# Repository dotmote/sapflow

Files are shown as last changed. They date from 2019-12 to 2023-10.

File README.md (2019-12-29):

# Sapflow Using the External Heat Ratio Method

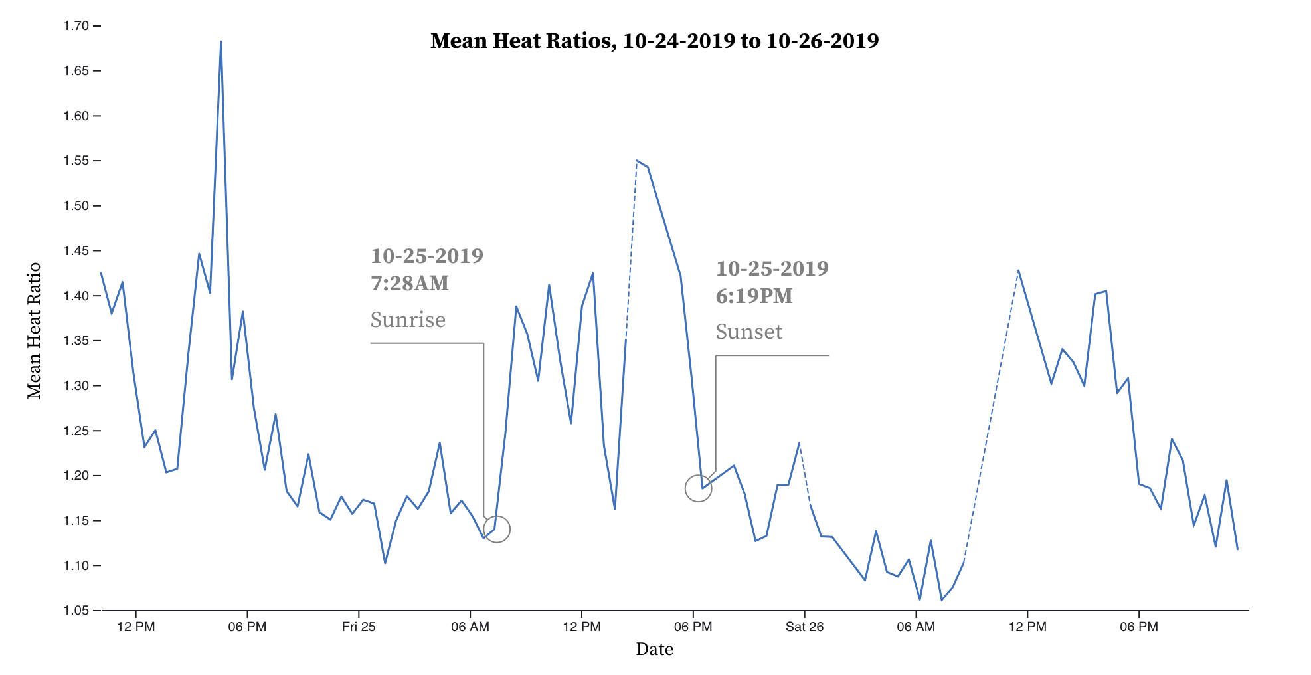
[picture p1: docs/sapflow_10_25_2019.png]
sapflow chart


So you want to measure sapflow in plants? You and me both, buddy. The goal of this project is to create an open-source, accurate, robust, low-cost, and low-power system to help answer the age-old question: "How is my plant doing?"

## Getting Started
Take a look at the hardware and software sections below for instructions on what you'll need to set up your own system and join in on improving the project.

## Hardware

### Sapflow Gauge
First, you'll need a way to measure and record the temperature at two specific points (equidistant from a central heating element) along the stem of your plant:

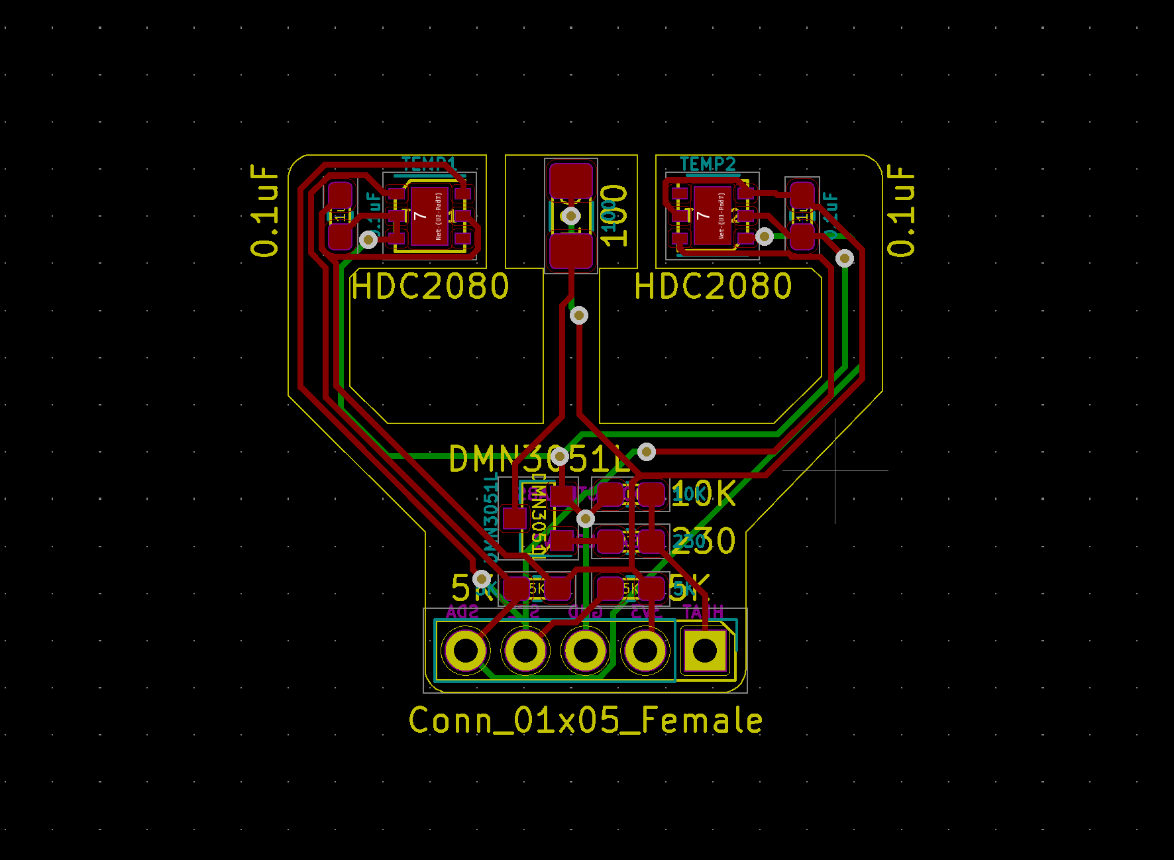
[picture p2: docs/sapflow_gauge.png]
sapflow gauge board


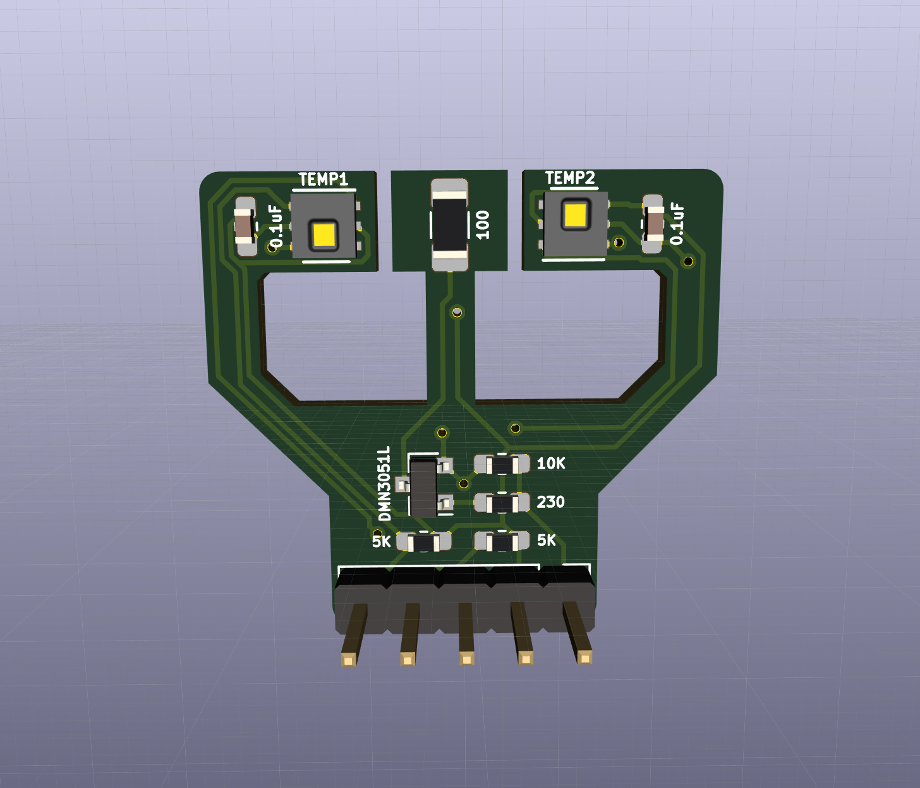
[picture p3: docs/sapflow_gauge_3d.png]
sapflow gauge 3d


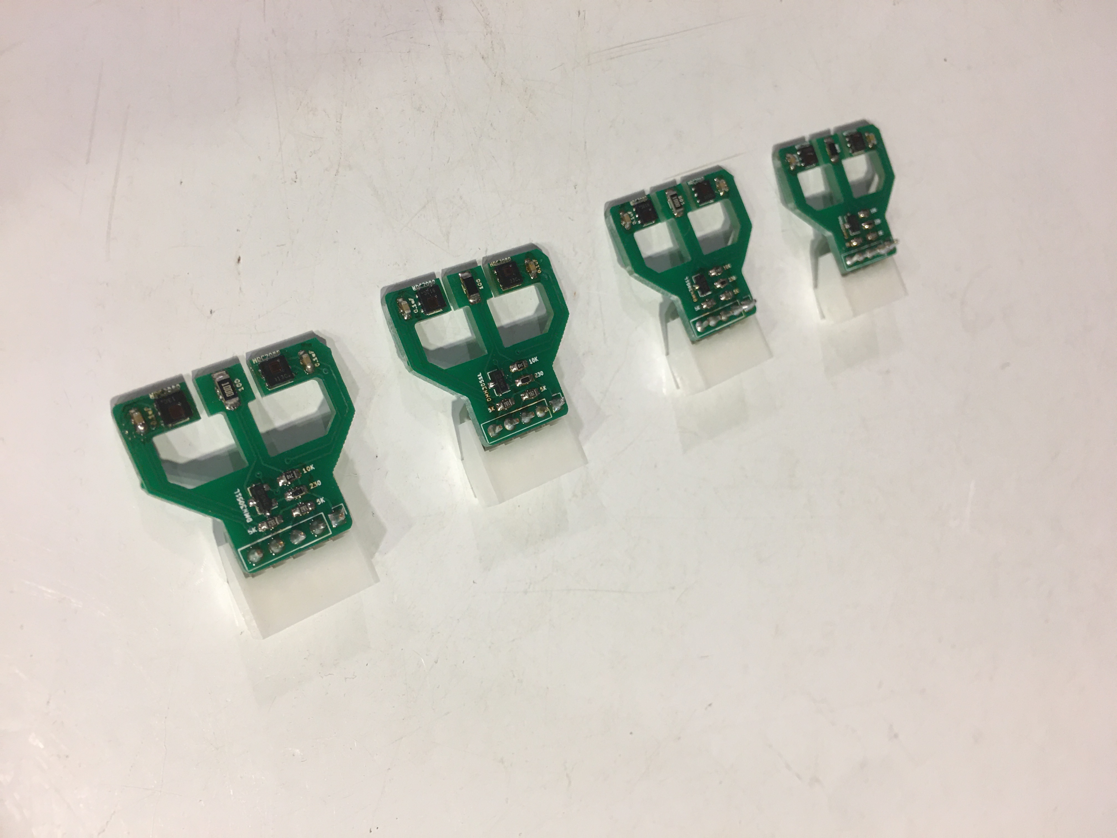
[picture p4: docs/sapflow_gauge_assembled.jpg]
assembled sapflow gauge


To build the gauge, you'll need: (1) the PCB; and (2) the components.

#### Fabricate the PCB
See here for the [KiCad PCB files](/hardware/sapflow_gauge/kicad/sapflow_gauge). Follow the directions from your favorite PCB fabrication service (e.g., OSHPark, JLCPCB, Seeed Studio, etc.), and order your desired quantity of PCBs.

#### Gather the Parts
See here for the [parts list](/hardware/sapflow_gauge/sapflow_gauge_parts.md). Go to your favorite electronic components distributor (e.g., Digikey, Arrow, Mouser, etc.) and order your desired quantity of components.

### Microcontroller
Second, you'll need a microcontroller that has an available GPIO pin (3.3V to 5V) and can communicate via I2C. We've found the ESP32 (specifically, the [LOLIN D32 Pro](https://www.aliexpress.com/item/32883116057.html) dev board) to be great for rapid prototyping with its relatively large onboard RAM, built-in WiFi, and low cost. For field experiments, it might make more sense to use a board with more low-power optimizations.

#### Microcontroller Shield
To reduce wiring, you might want to use a shield to interface your microcontroller with the sapflow gauge connector. See [here](/hardware/microcontroller_shield/d32_pro/d32_shield.md) for our shield design for the D32 Pro.

## Software

### Microcontroller Firmware
You'll need software running on your microcontroller to read data from the connected sapflow gauge. See [here](/software/microcontroller/d32_pro) for the Arduino code we used for the D32 Pro.

### Edge Compute Node
If you're using microcontrollers with WiFi connectivity, it's very convenient to have all of the data streaming into a single place. We like using a Raspberry Pi as an [MQTT](https://mosquitto.org/) broker, collecting data points from all of the networked sensor devices. See [here](/software/edge_compute_node/raspberry_pi) for more info.

## Data Visualization

Visualize your hard-earned data with this [Observable notebook](https://observablehq.com/d/a2d68ed97662840b).

Raw data:
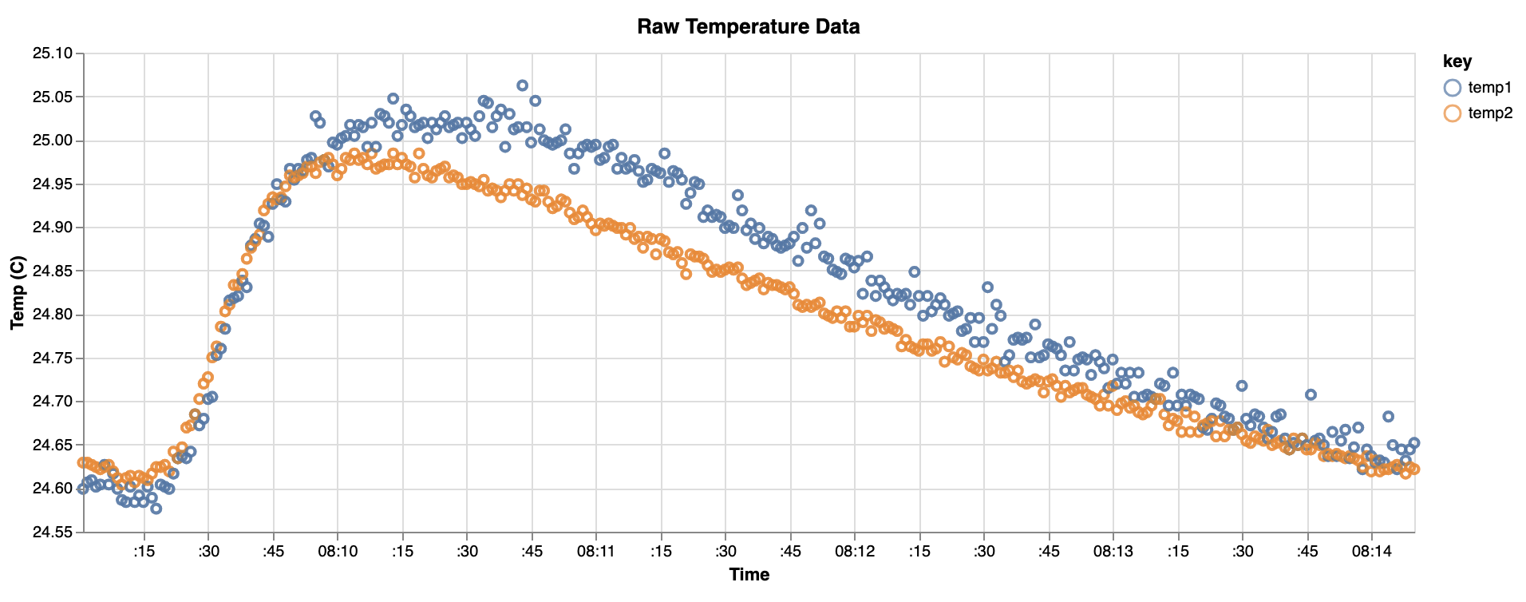
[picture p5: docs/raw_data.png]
sapflow raw data


After processing:
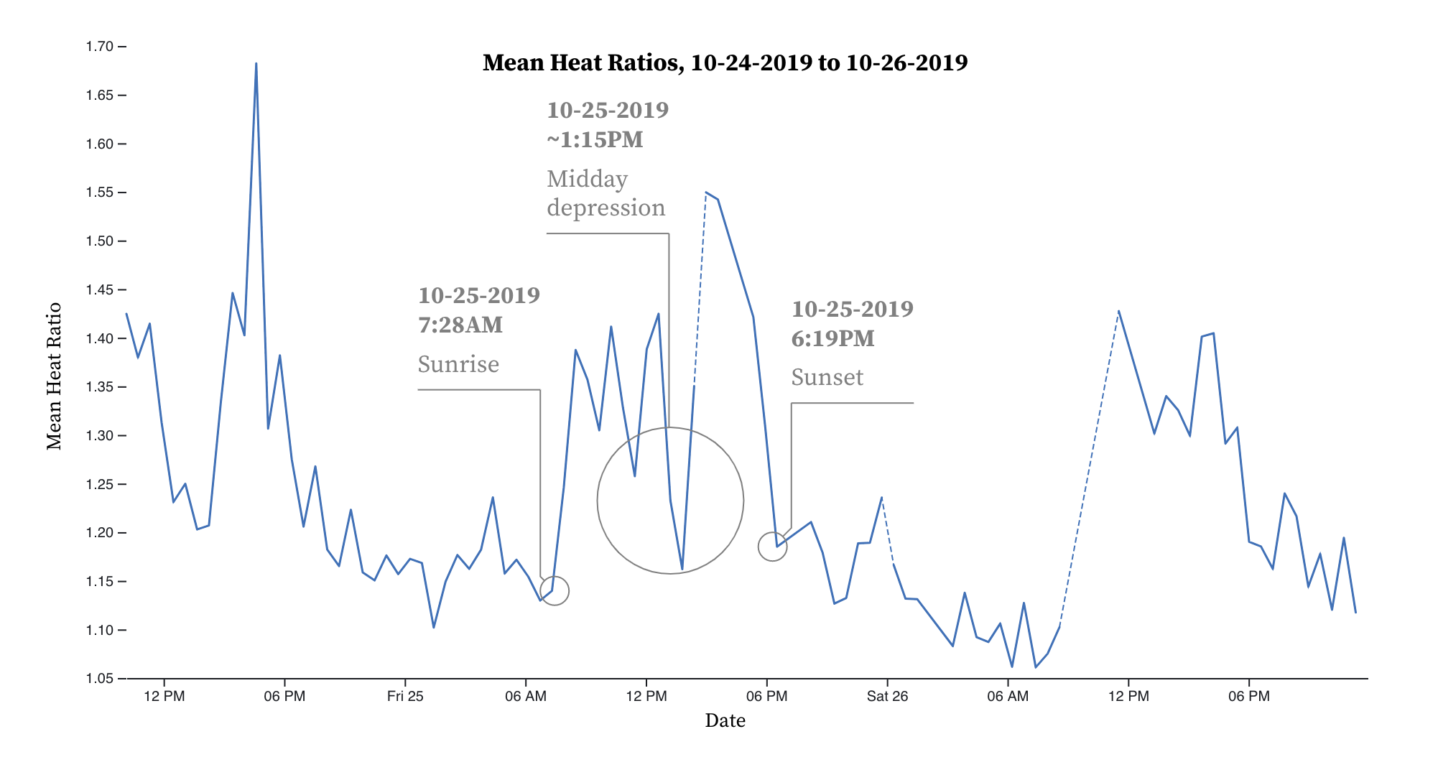
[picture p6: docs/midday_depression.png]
sapflow diurnal showing midday depression


## References
We've stood on the shoulders of countless giants in working on this project. Below is a non-exhaustive list of the many previous efforts that we drew heavily from (let us know who we've missed and we'll make sure to add them):

### Sapflow
- Burgess, S.S.O., Adams, M.A., Turner, N.C., Beverly, C.R., Ong, C.K., Khan, A.A.H., and Bleby, T.M. (2001). An improved heat pulse method to measure low and reverse rates of sap flow in woody plants. Tree Physiology 21, 589–598. 
- Clearwater, M.J., Luo, Z., Mazzeo, M., and Dichio, B. (2009). An external heat pulse method for measurement of sap flow through fruit pedicels, leaf petioles and other small-diameter stems. Plant, Cell & Environment 32, 1652–1663.
- Marshall, D.C. (1958). Measurement of Sap Flow in Conifers by Heat Transport. Plant Physiol. 33, 385–396.
- Skelton, R. (2017). Miniature External Sapflow Gauges and the Heat Ratio Method for Quantifying Plant Water Loss. BIO-PROTOCOL 7.

### Open-Source Research Tools
- Chris Lucani & Team @ Brodribb Lab, University of Tasmania: [Open Source OV](http://www.opensourceov.org/).
- OPEnS Lab, Oregon State University: [Sap Flow Meter](https://github.com/OPEnSLab-OSU/OPEnS-Lab-Home/wiki/Sap-Flow-Meter).

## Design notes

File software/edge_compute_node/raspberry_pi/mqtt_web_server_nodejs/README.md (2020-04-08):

# MQTT  + Web Server

## Overview
This script subscribes to the MQTT broker running on the Raspberry Pi and writes the incoming messages to CSV files in a `/data` directory, creating a new CSV file each hour. This script serves a web app at port 4000 of the Raspberry Pi's IP address (e.g., 192.168.1.2:4000). The web app can also be accessed at http://sapflow.local:4000 for devices that support mDNS.

## Setup and running the script
1. `cd` into the directory.
2. Run `$ npm install` to install the dependencies for this MQTT broker + web server.
3. Edit `.env.sample` and add your Dotmote API key.
4. Rename `.env.sample` to `.env`.
5. `$ cd frontend`.
6. Run `$ npm install` to install the dependencies for the web app.
7. Run `$ npm run build` to build the web app.
8. `cd ..` to return to the server directory.
9. Run `$ node index.js`.

## Running the script
1. Ensure that you are in the same directory as the script `index.js` to run the script

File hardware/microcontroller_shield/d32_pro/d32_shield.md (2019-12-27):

# D32 Pro Sapflow Shield
This shield's header pins are laid out to interface with:
- [Adafruit DS3231 RTC breakout](https://www.digikey.com/product-detail/en/adafruit-industries-llc/3013/1528-1598-ND/5875808)
- Sapflow gauge connector
- Soil moisture sensor

## GPIO
- IO26 = heating element on/off
- IO34 = soil moisture sensor analog read
- IO25 = soil moisture sensor digital alarm

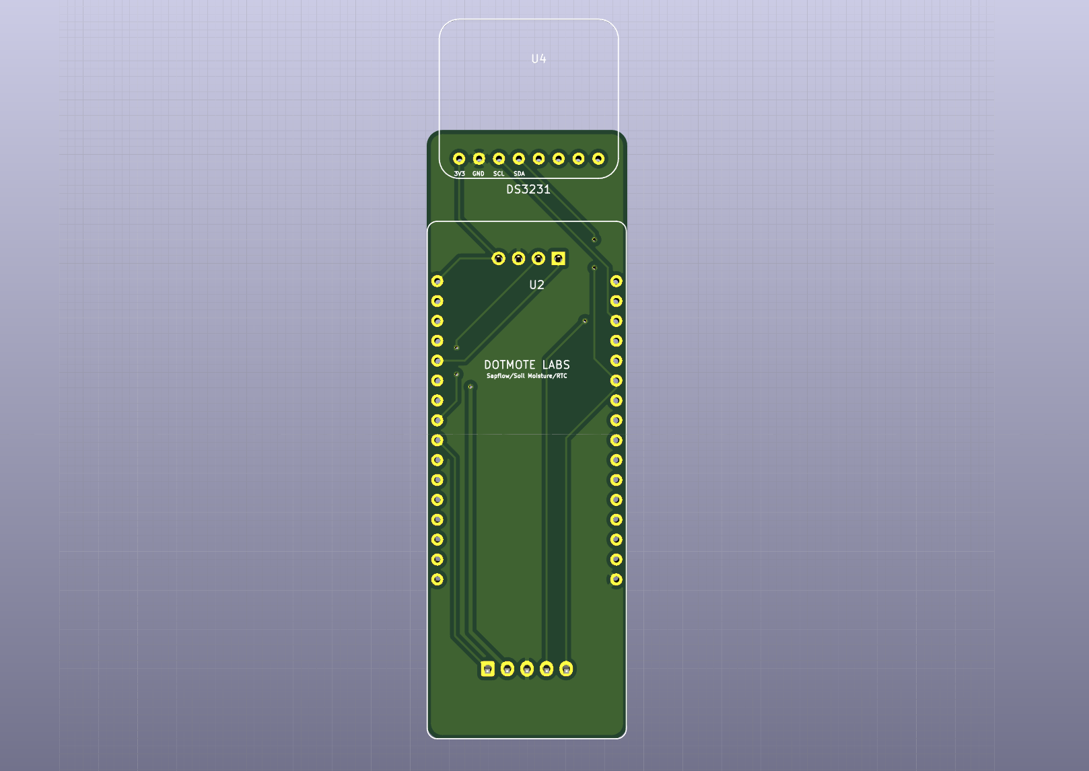
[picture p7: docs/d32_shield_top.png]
d32 pro sapflow shield top

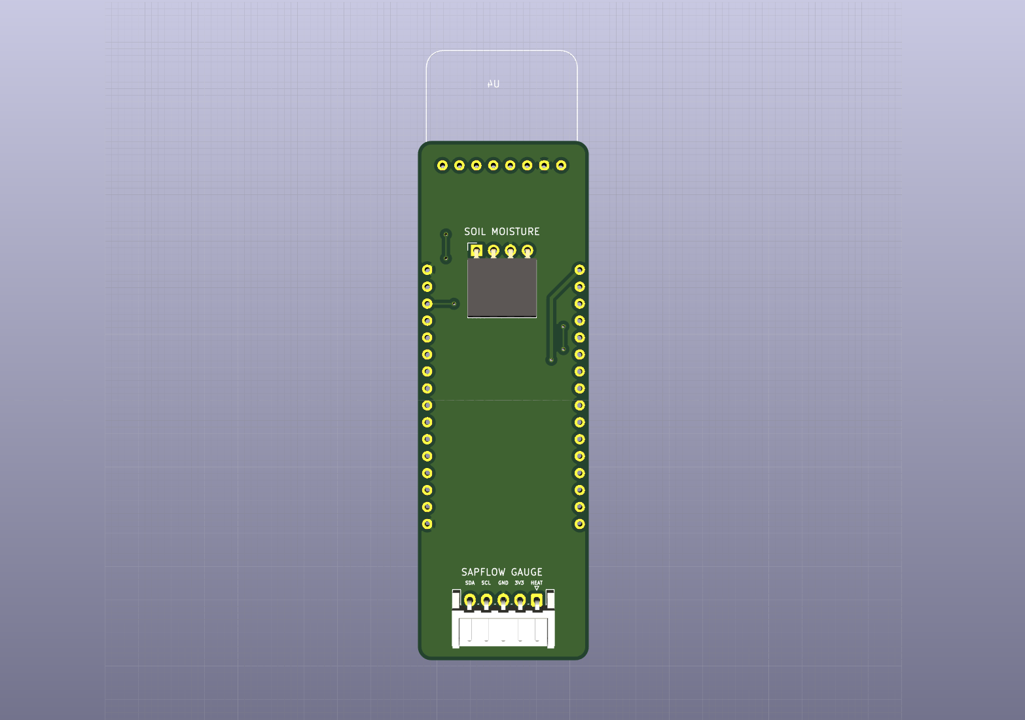
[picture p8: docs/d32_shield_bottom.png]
d32 pro sapflow shield bottom


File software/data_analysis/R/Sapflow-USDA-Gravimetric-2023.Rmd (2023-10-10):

---
title: "Sapflow - USDA Fieldtrial - August 2023"
author: "Aji John@DotMote Labs"
date: "08/20/2023"
output:
  pdf_document: default
  html_document: default
---

# Running notebook for the Sapflow data captured by Sapflow nodes (DotmoteLabs)

## 50 - Bowen F2 - Full irrigated
## 51 - Bowen F2 - Full irrigated
## 52 - Bowen F2 - Full irrigated

## 57 - Bowen L1 - Limited irrigation (70%)
## 58 - Bowen L1 - Limited irrigation (70%)
## 59 - Bowen L1 - Limited irrigation (70%)

```{r , include=FALSE}
knitr::opts_chunk$set(echo = TRUE)
```

## Introduction 

Sapflow measurements help with tree water use that can be extended to canopy level transpiration assessments.

```{r }
library(knitr)
library(tidyverse)
library(lubridate)
```

## Load helper functions

```{r, include=FALSE}
## Summarizes data.
## Gives count, mean, standard deviation, standard error of the mean, and confidence interval (default 95%).
##   data: a data frame.
##   measurevar: the name of a column that contains the variable to be summariezed
##   groupvars: a vector containing names of columns that contain grouping variables
##   na.rm: a boolean that indicates whether to ignore NA's
##   conf.interval: the percent range of the confidence interval (default is 95%)
summarySE <- function(data=NULL, measurevar, groupvars=NULL, na.rm=FALSE,
                      conf.interval=.95, .drop=TRUE) {
    library(plyr)

    # New version of length which can handle NA's: if na.rm==T, don't count them
    length2 <- function (x, na.rm=FALSE) {
        if (na.rm) sum(!is.na(x))
        else       length(x)
    }

    # This does the summary. For each group's data frame, return a vector with
    # N, mean, and sd
    datac <- ddply(data, groupvars, .drop=.drop,
      .fun = function(xx, col) {
        c(N    = length2(xx[[col]], na.rm=na.rm),
          mean = mean   (xx[[col]], na.rm=na.rm),
          sd   = sd     (xx[[col]], na.rm=na.rm)
        )
      },
      measurevar
    )

    # Rename the "mean" column    
    datac <- rename(datac, c("mean" = measurevar))

    datac$se <- datac$sd / sqrt(datac$N)  # Calculate standard error of the mean

    # Confidence interval multiplier for standard error
    # Calculate t-statistic for confidence interval: 
    # e.g., if conf.interval is .95, use .975 (above/below), and use df=N-1
    ciMult <- qt(conf.interval/2 + .5, datac$N-1)
    datac$ci <- datac$se * ciMult

    return(datac)
}

```

## Datalog

```{r pressure, echo=FALSE}
sapflow_usda_2023_datalog_51<-  read_csv('./data/usda/20230823/datalog.csv')
# Tell R studio that timestamp is already in MDT
sapflow_usda_2023_datalog_51$dateP <- as_datetime(sapflow_usda_2023_datalog_51$rtcUnixTimestamp, tz="America/Denver")

```

One day
```{r pressure, echo=FALSE}
 sapflow_usda_2023_datalog_51%>%
  mutate(mr = temp2/temp1) %>%
  mutate(node = as.factor(nodeId),Vh = log(mr),hr = hour(dateP),dy = day(dateP)) %>%
      filter(dy %in% c(14)) %>%
  #filter(nodeId %in% c("sapflow-dotmote-labs-2" ,"sapflow-dotmote-labs-3", "sapflow-dotmote-labs-4","sapflow-dotmote-labs-5")) %>%
  ggplot() + 
  geom_smooth(aes(hr,temp2) ,color="blue")  +
    geom_smooth(aes(hr,temp1) ,color="red")  +
  #facet_grid(~node) +
  theme_classic() + labs(x="Time (Hour)",y="Temperature (deg C)", title = "Node 51 USDA - Gravimetric Maize(2023)", caption="Source : dotmotelabs.com") +
    theme(axis.text.x = element_text(angle = 90, hjust = 1))
```

## Verify the input files of heat ratio

```{r pressure, echo=FALSE}
sapflow_usda_2023_hr_51<-  read_csv('./data/usda/20230823/heatlog.csv')
# Tell R studio that timestamp is already in MDT
sapflow_usda_2023_hr_51$dateP <- as_datetime(sapflow_usda_2023_hr_51$rtcUnixTimestamp, tz="America/Denver")
sapflow_usda_2023_hr_51$datePMinus90 <- as_datetime(sapflow_usda_2023_hr_51$rtcUnixTimestampMinus90, tz="America/Denver")

```

## Verify the input files

```{r pressure, echo=FALSE}

```

## Run summary analysis

```{r }
sapflow_usda_hr_2023 <-  rbind(sapflow_usda_2023_hr_51)

```

## Plot the raw heat ratio data 

```{r }
sapflow_usda_hr_2023 %>% mutate(meanhr = meanHeatRatio) %>%
  filter(!meanhr =='NaN') %>% mutate(mr=as.numeric(meanhr)) %>%
     mutate(node = as.factor(nodeId),Vh = log(mr),hr = hour(dateP),yr = year(dateP),dy = day(dateP)) %>%
   #  filter(date(dateP) > "2023-08-19" & date(dateP) < "2023-08-21" ) %>%
  #filter(nodeId %in% c("sapflow-dotmote-labs-2" ,"sapflow-dotmote-labs-3", "sapflow-dotmote-labs-4","sapflow-dotmote-labs-5")) %>%
  ggplot() + geom_point(aes(hr,1/mr,color=node) )  +
  facet_grid(~dy) +
  theme_classic() + labs(x="Date",y="Mean HR", title = "Node 51 USDA - Gravimetric Maize (2023)", caption="Source : dotmotelabs.com") +
    theme(axis.text.x = element_text(angle = 90, hjust = 1))
  
```
Lot oisier on 19,20 and 21

```{r }
sapflow_usda_hr_2023 %>% mutate(meanhr = meanHeatRatio) %>% filter(meanhr <5) %>%
  filter(!meanhr =='NaN') %>% mutate(mr=as.numeric(meanhr)) %>%
     mutate(node = as.factor(nodeId),Vh = log(mr),hr = hour(dateP),dy = day(dateP)) %>%
      filter(dy %in% c(14,15,16,17)) %>%
  #filter(nodeId %in% c("sapflow-dotmote-labs-2" ,"sapflow-dotmote-labs-3", "sapflow-dotmote-labs-4","sapflow-dotmote-labs-5")) %>%
  ggplot() + geom_point(aes(hr,1/mr,color=as.factor(dy)) )  +
  #facet_grid(~node) +
  theme_classic() + labs(x="Date",y="Mean HR", title = "Node 516 USDA - Gravimetric Maize(2023)", caption="Source : dotmotelabs.com") +
    theme(axis.text.x = element_text(angle = 90, hjust = 1))
  
```

## change the column names

```{r , echo=TRUE}
colnames(sapflow_usda_hr_2023) <- c("meanHeatRatio" ,"rtcUnixTimestamp", "rtcUnixTimestampMinus90", "nodeId" ,         "dateP" , "datePMinus90" )

```

## Verify diurnal 

## Do zero offsetting 

Plot alternatively, but do offsetting by zeroing out the heatratio by using the values from hrs 0,1 and 2. Assumption being around hours (0-2), ideally no sapflow in plants.

```{r , echo=TRUE}

usda_51_offset <- sapflow_usda_hr_2023 %>%  mutate(meanhr = meanHeatRatio,hr = hour(dateP) ,dy = day(dateP)) %>%
  filter(!meanhr =='NaN') %>% 
  filter(nodeId %in% c("sapflow-usda-51"))  %>% 
  filter( hr %in% c(0,1,2)) %>% 
  filter(dy %in% c(14,15,16,17)) %>%
  summarise(mhr = mean(meanhr))

sapflow_usda_2023_adjusted <- sapflow_usda_hr_2023
sapflow_usda_2023_adjusted$hr = hour(sapflow_usda_hr_2023$dateP)
sapflow_usda_2023_adjusted$mr <- 0

sapflow_usda_2023_adjusted[sapflow_usda_2023_adjusted$nodeId == "sapflow-usda-51",]$mr =  sapflow_usda_2023_adjusted[sapflow_usda_hr_2023$nodeId == "sapflow-usda-51",]$meanHeatRatio + (1-as.numeric(usda_51_offset))

#SE 
sapflow_usda_2023_adjusted_se <- summarySE(sapflow_usda_2023_adjusted, measurevar="mr", groupvars=c("nodeId","hr"))

# TODO VPD SE

```

## Plot the adjusted with original 

```{r , echo=TRUE}

sapflow_usda_hr_2023 %>% 
  mutate(node = as.factor(nodeId),hr = hour(dateP),dy = day(dateP)) %>%
  mutate(mr = meanHeatRatio) %>%
    filter(dy %in% c(14,15,16,17)) %>%
  ggplot() + geom_point(aes(hr,1/mr,color=node) )  +
  facet_grid(~nodeId) +
  theme_classic() + labs(x="Date",y="Mean HR", title = "Node 7-10 USDA - Gravimetric Maize", caption="Source : dotmotelabs.com") +
    theme(axis.text.x = element_text(angle = 90, hjust = 1))

```

```{r , echo=TRUE}

sapflow_usda_2023_adjusted %>% filter(1/mr >0) %>%
  mutate(node = as.factor(nodeId),hr = hour(dateP),dy = day(dateP)) %>%
     filter(dy %in% c(14,15,16,17)) %>%
  ggplot() + geom_point(aes(hr,1/mr,color=node) )  +
  facet_grid(~nodeId) +
  theme_classic() + labs(x="Date",y="Mean HR", title = "Node 7-10 USDA - Gravimetric Maize", caption="Source : dotmotelabs.com") +
    theme(axis.text.x = element_text(angle = 90, hjust = 1))

```

## Compare Original and Adjusted HR

```{r , echo=TRUE}

summary(lm(sapflow_usda_2023_adjusted$meanHeatRatio~sapflow_usda_2023_adjusted$mr))

sapflow_usda_2023_adjusted %>% 
  ggplot() +
  geom_point(aes(meanHeatRatio,mr,color=nodeId)) +
  theme_minimal(base_size = 14)
```

## Heat pulse velocity

```{r , echo=TRUE}

sapflow_usda_2023_adjusted %>% mutate(yr = year(dateP),mth = month(dateP),dy  = day(dateP),hr = hour(dateP)) %>%
  filter(yr %in% c(2023) & mth %in% c(08) & dy %in% c(14:17)) %>%
  mutate (sv = log(1/mr) *3600 * (0.0025/0.6) ,daten = date(dateP))%>% 
#        filter(date(dateP) == "2020-12-01" ) %>%
 # filter(nodeId=="sapflow-dotmote-labs-2" )  %>% 
  ggplot() +
   geom_point(aes(x = dateP, y=sv,color=nodeId)) +
   geom_line(aes(x = dateP, y=sv,color=nodeId)) +
    theme_minimal() + scale_x_datetime(date_minor_breaks = "1 day") + 

  scale_y_continuous(
    # Features of the first axis
    name = expression(~V[h] (cm~h^{"-1"}))

  ) +
  facet_wrap(.~dy) +
  theme(legend.position = c(.17, .6))+
guides(fill = guide_legend(keywidth = 1, keyheight = 1),
    linetype=guide_legend(keywidth = 3, keyheight = 1))

```
## Smooth

```{r , echo=TRUE}

sapflow_usda_2023_adjusted %>% mutate(yr = year(dateP),mth = month(dateP),dy  = day(dateP)) %>%
  filter(yr %in% c(2023) & mth %in% c(08) & dy %in% c(14:17)) %>%
  mutate (sv = log(1/mr) *3600 * (0.0025/0.6) ,daten = date(dateP))%>%
  #filter(date(dateP) == "2021-03-20" ) %>%
 # filter(nodeId=="sapflow-dotmote-labs-2" )  %>% 
  ggplot() +
   geom_point(aes(x = hr, y=sv,color=nodeId)) +
  geom_smooth(aes(x = hr, y=sv,color=nodeId)) +
    theme_minimal() + 
  #scale_x_datetime(date_minor_breaks = "1 day") + 

  scale_y_continuous(
    # Features of the first axis
    name = expression(~V[h] (cm~h^{"-1"}))

  ) +
  facet_wrap(~date(dateP) ) +

  theme(legend.position = "bottom")+
guides(fill = guide_legend(keywidth = 1, keyheight = 1),
    linetype=guide_legend(keywidth = 3, keyheight = 1))
ggsave("figs/usda-graivimetric-Maize-vh-smoothed-2023.png", width = 20, height = 20, units = "cm")

```

## Heat pulse velocity 1 to 15

```{r , echo=TRUE}

sapflow_usda_2023_adjusted %>% mutate(yr = year(dateP),mth = month(dateP),dy  = day(dateP)) %>%
  filter(yr %in% c(2023) & mth %in% c(08) & dy %in% c(14:17)) %>%
  mutate (sv = log(1/mr) *3600 * (0.0025/0.6) ,daten = date(dateP))%>%
#        filter(date(dateP) == "2020-12-01" ) %>%
  #        filter(date(dateP) >= "2021-12-15" ) %>%
  # filter(date(dateP) <= "2021-12-24" ) %>%
 # filter(nodeId=="sapflow-dotmote-labs-2" )  %>% 
  ggplot() +
   geom_point(aes(x = dateP, y=sv,color=nodeId)) +
   geom_line(aes(x = dateP, y=sv,color=nodeId)) +
    theme_minimal() + scale_x_datetime(date_minor_breaks = "1 day") + 

  scale_y_continuous(
    # Features of the first axis
    name = expression(~V[h] (cm~h^{"-1"}))

  ) +
  theme(legend.position = c(.17, .6))+
    labs(color='Node ID',x="Time (Date)") +
guides(fill = guide_legend(keywidth = 1, keyheight = 1),
    linetype=guide_legend(keywidth = 3, keyheight = 1))
ggsave("figs/usda-graivimetric-Maize-stress-event-2023.png", width = 20, height = 20, units = "cm")

```

## Mass flow

```{r , echo=TRUE}

sapflow_usda_2023_adjusted %>% mutate(yr = year(dateP),mth = month(dateP),dy  = day(dateP)) %>%
  filter(yr %in% c(2023) & mth %in% c(08) & dy %in% c(14:17)) %>%
  mutate (sv = log(1/mr) *3600 * (0.0025/0.6) ,daten = date(dateP))%>%
            filter(date(dateP) >= "2021-12-15" ) %>%
 #  filter(date(dateP) <= "2021-12-24" ) %>%
   mutate (vs =1.7 * sv )%>% 
   mutate (flow = 3.14 * (1.5)^2 *vs )%>% 
   #     filter(date(dateP) == "2021-03-18" ) %>%
 # filter(nodeId=="sapflow-dotmote-labs-2" )  %>% 
  ggplot() +
   geom_point(aes(x = dateP, y=flow,color=nodeId)) +
   geom_line(aes(x = dateP, y=flow,color=nodeId)) +
    theme_minimal() + scale_x_datetime(date_minor_breaks = "1 day") + 

  scale_y_continuous(
    # Features of the first axis
    #name = expression(~V[h] (cm~h^{"-1"}))
       # Features of the first axis
    name = expression("Sapflow rate"~J~(g~h^{"-1"})),
  ) +
  theme(legend.position = c(.17, .8))+
  labs(color='Node ID',x="Time (Date)") +
guides(fill = guide_legend(keywidth = 1, keyheight = 1),
    linetype=guide_legend(keywidth = 3, keyheight = 1))

```

## Look at one day

## Mass flow

```{r , echo=TRUE}

sapflow_usda_2023_adjusted %>% mutate(yr = year(dateP),mth = month(dateP),dy  = day(dateP)) %>%
  filter(yr %in% c(2023) & mth %in% c(08) & dy %in% c(15:15)) %>%
  mutate (sv = log(1/mr) *3600 * (0.0025/0.6) ,daten = date(dateP))%>%
   #         filter(date(dateP) >= "2021-12-18" ) %>%
   #filter(date(dateP) <= "2021-12-18" ) %>%
   mutate (vs =1.7 * sv )%>% 
   mutate (flow = 3.14 * (1.5)^2 *vs )%>% mutate(ihr = 1/mr) %>% filter( ihr >= 1) %>%
   #     filter(date(dateP) == "2021-03-18" ) %>%
 # filter(nodeId=="sapflow-dotmote-labs-2" )  %>% 
  ggplot() +
   geom_point(aes(x = dateP, y=flow,color=nodeId)) +
   geom_line(aes(x = dateP, y=flow,color=nodeId)) +
    theme_minimal() + scale_x_datetime(date_minor_breaks = "1 day") + 

  scale_y_continuous(
    # Features of the first axis
    #name = expression(~V[h] (cm~h^{"-1"}))
       # Features of the first axis
    name = expression("Sapflow rate"~J~(g~h^{"-1"})),
  ) +
  theme(legend.position = c(.17, .8))+
  labs(color='Node ID',x="Time (Date)") +
guides(fill = guide_legend(keywidth = 1, keyheight = 1),
    linetype=guide_legend(keywidth = 3, keyheight = 1))

```

## Smooth

## Mass flow

```{r , echo=TRUE}

sapflow_usda_2023_adjusted %>% mutate(yr = year(dateP),mth = month(dateP),dy  = day(dateP)) %>%
  filter(yr %in% c(2023) & mth %in% c(08) & dy %in% c(15:15)) %>%
  mutate (sv = log(1/mr) *3600 * (0.0025/0.6) ,daten = date(dateP))%>%
  #          filter(date(dateP) >= "2021-12-18" ) %>%
 #  filter(date(dateP) <= "2021-12-18" ) %>%
   mutate (vs =1.7 * sv )%>% 
   mutate (flow = 3.14 * (1.5)^2 *vs )%>% mutate(ihr = 1/mr) %>% filter( ihr >= 1) %>%
   #     filter(date(dateP) == "2021-03-18" ) %>%
 # filter(nodeId=="sapflow-dotmote-labs-2" )  %>% 
  ggplot() +
   geom_point(aes(x = dateP, y=flow,color=nodeId)) +
   geom_smooth(aes(x = dateP, y=flow,color=nodeId)) +
    theme_minimal() + scale_x_datetime(date_minor_breaks = "1 day") + 

  scale_y_continuous(
    # Features of the first axis
    #name = expression(~V[h] (cm~h^{"-1"}))
       # Features of the first axis
    name = expression("Sapflow rate"~J~(g~h^{"-1"})),
  ) +
  theme(legend.position = c(.17, .8))+
  labs(color='Node ID',x="Time (Date)") +
guides(fill = guide_legend(keywidth = 1, keyheight = 1),
    linetype=guide_legend(keywidth = 3, keyheight = 1))

```
# Multiple dates

```{r , echo=TRUE}

sapflow_usda_2023_adjusted %>% mutate(yr = year(dateP),mth = month(dateP),dy  = day(dateP)) %>%
  filter(yr %in% c(2023) & mth %in% c(08) & dy %in% c(14:18)) %>%
  mutate (sv = log(1/mr) *3600 * (0.0025/0.6) ,daten = date(dateP))%>%
    #        filter(date(dateP) >= "2021-12-15" ) %>%
   #filter(date(dateP) <= "2021-12-28" ) %>%
   mutate (vs =1.7 * sv )%>% 
   mutate (flow = 3.14 * (1.5)^2 *vs )%>% mutate(ihr = 1/mr) %>% filter( ihr >= 1) %>%
   #     filter(date(dateP) == "2021-03-18" ) %>%
 # filter(nodeId=="sapflow-dotmote-labs-2" )  %>% 
  ggplot() +
   geom_point(aes(x = dateP, y=flow,color=nodeId)) +
   geom_line(aes(x = dateP, y=flow,color=nodeId)) +
    theme_minimal(base_size = 18) +
  scale_x_datetime(date_breaks = "1 day",date_labels = "%b %d") + 
  scale_y_continuous(
    # Features of the first axis
    #name = expression(~V[h] (cm~h^{"-1"}))
       # Features of the first axis
    name = expression("Sapflow rate"~J~(g~h^{"-1"})),
  ) +
  #  facet_wrap(~date(dateP) ) +
  theme_minimal(base_size = 18) +
  theme(legend.position = c(.17, .8))+
  labs(color='Node ID',x="Time (Date)" , caption="Source : dotmotelabs.com") +
guides(fill = guide_legend(keywidth = 1, keyheight = 1),
    linetype=guide_legend(keywidth = 3, keyheight = 1))

ggsave("figs/usda-graivimetric-Maize-flow-long-duration-2023.jpg", width = 35, height = 20, units = "cm")

```

```{r , echo=TRUE}

sapflow_usda_2023_adjusted %>% mutate(yr = year(dateP),mth = month(dateP),dy  = day(dateP)) %>%
  filter(yr %in% c(2023) & mth %in% c(08) & dy %in% c(14:18)) %>%
  mutate (sv = log(1/mr) *3600 * (0.0025/0.6) ,daten = date(dateP))%>%
  #          filter(date(dateP) >= "2021-12-15" ) %>%
  # filter(date(dateP) <= "2021-12-24" ) %>%
   mutate (vs =1.7 * sv )%>% 
   mutate (flow = 3.14 * (1.5)^2 *vs )%>%  mutate(ihr = 1/mr) %>% filter( ihr >= 1) %>%
   #     filter(date(dateP) == "2021-03-18" ) %>%
 # filter(nodeId=="sapflow-dotmote-labs-2" )  %>% 
  ggplot() +
   geom_point(aes(x = dateP, y=1/mr,color=nodeId)) +
   geom_line(aes(x = dateP, y=1/mr,color=nodeId)) +
    theme_minimal() + scale_x_datetime(date_minor_breaks = "1 day") + 

  scale_y_continuous(
    # Features of the first axis
    #name = expression(~V[h] (cm~h^{"-1"}))
       # Features of the first axis
    name = expression("Mean Heat ratio"),
  ) +
  theme(legend.position = c(.17, .8))+
  labs(color='Node ID',x="Time (Date)") +
guides(fill = guide_legend(keywidth = 1, keyheight = 1),
    linetype=guide_legend(keywidth = 3, keyheight = 1))

```

# check the remaining 

```{r pressure, echo=FALSE}
sapflow_usda_2023_hr_50_repro<-  read_csv('./data/usda/reprocessed-2023/sapflow-usda-50.csv')
# Tell R studio that timestamp is already in MDT
sapflow_usda_2023_hr_50_repro$dateP <- as_datetime(sapflow_usda_2023_hr_50_repro$date, tz="America/Denver")

sapflow_usda_2023_hr_51_repro<-  read_csv('./data/usda/reprocessed-2023/sapflow-usda-51.csv')
# Tell R studio that timestamp is already in MDT
sapflow_usda_2023_hr_51_repro$dateP <- as_datetime(sapflow_usda_2023_hr_51_repro$date, tz="America/Denver")

sapflow_usda_2023_hr_52_repro<-  read_csv('./data/usda/reprocessed-2023/sapflow-usda-52.csv')
# Tell R studio that timestamp is already in MDT
sapflow_usda_2023_hr_52_repro$dateP <- as_datetime(sapflow_usda_2023_hr_52_repro$date, tz="America/Denver")

sapflow_usda_2023_hr_57_repro<-  read_csv('./data/usda/reprocessed-2023/sapflow-usda-57.csv')
# Tell R studio that timestamp is already in MDT
sapflow_usda_2023_hr_57_repro$dateP <- as_datetime(sapflow_usda_2023_hr_57_repro$date, tz="America/Denver")

sapflow_usda_2023_hr_58_repro<-  read_csv('./data/usda/reprocessed-2023/sapflow-usda-58.csv')
# Tell R studio that timestamp is already in MDT
sapflow_usda_2023_hr_58_repro$dateP <- as_datetime(sapflow_usda_2023_hr_58_repro$date, tz="America/Denver")

sapflow_usda_2023_hr_59_repro<-  read_csv('./data/usda/reprocessed-2023/sapflow-usda-59.csv')
# Tell R studio that timestamp is already in MDT
sapflow_usda_2023_hr_59_repro$dateP <- as_datetime(sapflow_usda_2023_hr_59_repro$date, tz="America/Denver")

```

```{r , echo=TRUE}

sapflow_usda_2023_hr_50_repro %>% 
  mutate(node = as.factor(nodeID),hr = hour(dateP),dy = day(dateP)) %>%
  mutate(mr = meanHeatRatio) %>%
    filter(dy %in% c(14,15,16,17,18)) %>%
  ggplot() + geom_point(aes(hr,1/mr,color=node) )  +
 facet_grid(~dy) +
  theme_classic() + labs(x="Date",y="Mean HR", title = "Node 50 - Gravimetric Maize", caption="Source : dotmotelabs.com") +
    theme(axis.text.x = element_text(angle = 90, hjust = 1))

```
```{r , echo=TRUE}

sapflow_usda_2023_hr_51_repro %>% 
  mutate(node = as.factor(nodeID),hr = hour(dateP),dy = day(dateP)) %>%
  mutate(mr = meanHeatRatio) %>%
    filter(dy %in% c(14,15,16,17,18)) %>%
  ggplot() + geom_point(aes(hr,1/mr,color=node) )  +
 facet_grid(~dy) +
  theme_classic() + labs(x="Date",y="Mean HR", title = "Node 51 - Gravimetric Maize", caption="Source : dotmotelabs.com") +
    theme(axis.text.x = element_text(angle = 90, hjust = 1))

```
```{r , echo=TRUE}

sapflow_usda_2023_hr_52_repro %>% 
  mutate(node = as.factor(nodeID),hr = hour(dateP),dy = day(dateP)) %>%
  mutate(mr = meanHeatRatio) %>%
    filter(dy %in% c(14,15,16,17,18)) %>%
  ggplot() + geom_point(aes(hr,1/mr,color=node) )  +
  facet_grid(~dy) +
  theme_classic() + labs(x="Date",y="Mean HR", title = "Node 52 - Gravimetric Maize", caption="Source : dotmotelabs.com") +
    theme(axis.text.x = element_text(angle = 90, hjust = 1))

```
```{r , echo=TRUE}

sapflow_usda_2023_hr_57_repro %>% 
  mutate(node = as.factor(nodeID),hr = hour(dateP),dy = day(dateP)) %>%
  mutate(mr = meanHeatRatio) %>%
    filter(dy %in% c(14,15,16,17,18)) %>%
  ggplot() + geom_point(aes(hr,1/mr,color=node) )  +
  facet_grid(~dy) +
  theme_classic() + labs(x="Date",y="Mean HR", title = "Node 57 - Gravimetric Maize", caption="Source : dotmotelabs.com") +
    theme(axis.text.x = element_text(angle = 90, hjust = 1))

```
```{r , echo=TRUE}

sapflow_usda_2023_hr_58_repro %>% 
  mutate(node = as.factor(nodeID),hr = hour(dateP),dy = day(dateP)) %>%
  mutate(mr = meanHeatRatio) %>%
    filter(dy %in% c(14,15,16,17,18)) %>%
  ggplot() + geom_point(aes(hr,1/mr,color=node) )  +
  facet_grid(~dy) +
  theme_classic() + labs(x="Date",y="Mean HR", title = "Node 58 - Gravimetric Maize", caption="Source : dotmotelabs.com") +
    theme(axis.text.x = element_text(angle = 90, hjust = 1))

```

```{r , echo=TRUE}

sapflow_usda_2023_hr_59_repro %>% 
  mutate(node = as.factor(nodeID),hr = hour(dateP),dy = day(dateP)) %>%
  mutate(mr = meanHeatRatio) %>%
    filter(dy %in% c(14,15,16,17,18)) %>%
  ggplot() + geom_point(aes(hr,1/mr,color=node) )  +
  facet_grid(~dy) +
  theme_classic() + labs(x="Date",y="Mean HR", title = "Node 59 - Gravimetric Maize", caption="Source : dotmotelabs.com") +
    theme(axis.text.x = element_text(angle = 90, hjust = 1))

```
## combine all the records
```{r , echo=TRUE}
field_repro_all_aug_2023 <- rbind ( sapflow_usda_2023_hr_50_repro, sapflow_usda_2023_hr_51_repro, sapflow_usda_2023_hr_52_repro,
                                    sapflow_usda_2023_hr_57_repro,sapflow_usda_2023_hr_58_repro,sapflow_usda_2023_hr_59_repro)

field_repro_all_aug_2023$datePbythree <- field_repro_all_aug_2023$dateP
# Advance by 3 hours 60*1*60*2
field_repro_all_aug_2023[field_repro_all_aug_2023$nodeID=='sapflow-usda-50',]$datePbythree <- (field_repro_all_aug_2023[field_repro_all_aug_2023$nodeID=='sapflow-usda-50',]$dateP + 10800)

# Advance by 6 hours 60*1*60*2
field_repro_all_aug_2023[field_repro_all_aug_2023$nodeID=='sapflow-usda-51',]$datePbythree <- (field_repro_all_aug_2023[field_repro_all_aug_2023$nodeID=='sapflow-usda-51',]$dateP + 20800)

# Advance by 9 hours 60*1*60*2
field_repro_all_aug_2023[field_repro_all_aug_2023$nodeID=='sapflow-usda-57',]$datePbythree <- (field_repro_all_aug_2023[field_repro_all_aug_2023$nodeID=='sapflow-usda-57',]$dateP + 35800)

```

## RRplot
```{r , echo=TRUE}

field_repro_all_aug_2023 %>% 
  mutate(node = as.factor(nodeID),hr = hour(datePbythree),dy = day(datePbythree)) %>%
  mutate(hrp = hour(dateP)) %>%
  mutate(mr = meanHeatRatio) %>%
  filter(node == 'sapflow-usda-50') %>%
  #filter(dy %in% c(14)) %>%
    filter(dy %in% c(14,15,16,17,18)) %>%
  ggplot() + 
  geom_point(aes(hr,1/mr,color=node) )  +
  #geom_point(aes(hrp,1/mr,color='blue') )  +
 facet_grid(~dy) +
  theme_classic() + labs(x="Date",y="Mean HR", title = "Node 50 - Gravimetric Maize", caption="Source : dotmotelabs.com") +
  scale_x_continuous(breaks = c(0:24)) +
    theme(axis.text.x = element_text(angle = 90, hjust = 1))

```
##Plot the raw data

```{r , echo=TRUE}

field_repro_all_aug_2023 %>% 
  mutate(node = as.factor(nodeID),hr = hour(datePbythree),dy = day(datePbythree)) %>%
  mutate(hrp = hour(dateP)) %>%
  mutate(mr = meanHeatRatio) %>%
  filter(node %in% c('sapflow-usda-50','sapflow-usda-51','sapflow-usda-57')) %>%
 #filter(dy %in% c(18)) %>%
   filter(dy %in% c(14,15,16,17)) %>%
  ggplot() + 
  geom_smooth(aes(hr,1/mr,color=node) )  +
  #geom_point(aes(hrp,1/mr,color='blue') )  +
 facet_grid(~dy) +
  theme_classic() + labs(x="Date",y="Mean HR", title = "Node 50 - Gravimetric Maize", caption="Source : dotmotelabs.com") +
  scale_x_continuous(breaks = c(0:24)) +
    theme(axis.text.x = element_text(angle = 90, hjust = 1))

```
## Pstc comparison
```{r , echo=TRUE}

sapflow_usda_2023_psy1limited<-  read_csv('./data/usda/psy1/PSY11AOF-limited.csv')
sapflow_usda_2023_psy1limited %>% 
  mutate(datep = as_datetime(`Date and Time`,format="%m/%d/%y %H:%M")) %>% 
    mutate(wp = `Corrected Water Potential (MPa)`) %>% 
  mutate(dy = day(datep), mth=month(datep),hr=hour(datep)) %>%
  filter(dy %in% c(21:24)) %>%
  ggplot() +
   geom_point(aes(datep,wp)) +
     facet_wrap(vars(dy))

wpthreedayslimited <- sapflow_usda_2023_psy1limited %>% 
  mutate(datep = as_datetime(`Date and Time`,format="%m/%d/%y %H:%M")) %>% 
    mutate(wp = `Corrected Water Potential (MPa)`) %>% 
  mutate(dy = day(datep), mth=month(datep),hr=hour(datep)) %>%
  filter(dy %in% c(21:23)) %>%
  dplyr::group_by(mth,dy,hr) %>%
  dplyr::summarise(mwp = mean(wp)) %>%
  as.data.frame()
```
## Med full
```{r , echo=TRUE}

sapflow_usda_2023_psy1medfull<-  read_csv('./data/usda/psy1/LIRF-Psy3-medfull.csv')
sapflow_usda_2023_psy1medfull %>% 
  mutate(datep = as_datetime(`Date and Time`,format="%m/%d/%y %H:%M")) %>% 
    mutate(wp = `Corrected Water Potential (MPa)`) %>% 
    mutate(dy = day(datep), mth=month(datep),hr=hour(datep)) %>%
  filter(dy %in% c(22:23)) %>%
  ggplot() +
   geom_point(aes(datep,wp)) +
     facet_wrap(vars(dy))

wpthreedaysmedfull <- sapflow_usda_2023_psy1medfull %>% 
  mutate(datep = as_datetime(`Date and Time`,format="%m/%d/%y %H:%M")) %>% 
    mutate(wp = `Corrected Water Potential (MPa)`) %>% 
  mutate(dy = day(datep), mth=month(datep),hr=hour(datep)) %>%
  filter(dy %in% c(21:23)) %>%
  dplyr::group_by(mth,dy,hr) %>%
  dplyr::summarise(mwp = mean(wp)) %>%
  as.data.frame()

```
## base full
```{r , echo=TRUE}

sapflow_usda_2023_psy1basefull<-  read_csv('./data/usda/psy1/LIRF-Psy2-basefull.csv')
sapflow_usda_2023_psy1basefull %>% 
  mutate(datep = as_datetime(`Date and Time`,format="%m/%d/%y %H:%M")) %>% 
    mutate(wp = `Corrected Water Potential (MPa)`) %>% 
    mutate(dy = day(datep), mth=month(datep),hr=hour(datep)) %>%
  filter(dy %in% c(22:23)) %>%
  ggplot() +
   geom_point(aes(datep,wp)) +
     facet_wrap(vars(dy))

wpthreedaysbasefull <- sapflow_usda_2023_psy1basefull %>% 
  mutate(datep = as_datetime(`Date and Time`,format="%m/%d/%y %H:%M")) %>% 
    mutate(wp = `Corrected Water Potential (MPa)`) %>% 
  mutate(dy = day(datep), mth=month(datep),hr=hour(datep)) %>%
  filter(dy %in% c(21:23)) %>%
  dplyr::group_by(mth,dy,hr) %>%
  dplyr::summarise(mwp = mean(wp)) %>%
  as.data.frame()

# 72 rows

```
## water pote
```{r , echo=TRUE}

sapflow_usda_2023_waterpotentials<-  read_csv('./data/usda/psy1/LIRF-waterpotentials.csv')
sapflow_usda_2023_waterpotentials %>% 
  mutate(datep = as_datetime(`Date and Time`,format="%m/%d/%y %H:%M")) %>% 
    mutate(wp = `Corrected Water Potential (MPa)`) %>% 
  mutate(dy = day(datep),hr = hour(datep),mth=month(datep) )%>%
  filter(dy %in% c(22:23)) %>%
  ggplot() +
   geom_point(aes(datep,wp)) +
     facet_wrap(vars(dy))

```
# get the weather

```{r , echo=TRUE}

sapflow_usda_2023_5minweather<-  read_csv('./data/usda/weather/CoAgMet_2023_LIRF_Data_w_VPD_July_15_to_Sep12_5min (1).csv')
sapflow_usda_2023_5minweatherbst <- sapflow_usda_2023_5minweather %>% 
  mutate(dy = day(TIMESTAMP_MST),hr = hour(TIMESTAMP_MST),mth = month(TIMESTAMP_MST)) %>% as.data.frame()

sapflow_usda_2023_hourlyweather <- sapflow_usda_2023_5minweatherbst %>% dplyr::group_by(mth,dy,hr) %>%
  dplyr::summarise(hrlyvpd = mean(VPD), 
                   hrlytemp = mean(AirTemp_Avg_C),
                   hrlyrh = mean(RH_Avg_fraction),
                   hrlysr = mean(SolRad_W_m2),
                   hrlyrain = mean(Rain_Tot_mm)) %>%
  as.data.frame()
```

# vpd
```{r , echo=TRUE}
sapflow_usda_2023_hourlyweather %>% 
 filter(mth %in% c(8)) %>%
  filter(dy %in% c(21:25)) %>%
  ggplot() +
   geom_point(aes(hr,hrlyvpd)) +
    # facet_wrap(vars(dy))
  facet_grid(~dy) 
```

# solar radiation
```{r , echo=TRUE}
sapflow_usda_2023_hourlyweather %>% 
 filter(mth %in% c(8)) %>%
  filter(dy %in% c(21:25)) %>%
  ggplot() +
   geom_point(aes(hr,hrlysr)) +
    # facet_wrap(vars(dy))
  facet_grid(~dy) 
```
## rain

```{r , echo=TRUE}
sapflow_usda_2023_hourlyweather %>% 
 filter(mth %in% c(8)) %>%
  filter(dy %in% c(21:25)) %>%
  ggplot() +
   geom_point(aes(hr,hrlyrain)) +
    # facet_wrap(vars(dy))
  facet_grid(~dy) 
```

```{r , echo=TRUE}

sapflow_usda_2023_5minweather %>% 
  mutate(dy = day(TIMESTAMP_MST),hr = hour(TIMESTAMP_MST),mth = month(TIMESTAMP_MST)) %>% 
 filter(mth %in% c(8)) %>%
  filter(dy %in% c(21:25)) %>%
  ggplot() +
   geom_point(aes(TIMESTAMP_MST,VPD)) +
    # facet_wrap(vars(dy))
  facet_grid(~dy) 
```

## correct for zero flow
filter(node %in% c('sapflow-usda-50','sapflow-usda-51','sapflow-usda-57')) %>%

```{r , echo=TRUE}
field_repro_all_aug_2023$nodeId <- field_repro_all_aug_2023$nodeID 
field_repro_all_aug_2023subset <- field_repro_all_aug_2023 %>%  mutate(node = as.factor(nodeID),hr = hour(datePbythree),dy = day(datePbythree)) %>% filter(dy %in% c(14,15,16,17,18)) %>% 
 # filter(node %in% c('sapflow-usda-50','sapflow-usda-51','sapflow-usda-57')) %>%
  as.data.frame()

usda_50_offset <- field_repro_all_aug_2023subset %>%  mutate(meanhr = meanHeatRatio) %>%
  filter(!meanhr =='NaN') %>% 
  filter(nodeId %in% c("sapflow-usda-50"))  %>% 
  filter( hr %in% c(0,1,2)) %>% summarise(mhr = mean(meanhr))

usda_51_offset <- field_repro_all_aug_2023subset %>%  mutate(meanhr = meanHeatRatio) %>%
  filter(!meanhr =='NaN') %>% 
  filter(nodeId %in% c("sapflow-usda-51"))  %>% 
  filter( hr %in% c(0,1,2)) %>% summarise(mhr = mean(meanhr))

usda_57_offset <- field_repro_all_aug_2023subset %>%  mutate(meanhr = meanHeatRatio) %>%
  filter(!meanhr =='NaN') %>% 
  filter(nodeId %in% c("sapflow-usda-57"))  %>% 
  filter( hr %in% c(0,1,2)) %>% summarise(mhr = mean(meanhr))
```
## Offset for zero flow
```{r , echo=TRUE}
field_repro_all_aug_2023subset_adjusted <- field_repro_all_aug_2023subset
field_repro_all_aug_2023subset_adjusted$mr <- 0
field_repro_all_aug_2023subset_adjusted$type <- ''

field_repro_all_aug_2023subset_adjusted[field_repro_all_aug_2023subset_adjusted$nodeId == "sapflow-usda-50",]$mr =  field_repro_all_aug_2023subset[field_repro_all_aug_2023subset$nodeId == "sapflow-usda-50",]$meanHeatRatio + (1-as.numeric(usda_50_offset))

field_repro_all_aug_2023subset_adjusted[field_repro_all_aug_2023subset_adjusted$nodeId == "sapflow-usda-50",]$type = 'full'
  
field_repro_all_aug_2023subset_adjusted[field_repro_all_aug_2023subset_adjusted$nodeId == "sapflow-usda-51",]$mr =  field_repro_all_aug_2023subset_adjusted[field_repro_all_aug_2023subset$nodeId == "sapflow-usda-51",]$meanHeatRatio + (1-as.numeric(usda_51_offset))

field_repro_all_aug_2023subset_adjusted[field_repro_all_aug_2023subset_adjusted$nodeId == "sapflow-usda-51",]$type = 'full' 
  
field_repro_all_aug_2023subset_adjusted[field_repro_all_aug_2023subset_adjusted$nodeId == "sapflow-usda-57",]$mr =  field_repro_all_aug_2023subset_adjusted[field_repro_all_aug_2023subset$nodeId == "sapflow-usda-57",]$meanHeatRatio + (1-as.numeric(usda_57_offset))

field_repro_all_aug_2023subset_adjusted[field_repro_all_aug_2023subset_adjusted$nodeId == "sapflow-usda-57",]$type = 'limited' 
  
#SE 
field_repro_all_aug_2023subset_adjusted_se <- summarySE(field_repro_all_aug_2023subset_adjusted, measurevar="mr", groupvars=c("nodeId","hr"))

field_repro_all_aug_2023subset_adjusted$dt <- date(field_repro_all_aug_2023subset_adjusted$datePbythree)
#SE by type, dy,hr
field_repro_all_aug_2023subset_adjusted_type_dy_hr_se <- summarySE(field_repro_all_aug_2023subset_adjusted, measurevar="mr", groupvars=c("type","dt","hr"))

```

## Heat pulse velocity

```{r , echo=TRUE}

field_repro_all_aug_2023subset_adjusted %>% mutate(yr = year(datePbythree),mth = month(datePbythree),dy  = day(datePbythree)) %>%
   filter(node %in% c('sapflow-usda-50','sapflow-usda-51','sapflow-usda-57')) %>%
 # filter(yr %in% c(2022) & mth %in% c(05) & dy %in% c(24)) %>%
  mutate (sv = log(1/mr) *3600 * (0.0025/0.6) ,daten = date(datePbythree))%>% 
       filter(dy == 15 ) %>%
 # filter(nodeId=="sapflow-dotmote-labs-2" )  %>% 
  ggplot() +
   geom_point(aes(x = datePbythree, y=sv,color=nodeId)) +
   geom_line(aes(x = datePbythree, y=sv,color=nodeId)) +
    theme_minimal() + scale_x_datetime(date_minor_breaks = "1 day") + 

  scale_y_continuous(
    # Features of the first axis
    name = expression(~V[h] (cm~h^{"-1"}))

  ) +
  facet_wrap(.~dy) +
  theme(legend.position = c(.17, .6))+
guides(fill = guide_legend(keywidth = 1, keyheight = 1),
    linetype=guide_legend(keywidth = 3, keyheight = 1))

```
## Prepare dataframe for analysis
```{r , echo=TRUE}

field_repro_all_aug_2023subset_adjusted_fourdays <- field_repro_all_aug_2023subset_adjusted %>% mutate(yr = year(datePbythree),mth = month(datePbythree),dy  = day(datePbythree)) %>%
   filter(node %in% c('sapflow-usda-50','sapflow-usda-51','sapflow-usda-57')) %>%
  filter( dy %in% c(14:17)) %>%
  mutate (sv = log(1/mr) *3600 * (0.0025/0.6) ,daten = date(datePbythree))%>% 
  as.data.frame()

```

# plot 4 days

```{r , echo=TRUE}

field_repro_all_aug_2023subset_adjusted_fourdays %>% 
       filter(dy %in% c(14) ) %>%
 # filter(nodeId=="sapflow-dotmote-labs-2" )  %>% 
  ggplot() +
   geom_point(aes(x = datePbythree, y=sv,color=nodeId)) +
   geom_smooth(aes(x = datePbythree, y=sv,color=nodeId)) +
    theme_minimal() + scale_x_datetime(date_minor_breaks = "1 day") + 

  scale_y_continuous(
    # Features of the first axis
    name = expression(~V[h] (cm~h^{"-1"}))

  ) +
  facet_wrap(.~dy) +
  theme(legend.position = c(.17, .6))+
guides(fill = guide_legend(keywidth = 1, keyheight = 1),
    linetype=guide_legend(keywidth = 3, keyheight = 1))

```

# water poyential and vh

```{r , echo=TRUE}
field_repro_all_aug_2023subset_adjusted_threedays <- field_repro_all_aug_2023subset_adjusted_fourdays %>%
  filter(dy %in% c(14:16)) %>% as.data.frame()

#SE
field_repro_all_aug_2023subset_adjusted_type_dy_hr_se3nodes <- field_repro_all_aug_2023subset_adjusted_type_dy_hr_se %>% filter(type != '') %>% 
   filter(dy %in% c(14:16)) %>%
  as.data.frame()

#SE
field_repro_all_aug_2023subset_adjusted_type_dy_hr_se3nodes <- field_repro_all_aug_2023subset_adjusted_type_dy_hr_se %>% filter(type != '') %>% as.data.frame()

``` 

```{r , echo=TRUE}

full <- field_repro_all_aug_2023subset_adjusted_type_dy_hr_se3nodes %>% filter(type =='full') %>% as.data.frame()

limited <- field_repro_all_aug_2023subset_adjusted_type_dy_hr_se3nodes %>% filter(type =='limited') %>% as.data.frame()

fitfield<- lm(full$mr~limited$mr)

comparefullandlimited<-  ggplot()  +geom_point(aes(full$mr,limited$mr)) +
  stat_smooth(aes(full$mr,limited$mr),method = "lm", col = "red",se = FALSE) +
  # geom_smooth(method='lm', formula= full$mr~limited$mr) +
    theme_minimal() +
   labs(title="", y = "Vh - Limited Irrigation",x="Vh - Fully Irrigated",
                colour = "Parameter") + theme(legend.position = c(.2, .8))+
guides(fill = guide_legend(keywidth = 1, keyheight = 1),
    linetype=guide_legend(keywidth = 3, keyheight = 1)) +

annotate("text",x=0.9,y= 0.7, label=paste("Adj R^2 = ",signif(summary(fitfield)$adj.r.squared, 2),
                       " P =",signif(summary(fitfield)$coef[2,4], 2)))

comparefullandlimited
```                       

```{r , echo=TRUE}

field_repro_all_aug_2023subset_adjusted_type_dy_hr_se$fulldt <- as.POSIXct(paste(field_repro_all_aug_2023subset_adjusted_type_dy_hr_se$dt, paste0(field_repro_all_aug_2023subset_adjusted_type_dy_hr_se$hr,':',0,":",0), format="%Y-%m-%d %H:%M:%S"))
```  

```{r , echo=TRUE}
allrawfullandlimitedts<-  field_repro_all_aug_2023subset_adjusted_type_dy_hr_se %>%
   filter(type != '') %>%
   ggplot()  +geom_point(aes(fulldt,1/mr,color=type)) +
 # stat_smooth(aes(fulldt,1/mr,group=type,color=type),method = "loess",se = FALSE) +
  # geom_smooth(method='lm', formula= full$mr~limited$mr) +
    theme_minimal() +
   labs(title="", y = "Vh - Limited Irrigation",x="Vh - Fully Irrigated",
                colour = "Parameter") + theme(legend.position = c(.2, .8))+
guides(fill = guide_legend(keywidth = 1, keyheight = 1),
    linetype=guide_legend(keywidth = 3, keyheight = 1)) 
 # facet_wrap(.~dt) 

allrawfullandlimitedts
``` 
# three day plot 

```{r , echo=TRUE}
allrawfullandlimited<-  field_repro_all_aug_2023subset_adjusted_type_dy_hr_se %>%
   mutate(dy = day(dt)) %>%
   filter(type != '') %>%
  filter(dy %in% c(14,15,16)) %>%
   ggplot()  +geom_point(aes(hr,1/mr,color=type)) +
  stat_smooth(aes(hr,1/mr,group=type,color=type),method = "loess",se = FALSE) +
  # geom_smooth(method='lm', formula= full$mr~limited$mr) +
    theme_minimal() +
   labs(title="",x="Time (Hour)",
                colour = "Treatment") + theme(legend.position = c(.1, .8))+
guides(fill = guide_legend(keywidth = 1, keyheight = 1),
    linetype=guide_legend(keywidth = 3, keyheight = 1)) +
  facet_wrap(.~dt) +
      scale_y_continuous(
    # Features of the first axis
    name = expression(~V[h] (cm~h^{"-1"}))

  ) 
#+
#annotate("text",x=2,y= 0.7, label=paste("Adj R^2 = ",signif(summary(fitfield)$adj.r.squared, 2),
#                       " P =",signif(summary(fitfield)$coef[2,4], 2)))

allrawfullandlimited
```  
```{r , echo=TRUE}
threedaysdata<-  field_repro_all_aug_2023subset_adjusted_type_dy_hr_se %>%
   mutate(dy = day(dt)) %>%
   filter(type != '') %>%
  filter(dy %in% c(14,15,16)) %>% as.data.frame()

```  

#Water poyential and Vh (full)

```{r , echo=TRUE}
fulldatavh <- threedaysdata %>% filter(type=='full') %>% select(dy,hr,mr,se) %>% as.data.frame()
fulldatavh[fulldatavh$dy==14,]$dy <- 21
fulldatavh[fulldatavh$dy==15,]$dy <- 22
fulldatavh[fulldatavh$dy==16,]$dy <- 23

fullvhwp <- left_join(fulldatavh,wpthreedaysbasefull , by = c('dy','hr'))

lmfullvhwpfit <- lm(fullvhwp$mr ~ fullvhwp$mwp)
fieldfullexp_wpandvh <- fullvhwp%>% ggplot(aes(mwp,mr))  +geom_point() +
  stat_smooth(method = "lm", col = "red",se = FALSE) +
    theme_minimal() +
   labs(title="Fully Irrigated", x = "Water Potential (MPa)",
                colour = "Parameter") + theme(legend.position = c(.2, .8))+
guides(fill = guide_legend(keywidth = 1, keyheight = 1),
    linetype=guide_legend(keywidth = 3, keyheight = 1)) +
      scale_y_continuous(
    # Features of the first axis
    name = expression(~V[h] (cm~h^{"-1"}))

  ) +

annotate("text",x=-0.2,y= 0.7, label=paste("R^2 = ",signif(summary(lmfullvhwpfit)$r.squared, 2),
                       " P =",signif(summary(lmfullvhwpfit)$coef[2,4], 2)))
fieldfullexp_wpandvh
```
#Water poyential and Vh (full)

```{r , echo=TRUE}
limiteddatavh <- threedaysdata %>% filter(type=='limited') %>% select(dy,hr,mr,se) %>% as.data.frame()
limiteddatavh[limiteddatavh$dy==14,]$dy <- 21
limiteddatavh[limiteddatavh$dy==15,]$dy <- 22
limiteddatavh[limiteddatavh$dy==16,]$dy <- 23

limitedvhwp <- left_join(limiteddatavh,wpthreedayslimited , by = c('dy','hr'))

lmlimitedvhwpfit <- lm(limitedvhwp$mr ~ limitedvhwp$mwp)
fieldlimitedexp_wpandvh <- limitedvhwp%>% ggplot(aes(mwp,mr))  +geom_point() +
  stat_smooth(method = "lm", col = "red",se = FALSE) +
    theme_minimal() +
   labs(title="Limited Irrigation", x = "Water Potential (MPa)",
                colour = "Parameter") + 
    scale_y_continuous(
    # Features of the first axis
    name = expression(~V[h] (cm~h^{"-1"}))

  ) +
  theme(legend.position = c(.2, .8))+
guides(fill = guide_legend(keywidth = 1, keyheight = 1),
    linetype=guide_legend(keywidth = 3, keyheight = 1)) +

annotate("text",x=-1,y= 0.7, label=paste("R^2 = ",signif(summary(lmlimitedvhwpfit)$r.squared, 2),
                       " P =",signif(summary(lmlimitedvhwpfit)$coef[2,4], 2))  )
fieldlimitedexp_wpandvh
```

#Vh and Vpd (limited)

```{r , echo=TRUE}

hrlyweatherthreedays <- sapflow_usda_2023_hourlyweather %>% filter(dy %in% c(21,22,23)) %>%
   filter(mth %in% c(8)) %>%
    as.data.frame()
fullvhweather <- left_join(fulldatavh,hrlyweatherthreedays , by = c('dy','hr'))

fullvhweather$sv <- log(1/fullvhweather$mr) *3600 * (0.0025/0.6) 
fullvhweatherfit <- lm(fullvhweather$sv ~ fullvhweather$hrlyvpd)
 
fieldfullexp_vpdandvh <- fullvhweather%>% 
  ggplot(aes(hrlyvpd,sv))  +geom_point() +
  stat_smooth(method = "lm", col = "red",se = FALSE) +
    theme_minimal() +
   labs(title="Fully Irrigated", x = "VPD",
                colour = "Parameter") + theme(legend.position = c(.2, .8))+

    scale_y_continuous(
    # Features of the first axis
    name = expression(~V[h] (cm~h^{"-1"}))

  ) +
guides(fill = guide_legend(keywidth = 1, keyheight = 1),
    linetype=guide_legend(keywidth = 3, keyheight = 1)) +

annotate("text",x=1,y= 5, label=paste("R^2 = ",signif(summary(fullvhweatherfit)$adj.r.squared, 2),
                       " P =",signif(summary(fullvhweatherfit)$coef[2,4], 2)))
fieldfullexp_vpdandvh
```

## Vh and vpd   (full)
```{r , echo=TRUE}

hrlyweatherthreedays <- sapflow_usda_2023_hourlyweather %>% filter(dy %in% c(21,22,23)) %>%
   filter(mth %in% c(8)) %>%
    as.data.frame()
limitedvhweather <- left_join(limiteddatavh,hrlyweatherthreedays , by = c('dy','hr'))

limitedvhweather$sv <- log(1/limitedvhweather$mr) *3600 * (0.0025/0.6) 
limitedvhweatherfit <- lm(limitedvhweather$sv ~ limitedvhweather$hrlyvpd)
 
fieldlimitedexp_vpdandvh <- limitedvhweather%>% 
  ggplot(aes(hrlyvpd,sv))  +geom_point() +
  stat_smooth(method = "lm", col = "red",se = FALSE) +
    theme_minimal() +
   labs(title="Limited Irrigation", x = "VPD",
                colour = "Parameter") + theme(legend.position = c(.2, .8))+

    scale_y_continuous(
    # Features of the first axis
    name = expression(~V[h] (cm~h^{"-1"}))

  ) +
guides(fill = guide_legend(keywidth = 1, keyheight = 1),
    linetype=guide_legend(keywidth = 3, keyheight = 1)) +

annotate("text",x=1,y= 5, label=paste("R^2 = ",signif(summary(limitedvhweatherfit)$adj.r.squared, 2),
                       " P =",signif(summary(limitedvhweatherfit)$coef[2,4], 2)))
fieldlimitedexp_vpdandvh
```

```{r , echo=FALSE}
library(cowplot)
plot_grid(fieldlimitedexp_vpdandvh,fieldfullexp_vpdandvh, 
          fieldlimitedexp_wpandvh,fieldfullexp_wpandvh, 
  nrow = 2,
  ncol = 2,
  labels = "AUTO",
  label_size = 12,
  align = "hv",
  axis="tb",
  scale = c(1, 1))
ggsave("figs/fig3_confsap.pdf", width = 20, height = 20, units = "cm")
ggsave("figs/fig3_confsap.png", width = 20, height = 20, units = "cm")

```

## Get the scale data - January 2022
```{r , echo=TRUE}

#gravimetric_all_22 <- readxl::read_xlsx('./data/Maize 4-16 to 4-30-21 Scale Data all MDT.xlsx')
gravimetric_all_22_raw <- readxl::read_xlsx('./data/january-2022-gravimetric/Gravimetric Scale Data WinWedgeDDEMaize11-29-21 to 1-5-22-Mod.xlsm' )
gravimetric_all_raw_22$time <- paste(lubridate::hour(gravimetric_all_raw$`Time (MDT)`),
                                      lubridate::minute(gravimetric_all_raw$`Time (MDT)`),
                                      lubridate::second(gravimetric_all_raw$`Time (MDT)`),sep = ":")
gravimetric_all_raw_22$datetime <- lubridate::as_datetime(trimws(paste(lubridate::as_date(gravimetric_all_raw$Date),
                                      gravimetric_all_raw$time," ")), tz="America/Denver")

```

## Get the scale data - January 2022
```{r , echo=TRUE}

#gravimetric_all_22 <- readxl::read_xlsx('./data/Maize 4-16 to 4-30-21 Scale Data all MDT.xlsx')
gravimetric_all_22_raw <- read_csv('./data/january-2022-gravimetric/Gravimetric Scale Data WinWedgeDDEMaize11-29-21 to 1-5-22.csv')

gravimetric_all_22_raw$time <- paste(lubridate::hour(gravimetric_all_22_raw$Time...4),
                                      lubridate::minute(gravimetric_all_22_raw$Time...4),
                                      lubridate::second(gravimetric_all_22_raw$Time...4),sep = ":")
gravimetric_all_22_raw$datetime <- lubridate::as_datetime(trimws(paste(lubridate::as_date(gravimetric_all_22_raw$`Date...3`,format="%m/%d/%y"),
                                      gravimetric_all_22_raw$time," ")), tz="America/Denver")

```

## Map the patterns for Sunny days with Cloudy/Rainy Days - Use Agrimet. Use Sapflow velocity curves. Maybe above a threshold of 10 are viable days. 

```{r , echo=TRUE}

gravimetric_all_22_raw %>% 
  mutate (daten = date(datetime),weight = `Weight(kg)...5`,Dotmote=`Dotmote Gauge...1`)%>% 
     filter(date(datetime) >= "2022-12-10" ) %>%
       filter(date(datetime) <= "2022-12-17" ) %>%
 # filter(nodeId=="sapflow-dotmote-labs-2" )  %>% 
  ggplot() +
   geom_point(aes(x = datetime, y=weight,color=Dotmote)) +
   geom_line(aes(x = datetime, y=weight,color=Dotmote)) +
    theme_minimal() + scale_x_datetime(date_minor_breaks = "1 day") + 

  scale_y_continuous(
    # Features of the first axis
    name = expression(~Weight~(Kg))

  ) +
  theme(legend.position = "bottom")+
guides(fill = guide_legend(keywidth = 1, keyheight = 1),
    linetype=guide_legend(keywidth = 3, keyheight = 1)) +
  labs(color="Node",x="Time (Date)")
ggsave("figs/gravi_plot_22.png", width = 20, height = 20, units = "cm")

```

```{r , echo=TRUE}

gravimetric_all_raw %>% 
  mutate (daten = date(datetime),weight = `Weight(kg)`)%>% 
     filter(date(datetime) >= "2021-04-28" ) %>%
       filter(date(datetime) <= "2021-04-28" ) %>%
 # filter(nodeId=="sapflow-dotmote-labs-2" )  %>% 
  ggplot() +
   geom_point(aes(x = datetime, y=weight,color=Dotmote)) +
   geom_line(aes(x = datetime, y=weight,color=Dotmote)) +
    theme_minimal(base_size = 18) + scale_x_datetime(date_minor_breaks = "1 day") + 

  scale_y_continuous(
    # Features of the first axis
    name = expression(~Weight~(Kg))

  ) +
  theme(legend.position = "bottom")+
guides(fill = guide_legend(keywidth = 1, keyheight = 1),
    linetype=guide_legend(keywidth = 3, keyheight = 1)) +
  labs(color="Node",x="Time (Date)")
ggsave("figs/gravi_plot_28.png", width = 20, height = 20, units = "cm")

```

```{r , echo=TRUE}
sapflow_usda_2021_adjusted %>% 
  mutate (sv = log(mr) *3600 * (0.0025/0.6) ,daten = date(dateP))%>% 
        filter(date(dateP) >= "2021-04-22" ) %>%
       filter(date(dateP) <= "2021-04-28" ) %>%
 # filter(nodeId=="sapflow-dotmote-labs-2" )  %>% 
  ggplot() +
   geom_point(aes(x = dateP, y=sv,color=nodeId)) +
   geom_line(aes(x = dateP, y=sv,color=nodeId)) +
    theme_minimal() + scale_x_datetime(date_minor_breaks = "1 day") + 

  scale_y_continuous(
    # Features of the first axis
    name = expression(~V[h] (cm~h^{"-1"}))

  ) +
  theme(legend.position = "bottom")+
guides(fill = guide_legend(keywidth = 1, keyheight = 1),
    linetype=guide_legend(keywidth = 3, keyheight = 1)) +
  labs(color="Node",x="Time (Date)")
ggsave("figs/sap_plot.png", width = 20, height = 20, units = "cm")
```

```{r , echo=TRUE}
sapflow_usda_2021_adjusted %>% 
  mutate (sv = log(mr) *3600 * (0.0025/0.6) ,daten = date(dateP))%>% 
        filter(date(dateP) >= "2021-04-22" ) %>%
       filter(date(dateP) <= "2021-04-28" ) %>%
 # filter(nodeId=="sapflow-dotmote-labs-2" )  %>% 
  ggplot() +
   geom_smooth(aes(x = dateP, y=sv,color=nodeId)) +
   #geom_line(aes(x = dateP, y=sv,color=nodeId)) +
    theme_minimal(base_size = 18) + scale_x_datetime(date_minor_breaks = "1 day") + 

  scale_y_continuous(
    # Features of the first axis
    name = expression(~V[h] (cm~h^{"-1"}))

  ) +
  theme(legend.position = "bottom")+
guides(fill = guide_legend(keywidth = 1, keyheight = 1),
    linetype=guide_legend(keywidth = 3, keyheight = 1)) +
  labs(color="Node",x="Time (Date)")
ggsave("figs/sap_smmoth_plot.png", width = 28, height = 15, units = "cm")
```

```{r , echo=TRUE}

usda_gravi <- gravimetric_all_raw %>% 
  mutate (daten = date(datetime),weight = `Weight(kg)`)%>% 
     filter(date(datetime) >= "2021-04-24" ) %>%
       filter(date(datetime) <= "2021-04-24" ) %>%
 # filter(nodeId=="sapflow-dotmote-labs-2" )  %>% 
  ggplot() +
   geom_point(aes(x = datetime, y=weight,color=Dotmote)) +
   geom_line(aes(x = datetime, y=weight,color=Dotmote)) +
    theme_minimal() + scale_x_datetime(date_minor_breaks = "1 day") + 

  scale_y_continuous(
    # Features of the first axis
    name = expression(~Weight~(Kg))

  ) +
  theme(legend.position = "bottom")+
guides(fill = guide_legend(keywidth = 1, keyheight = 1),
    linetype=guide_legend(keywidth = 3, keyheight = 1)) +
  labs(color="Node",x="Time (Date)")
```

```{r , echo=TRUE}

sapflow_usda <- sapflow_usda_2021_adjusted %>% 
  mutate (sv = log(mr) *3600 * (0.0025/0.6) ,daten = date(dateP))%>% 
       filter(date(dateP) == "2021-04-24" ) %>%
 # filter(nodeId=="sapflow-dotmote-labs-2" )  %>% 
  ggplot() +
   geom_point(aes(x = dateP, y=sv,color=nodeId)) +
   geom_line(aes(x = dateP, y=sv,color=nodeId)) +
    theme_minimal() + scale_x_datetime(date_minor_breaks = "1 day") + 

  scale_y_continuous(
    # Features of the first axis
    name = expression(~V[h] (cm~h^{"-1"}))

  ) +
  theme(legend.position = "bottom")+
guides(fill = guide_legend(keywidth = 1, keyheight = 1),
    linetype=guide_legend(keywidth = 3, keyheight = 1)) +
  labs(color="Node",x="Time (Date)")

```

```{r , echo=TRUE}
library(patchwork)

usda_gravi / sapflow_usda
ggsave("figs/gravi_sapflow_usda.png", width = 20, height = 20, units = "cm")
```

# try the correlation
```{r , echo=TRUE}

usda_gravi_24 <- gravimetric_all_raw %>% 
  mutate (daten = date(datetime),weight = `Weight(kg)`, 
          hr = hour(datetime), mints = minute(datetime))%>% 
     filter(date(datetime) >= "2021-04-24" ) %>%
       filter(date(datetime) <= "2021-04-24" ) %>%
  as.data.frame()

usda_gravi_all <- gravimetric_all_raw %>% 
  mutate (daten = date(datetime),weight = `Weight(kg)`, 
          hr = hour(datetime), mints = minute(datetime))%>% 
     filter(date(datetime) >= "2021-04-22" ) %>%
       filter(date(datetime) <= "2021-04-28" ) %>%
  as.data.frame()

usda_gravi_24_8 <- gravimetric_all_raw %>% 
  mutate (daten = date(datetime),weight = `Weight(kg)`, 
          hr = hour(datetime), mints = minute(datetime))%>% 
     filter(date(datetime) >= "2021-04-24" ) %>%
       filter(date(datetime) <= "2021-04-24" ) %>%
  filter(Dotmote =='USDA8') %>%
  as.data.frame()

 #
sapflow_usda_24 <- sapflow_usda_2021_adjusted %>% 
  mutate (sv = log(mr) *3600 * (0.0025/0.6) ,daten = date(dateP))%>% 
       filter(date(dateP) == "2021-04-24" ) %>%
  as.data.frame()

sapflow_usda_all <- sapflow_usda_2021_adjusted %>% 
  mutate (sv = log(mr) *3600 * (0.0025/0.6) ,daten = date(dateP))%>% 
       filter(date(dateP) >= "2021-04-22" ) %>%
     filter(date(dateP) <= "2021-04-28" ) %>%
  as.data.frame()

sapflow_usda_24_8 <- sapflow_usda_2021_adjusted %>% 
  mutate (sv = log(mr) *3600 * (0.0025/0.6) ,daten = date(dateP))%>% 
       filter(date(dateP) == "2021-04-24" & nodeId=='sapflow-usda-8') %>%
  as.data.frame()

```

```{r , echo=TRUE}

msv_s8 <- sapflow_usda_24_8 %>% 
   group_by(nodeId,hr) %>% 
 # arrange(nodeId, hr, sv) %>% 
  dplyr::summarise(m_sv = mean(sv)) %>%
  as.data.frame()  

msv_s_all <- sapflow_usda_all %>% 
   group_by(daten,nodeId,hr) %>% 
 # arrange(nodeId, hr, sv) %>% 
  dplyr::summarise(m_sv = mean(sv)) %>%
  as.data.frame()  

msv_s_all_7 <- sapflow_usda_all %>% 
  filter(nodeId=='sapflow-usda-7') %>%
   group_by(daten,nodeId,hr) %>% 
 # arrange(nodeId, hr, sv) %>% 
  dplyr::summarise(m_sv = mean(sv)) %>%
  as.data.frame()  

msv_s_all_8 <- sapflow_usda_all %>% 
  filter(nodeId=='sapflow-usda-8') %>%
   group_by(daten,nodeId,hr) %>% 
 # arrange(nodeId, hr, sv) %>% 
  dplyr::summarise(m_sv = mean(sv)) %>%
  as.data.frame()  

msv_s_all_9 <- sapflow_usda_all %>% 
  filter(nodeId=='sapflow-usda-9') %>%
   group_by(daten,nodeId,hr) %>% 
 # arrange(nodeId, hr, sv) %>% 
  dplyr::summarise(m_sv = mean(sv)) %>%
  as.data.frame()  

msv_s_all_10 <- sapflow_usda_all %>% 
  filter(nodeId=='sapflow-usda-10') %>%
   group_by(daten,nodeId,hr) %>% 
 # arrange(nodeId, hr, sv) %>% 
  dplyr::summarise(m_sv = mean(sv)) %>%
  as.data.frame()  

usda_gravi_24_8_weight_hrly <-  usda_gravi_24_8 %>%
  group_by(Dotmote,hr) %>%
    dplyr::summarise(m_weight= mean(weight)) %>%
as.data.frame()  

usda_gravi_all_weight_hrly <-  usda_gravi_all %>%
  group_by(daten,Dotmote,hr) %>%
    dplyr::summarise(m_weight= mean(weight)) %>%
as.data.frame()  

usda_gravi_24_8_weight_hrly_abs <- usda_gravi_24_8_weight_hrly %>%
  group_by(Dotmote,hr) %>%
  mutate(diff = abs(m_weight - lag(m_weight)) ) %>%
  as.data.frame()

usda_gravi_all_weight_hrly_abs <- usda_gravi_all_weight_hrly %>%
  group_by(daten,Dotmote,hr) %>%
  mutate(diff = abs(m_weight - lag(m_weight)) ) %>%
  as.data.frame()

usda_gravi_all_weight_hrly_abs_7 <- usda_gravi_all_weight_hrly %>%
  filter(Dotmote == 'USDA7')  %>%
  group_by(daten,Dotmote,hr) %>%
  mutate(diff = abs(m_weight - lag(m_weight)) ) %>%
  as.data.frame()

usda_gravi_all_weight_hrly_abs_8 <- usda_gravi_all_weight_hrly %>%
  filter(Dotmote == 'USDA8')  %>%
  group_by(daten,Dotmote,hr) %>%
  mutate(diff = abs(m_weight - lag(m_weight)) ) %>%
  as.data.frame()

usda_gravi_all_weight_hrly_abs_9 <- usda_gravi_all_weight_hrly %>%
  filter(Dotmote == 'USDA9')  %>%
  group_by(daten,Dotmote,hr) %>%
  mutate(diff = abs(m_weight - lag(m_weight)) ) %>%
  as.data.frame()

usda_gravi_all_weight_hrly_abs_10 <- usda_gravi_all_weight_hrly %>%
  filter(Dotmote == 'USDA10')  %>%
  group_by(daten,Dotmote,hr) %>%
  mutate(diff = abs(m_weight - lag(m_weight)) ) %>%
  as.data.frame()

 summary( lm(usda_gravi_24_8_weight_hrly_abs$diff ~ msv_s8$m_sv))
```
# Plot hourly but one day
```{r , echo=FALSE}

ggplot() +
geom_point(data = usda_gravi_24_8_weight_hrly_abs, aes(x=hr,diff,color="GM")) +
geom_point(data= msv_s8, aes(x=hr, y=m_sv/100 , color="SV"))  +
  theme_minimal(base_size = 18) +
  labs(color="",x=" Time (Hour)" , y="")
```

# Plot hourly but smooth it
```{r , echo=FALSE}

ggplot() +
geom_smooth(data = usda_gravi_24_8_weight_hrly_abs, aes(x=hr,diff,color="GM")) +
geom_smooth(data= msv_s8, aes(x=hr, y=m_sv/100 , color="SV"))  +
  theme_minimal(base_size = 18) +
  labs(color="",x=" Time (Hour)" , y="")
```

# Compare , but one node one day

```{r , echo=FALSE}

ggplot() +
geom_point(data = usda_gravi_all_weight_hrly_abs_8[usda_gravi_all_weight_hrly_abs_8$daten=='2021-04-26',], aes(x=hr,diff,color=Dotmote)) +
geom_point(data= msv_s_all_8[msv_s_all_8$daten=='2021-04-26',], aes(x=hr, y=m_sv/100 , color=nodeId))  +
  facet_wrap(.~daten) +
  theme_minimal(base_size = 18) +
  labs(color="",x=" Time (Hour)" , y="")
```
# All days, one node Node 7 perf

```{r , echo=FALSE}

coeff = 100
ggplot() +
  geom_point(data = usda_gravi_all_weight_hrly_abs_7[usda_gravi_all_weight_hrly_abs_7$daten > '2021-04-23',], aes(x=hr,diff,color=Dotmote)) +
  geom_point(data= msv_s_all_7[msv_s_all_7$daten > '2021-04-23', ], aes(x=hr, y=m_sv/coeff , color=nodeId))  +

  facet_wrap(.~daten) +
  scale_y_continuous(
    
    # Features of the first axis
    name = "Flow (kg/hr)" ,
    
    # Add a second axis and specify its features
    sec.axis = sec_axis(~.*(coeff), name=expression(~V[h] (cm~h^{"-1"})))
  ) +
  theme_minimal(base_size = 18) +
  labs(color="",x=" Time (Hour)" , y="")
ggsave("figs/sap_gm_compare.png", width = 28, height = 15, units = "cm")
```

# All days, one node Node 8

```{r , echo=FALSE}

coeff = 100
ggplot() +
  geom_point(data = usda_gravi_all_weight_hrly_abs_8[usda_gravi_all_weight_hrly_abs_8$daten > '2021-04-23',], aes(x=hr,diff,color=Dotmote)) +
  geom_point(data= msv_s_all_8[msv_s_all_8$daten > '2021-04-23', ], aes(x=hr, y=m_sv/coeff , color=nodeId))  +

  facet_wrap(.~daten) +
  scale_y_continuous(
    
    # Features of the first axis
    name = "Flow (kg/hr)" ,
    
    # Add a second axis and specify its features
    sec.axis = sec_axis(~.*(coeff), name=expression(~V[h] (cm~h^{"-1"})))
  ) +
  theme_minimal(base_size = 18) +
  labs(color="",x=" Time (Hour)" , y="")
```

# All days, one node Node 9

```{r , echo=FALSE}

coeff = 100
ggplot() +
  geom_point(data = usda_gravi_all_weight_hrly_abs_9[usda_gravi_all_weight_hrly_abs_9$daten > '2021-04-23',], aes(x=hr,diff,color=Dotmote)) +
  geom_point(data= msv_s_all_9[msv_s_all_9$daten > '2021-04-23', ], aes(x=hr, y=m_sv/coeff , color=nodeId))  +

  facet_wrap(.~daten) +
  scale_y_continuous(
    
    # Features of the first axis
    name = "Flow (kg/hr)" ,
    
    # Add a second axis and specify its features
    sec.axis = sec_axis(~.*(coeff), name=expression(~V[h] (cm~h^{"-1"})))
  ) +
  theme_minimal(base_size = 18) +
  labs(color="",x=" Time (Hour)" , y="")
```

```{r , echo=FALSE}

coeff = 100
ggplot() +
  geom_point(data = usda_gravi_all_weight_hrly_abs_10[usda_gravi_all_weight_hrly_abs_10$daten > '2021-04-23',], aes(x=hr,diff,color=Dotmote)) +
  geom_point(data= msv_s_all_10[msv_s_all_10$daten > '2021-04-23', ], aes(x=hr, y=m_sv/coeff , color=nodeId))  +

  facet_wrap(.~daten) +
  scale_y_continuous(
    
    # Features of the first axis
    name = "Flow (kg/hr)" ,
    
    # Add a second axis and specify its features
    sec.axis = sec_axis(~.*(coeff), name=expression(~V[h] (cm~h^{"-1"})))
  ) +
  theme_minimal(base_size = 18) +
  labs(color="",x=" Time (Hour)" , y="")
```

Plot the points
```{r , echo=FALSE}

combined_byDay_SF <- msv_s_all_10[msv_s_all_10$daten > '2021-04-23', ]
combined_byDay_SF <- rbind(combined_byDay_SF,msv_s_all_7[msv_s_all_7$daten > '2021-04-23', ])
combined_byDay_SF <- rbind(combined_byDay_SF,msv_s_all_8[msv_s_all_8$daten > '2021-04-23', ])
combined_byDay_SF <- rbind(combined_byDay_SF,msv_s_all_9[msv_s_all_9$daten > '2021-04-23', ])

combined_byDay_GM <- usda_gravi_all_weight_hrly_abs_10[usda_gravi_all_weight_hrly_abs_10$daten > '2021-04-23',]
combined_byDay_GM <- rbind(combined_byDay_GM, usda_gravi_all_weight_hrly_abs_7[usda_gravi_all_weight_hrly_abs_7$daten > '2021-04-23',])
combined_byDay_GM <- rbind(combined_byDay_GM, usda_gravi_all_weight_hrly_abs_8[usda_gravi_all_weight_hrly_abs_8$daten > '2021-04-23',])
combined_byDay_GM <- rbind(combined_byDay_GM, usda_gravi_all_weight_hrly_abs_9[usda_gravi_all_weight_hrly_abs_9$daten > '2021-04-23',])

combined_byDay_SF$node <- ''
combined_byDay_SF[combined_byDay_SF$nodeId =='sapflow-usda-10',]$node = 'USDA10'
combined_byDay_SF[combined_byDay_SF$nodeId =='sapflow-usda-7',]$node = 'USDA7'
combined_byDay_SF[combined_byDay_SF$nodeId =='sapflow-usda-8',]$node = 'USDA8'
combined_byDay_SF[combined_byDay_SF$nodeId =='sapflow-usda-9',]$node = 'USDA9'

colors <-  RColorBrewer::brewer.pal(4,name="Spectral")

coeff = 100
ggplot() +
   geom_smooth(data= combined_byDay_GM, aes(hr,diff, color=as.factor(Dotmote),linetype = "Scale"),se=FALSE ,)+ 
    geom_smooth(data= combined_byDay_SF, aes(hr,m_sv/coeff, color=as.factor(node),linetype = "Sapflow"),se=FALSE,
                arrow = arrow(angle = 15, ends = "both", type = "closed"))+
   scale_y_continuous(
    
    # Features of the first axis
    name = "Flow (kg/hr)" ,
    
    # Add a second axis and specify its features
    sec.axis = sec_axis(~.*(coeff), name=expression(~V[h] (cm~h^{"-1"})))
  ) +
  scale_colour_brewer(palette = "Set1")+
  scale_linetype_manual("Method",values=c("Scale"=1,"Sapflow"=2)) +
  theme_minimal(base_size = 18) +
  labs(color="",x=" Time (Hour)" , y="")
ggsave("figs/sap_gm_hourly_alldates.png", width = 28, height = 15, units = "cm")

```
```{r , echo=FALSE}
 
ggplot() +
   geom_smooth(data= combined_byDay_GM, aes(hr,diff, color=as.factor(Dotmote),linetype = "Scale"),se=TRUE ,)+ 
    geom_smooth(data= combined_byDay_SF, aes(hr,m_sv/coeff, color=as.factor(node),linetype = "Sapflow"),se=TRUE,
                arrow = arrow(angle = 15, ends = "both", type = "closed"))+
   scale_y_continuous(
    
    # Features of the first axis
    name = "Flow (kg/hr)" ,
    
    # Add a second axis and specify its features
    sec.axis = sec_axis(~.*(coeff), name=expression(~V[h] (cm~h^{"-1"})))
  ) +
  scale_colour_brewer(palette = "Set1")+
  scale_linetype_manual("Method",values=c("Scale"=1,"Sapflow"=2)) +
  theme_minimal(base_size = 18) +
  labs(color="",x=" Time (Hour)" , y="")
ggsave("figs/sap_gm_hourly_alldates_se.png", width = 28, height = 15, units = "cm")

```

```{r , echo=FALSE}

ggplot() +
   geom_smooth(data= combined_byDay_GM, aes(hr,diff, color=as.factor(Dotmote),linetype = "Scale"),se=FALSE ,)+ 
    geom_smooth(data= combined_byDay_SF, aes(hr,m_sv/coeff, color=as.factor(node),linetype = "Sapflow"),se=FALSE,
                arrow = arrow(angle = 15, ends = "both", type = "closed"))+
  facet_grid(.~daten) +
   scale_y_continuous(
    
    # Features of the first axis
    name = "Flow (kg/hr)" ,
    
    # Add a second axis and specify its features
    sec.axis = sec_axis(~.*(coeff), name=expression(~V[h] (cm~h^{"-1"})))
  ) +
  scale_colour_brewer(palette = "Set1")+
  scale_linetype_manual("Method",values=c("Scale"=1,"Sapflow"=2)) +
  theme_minimal(base_size = 18) +
  theme(legend.position = "bottom") +
  labs(color="",x=" Time (Hour)" , y="")
ggsave("figs/sap_gm_hourly_alldates_seoff_day.png", width = 28, height = 15, units = "cm")

```

```{r , echo=FALSE}
# Adjust the Sapflow

coeff <- 1

msv_s8 %>% 
  ggplot() +
   geom_point(aes(x = hr, y=m_sv,color=nodeId)) +
   geom_line(aes(x = hr, y=m_sv,color=nodeId)) +
   geom_point( data=usda_gravi_24_8_weight_hrly,aes(x=hr,y=m_weight / coeff,color='Weigh')) +
  #geom_smooth(aes(dateP,sv),span = 0.1, se = FALSE) +
  #geom_smooth(aes(x = dateP, y=meanhr,color=as.factor(nodeID)),method = loess, span="0.0008",se = TRUE)  +
    theme_minimal() + 
  #scale_x_datetime(date_minor_breaks = "1 day") + 
  # labs(subtitle="",title=expression(~italic(Corn~~USDA)), y =expression(~V[h] (cm~h^{"-1"})),x="Date",
  #              colour = "Node ID") +
  # Divide by 10 to get the same range than the temperature
  
  scale_y_continuous(
    
    # Features of the first axis
    name = expression(~V[h] (cm~h^{"-1"})),
    
    # Add a second axis and specify its features
    sec.axis = sec_axis(~.*coeff, name="Flow (g/s)")
  ) +
  theme(legend.position = c(.17, 1))+
guides(fill = guide_legend(keywidth = 1, keyheight = 1),
    linetype=guide_legend(keywidth = 3, keyheight = 1))
```

```{r , echo=TRUE}

sapflow_usda_2021_adjusted %>% 
  mutate (sv = log(mr) *3600 * (0.0025/0.6) ,daten = date(dateP))%>% 
       #filter(date(dateP) == "2021-04-24" ) %>%
 # filter(nodeId=="sapflow-dotmote-labs-2" )  %>% 
  ggplot() +
   geom_point(aes(x = dateP, y=sv,color=nodeId)) +
   geom_line(aes(x = dateP, y=sv,color=nodeId)) +
    theme_minimal() + scale_x_datetime(date_minor_breaks = "1 day") + 

  scale_y_continuous(
    # Features of the first axis
    name = expression(~V[h] (cm~h^{"-1"}))

  ) +
  theme(legend.position = c(.17, .6))+
guides(fill = guide_legend(keywidth = 1, keyheight = 1),
    linetype=guide_legend(keywidth = 3, keyheight = 1))

```

```{r , echo=TRUE}

 gravimetric_all_raw %>% 
  mutate (daten = date(datetime),weight = `Weight(kg)`,day= day(datetime),hour=hour(datetime))%>% 
     filter(date(datetime) >= "2021-04-22" ) %>%
       filter(date(datetime) <= "2021-04-28" ) %>%
 # filter(nodeId=="sapflow-dotmote-labs-2" )  %>% 
  ggplot() +
   geom_point(aes(x = hour, y=weight,color=Dotmote)) +
   geom_line(aes(x = hour, y=weight,color=Dotmote)) +
    theme_minimal() + 
  #scale_x_datetime(date_minor_breaks = "1 day") + 
  facet_wrap(~day) +

  scale_y_continuous(
    # Features of the first axis
    name = expression(~Weight~(Kg))

  ) +
  theme(legend.position="bottom")+
guides(fill = guide_legend(keywidth = 1, keyheight = 1),
    linetype=guide_legend(keywidth = 3, keyheight = 1)) +
  labs(color="Node",x=" Time (Hour)")

 gravitim <- gravimetric_all_raw %>% 
  mutate (daten = date(datetime),weight = `Weight(kg)`,day= day(datetime),hour=hour(datetime))%>% 
     filter(date(datetime) >= "2021-04-22" ) %>%
       filter(date(datetime) <= "2021-04-28" ) %>%
 # filter(nodeId=="sapflow-dotmote-labs-2" )  %>% 
  ggplot() +
   geom_point(aes(x = hour, y=weight,color=Dotmote)) +
   geom_line(aes(x = hour, y=weight,color=Dotmote)) +
    theme_minimal() + 
  #scale_x_datetime(date_minor_breaks = "1 day") + 
  facet_wrap(~day) +

  scale_y_continuous(
    # Features of the first axis
    name = expression(~Weight~(Kg))

  ) +
  theme(legend.position="bottom")+
guides(fill = guide_legend(keywidth = 1, keyheight = 1),
    linetype=guide_legend(keywidth = 3, keyheight = 1)) +
  labs(color="Node",x=" Time (Hour)")

```

```{r , echo=TRUE}

sapflow_usda_2021_adjusted %>% 
  mutate (sv = log(mr) *3600 * (0.0025/0.6) ,daten = date(dateP), 
          day=day(dateP),hour=hour(dateP))%>% 
       #filter(date(dateP) == "2021-04-24" ) %>%
 # filter(nodeId=="sapflow-dotmote-labs-2" )  %>% 
       filter(date(dateP)  >= "2021-04-22" ) %>%
       filter(date(dateP)  <= "2021-04-28" ) %>%
  ggplot() +
   geom_point(aes(x = hour, y=sv,color=nodeId)) +
   geom_line(aes(x = hour, y=sv,color=nodeId)) +
    theme_minimal() + 
  #scale_x_datetime(date_minor_breaks = "1 day") + 
facet_wrap(~day)+
  scale_y_continuous(
    # Features of the first axis
    name = expression(~V[h] (cm~h^{"-1"}))

  ) +
  theme(legend.position="bottom")+
guides(fill = guide_legend(keywidth = 1, keyheight = 1),
    linetype=guide_legend(keywidth = 3, keyheight = 1)) +
  labs(color="Node",x="Time (Hour)")

saptim <-  sapflow_usda_2021_adjusted %>% 
  mutate (sv = log(mr) *3600 * (0.0025/0.6) ,daten = date(dateP), 
          day=day(dateP),hour=hour(dateP))%>% 
       #filter(date(dateP) == "2021-04-24" ) %>%
 # filter(nodeId=="sapflow-dotmote-labs-2" )  %>% 
       filter(date(dateP)  >= "2021-04-22" ) %>%
       filter(date(dateP)  <= "2021-04-28" ) %>%
  ggplot() +
   geom_point(aes(x = hour, y=sv,color=nodeId)) +
   geom_line(aes(x = hour, y=sv,color=nodeId)) +
    theme_minimal() + 
  #scale_x_datetime(date_minor_breaks = "1 day") + 
facet_wrap(~day)+
  scale_y_continuous(
    # Features of the first axis
    name = expression(~V[h] (cm~h^{"-1"}))

  ) +
  theme(legend.position="bottom")+
guides(fill = guide_legend(keywidth = 1, keyheight = 1),
    linetype=guide_legend(keywidth = 3, keyheight = 1)) +
  labs(color="Node",x="Time (Hour)")

```

```{r , echo=TRUE}
library(patchwork)

gravitim / saptim
ggsave("figs/gravi_sapflow_timeseries_usda.png", width = 20, height = 20, units = "cm")
```

# Explore relationship between Sapflow and Gravimetric 

```{r , echo=TRUE}

blockDataSapflow <- sapflow_usda_2021_adjusted %>% 
  mutate (sv = log(mr) *3600 * (0.0025/0.6) ,daten = date(dateP), 
          day=day(dateP),hour=hour(dateP))%>% 
       #filter(date(dateP) == "2021-04-24" ) %>%
 # filter(nodeId=="sapflow-dotmote-labs-2" )  %>% 
       filter(date(dateP)  >= "2021-04-22" ) %>%
       filter(date(dateP)  <= "2021-04-28" ) %>% 
  as.data.frame()
blockDataGavimetric<- gravimetric_all_raw %>% 
  mutate (daten = date(datetime),weight = `Weight(kg)`,day= day(datetime),hour=hour(datetime))%>% 
     filter(date(datetime) >= "2021-04-22" ) %>%
       filter(date(datetime) <= "2021-04-28" ) %>%
 # filter(nodeId=="sapflow-dotmote-labs-2" )  %>% 
   as.data.frame()

# Take values from 6 to 18 for all the plants
filteredSapflow <- blockDataSapflow %>% 
  #filter(hour %in% c(6:18)) %>% 
  dplyr::group_by(day,hour) %>%
  dplyr::summarize(mhr=mean(mr)) %>%
  select(day,hour,mhr) %>%
  as.data.frame()
filteredGravimetric <- blockDataGavimetric %>% 
  #filter(hour %in% c(6:18)) %>% 
    dplyr::group_by(day,hour) %>%
  dplyr::summarize(mw=mean(weight)) %>%
  select(day,hour,mw) %>%
  as.data.frame()
```

```{r , echo=TRUE}

combinedFiltered <-  filteredSapflow
combinedFiltered$mw <- filteredGravimetric[c(1:167),]$mw

# Take values from 6 to 18 for all the plants
ggplot() +
  geom_point(data=combinedFiltered,aes(mw,mhr,color=as.factor(hour))) +
  theme_minimal(base_size = 14)+ 
  labs(x="Weight (kg)", y="Vh") +
  labs(color="Hour")
ggsave("figs/gravi_sapflow_compare.png", width = 20, height = 20, units = "cm")
```

```{r , echo=TRUE}
summary(lm(data = combinedFiltered, mhr~mw))
```

# check the temp

```{r , echo=TRUE}
climate_gravimetric_all <- readxl::read_xlsx('./data/Greenhouse 5 min data 4-16 to 4-30-21 Maize.xlsx')
head(climate_gravimetric_all)
climate_gravimetric_all$time <- paste(lubridate::hour(climate_gravimetric_all$Time),
                                      lubridate::minute(climate_gravimetric_all$Time),
                                      lubridate::second(climate_gravimetric_all$Time),sep = ":")
climate_gravimetric_all$datetime <- lubridate::as_datetime(trimws(paste(lubridate::as_date(climate_gravimetric_all$Date),
                                      climate_gravimetric_all$time," ")), tz="America/Denver")

```

# plot for the day

```{r , echo=TRUE}

climate_gravimetric_all %>% 
  mutate (daten = date(datetime),tempF = `Climate Temperature(°F)`)%>% 
     filter(date(datetime) >= "2021-04-22" ) %>%
       filter(date(datetime) <= "2021-04-28" ) %>%
 # filter(nodeId=="sapflow-dotmote-labs-2" )  %>% 
  ggplot() +
   geom_point(aes(x = datetime, y=tempF)) +
   geom_line(aes(x = datetime, y=tempF)) +
    theme_minimal() + scale_x_datetime(date_minor_breaks = "1 day") + 

  scale_y_continuous(
    # Features of the first axis
    name = expression(~Temperature~(F))

  ) +
  theme(legend.position = "bottom")+
guides(fill = guide_legend(keywidth = 1, keyheight = 1),
    linetype=guide_legend(keywidth = 3, keyheight = 1)) +
  labs(color="Node",x="Time (Date)")
ggsave("figs/gravi_climate.png", width = 20, height = 20, units = "cm")

```

VPD
```{r , echo=FALSE}

#(0.611 * 10^ (7.5 * T / (237 +T)) * (1− RH/100)
 
climate_gravimetric_all %>% 
  mutate (daten = date(datetime),tempF = `Climate Temperature(°F)`,rh = `Climate Humidity(%Rh)`)%>% 
     filter(date(datetime) >= "2021-04-22" ) %>%
       filter(date(datetime) <= "2021-04-28" ) %>%
  mutate(vpd = (0.611 * 10^((7.5 * tempF )/(237 + tempF)) * ( 1- (rh/100)))) %>% 
  ggplot( aes(x=datetime, y=vpd))  +
    geom_line(color='red') +
    geom_point() +
    labs(x="Time (Date)", y="VPD (kPa)",colour = "Hibiscus",title = "") +
   theme_minimal(base_size = 18) +
  theme(legend.position = c(1, 0.0050))

ggsave("figs/gravi_climate_vpd.png", width = 20, height = 20, units = "cm")
```

```{r , echo=FALSE}

#(0.611 * 10^ (7.5 * T / (237 +T)) * (1− RH/100)
 
climate_gravimetric_all %>% 
  mutate (daten = date(datetime),tempF = `Climate Temperature(°F)`,
          rh = `Climate Humidity(%Rh)`,
          sr= `TCAP; Broadcast Information; Outdoor Light Energy(W/m²)`)%>% 
     filter(date(datetime) >= "2021-04-22" ) %>%
       filter(date(datetime) <= "2021-04-28" ) %>%
  mutate(vpd = (0.611 * 10^((7.5 * tempF )/(237 + tempF)) * ( 1- (rh/100)))) %>% 
  ggplot( aes(x=datetime, y=sr))  +
    geom_line(color='red') +
    geom_point() +
    labs(x="Time (Date)", y="Outdoor Light Energy(W/m²)",colour = "Hibiscus",title = "") +
   theme_minimal(base_size = 18) +
  theme(legend.position = c(1, 0.0050))

ggsave("figs/gravi_climate_energy.png", width = 20, height = 20, units = "cm")
```

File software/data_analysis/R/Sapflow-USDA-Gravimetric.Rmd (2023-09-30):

---
title: "Sapflow - USDA Gravimetric"
author: "Aji John@DotMote Labs"
date: "05/01/2021"
output:
  pdf_document: default
  html_document: default
---

# Running notebook for the Sapflow data captured by Sapflow nodes (DotmoteLabs)

```{r , include=FALSE}
knitr::opts_chunk$set(echo = TRUE)
```

## Introduction 

Sapflow measurements help with tree water use that can be exteded to canopy level transpiration assessments.

```{r }
library(knitr)
library(tidyverse)
library(lubridate)
```

## Load helper functions

```{r, include=FALSE}
## Summarizes data.
## Gives count, mean, standard deviation, standard error of the mean, and confidence interval (default 95%).
##   data: a data frame.
##   measurevar: the name of a column that contains the variable to be summariezed
##   groupvars: a vector containing names of columns that contain grouping variables
##   na.rm: a boolean that indicates whether to ignore NA's
##   conf.interval: the percent range of the confidence interval (default is 95%)
summarySE <- function(data=NULL, measurevar, groupvars=NULL, na.rm=FALSE,
                      conf.interval=.95, .drop=TRUE) {
    library(plyr)

    # New version of length which can handle NA's: if na.rm==T, don't count them
    length2 <- function (x, na.rm=FALSE) {
        if (na.rm) sum(!is.na(x))
        else       length(x)
    }

    # This does the summary. For each group's data frame, return a vector with
    # N, mean, and sd
    datac <- ddply(data, groupvars, .drop=.drop,
      .fun = function(xx, col) {
        c(N    = length2(xx[[col]], na.rm=na.rm),
          mean = mean   (xx[[col]], na.rm=na.rm),
          sd   = sd     (xx[[col]], na.rm=na.rm)
        )
      },
      measurevar
    )

    # Rename the "mean" column    
    datac <- rename(datac, c("mean" = measurevar))

    datac$se <- datac$sd / sqrt(datac$N)  # Calculate standard error of the mean

    # Confidence interval multiplier for standard error
    # Calculate t-statistic for confidence interval: 
    # e.g., if conf.interval is .95, use .975 (above/below), and use df=N-1
    ciMult <- qt(conf.interval/2 + .5, datac$N-1)
    datac$ci <- datac$se * ciMult

    return(datac)
}
```

## Verify the input files

```{r pressure, echo=FALSE}
sapflow_usda_2021_7<-  read_csv('./data/sapflow-usda-7_2021-04-16_to_2021-05-01.csv')

# Tell R studio that timestamp is already in MDT
sapflow_usda_2021_7$dateP <- as_datetime(sapflow_usda_2021_7$timestamp, tz="America/Denver")

sapflow_usda_2021_8<-  read_csv('./data/sapflow-usda-8_2021-04-16_to_2021-05-01.csv')

# Tell R studio that timestamp is already in MDT
sapflow_usda_2021_8$dateP <- as_datetime(sapflow_usda_2021_8$timestamp, tz="America/Denver")

sapflow_usda_2021_9<-  read_csv('./data/sapflow-usda-9_2021-04-16_to_2021-05-01.csv')

# Tell R studio that timestamp is already in MDT
sapflow_usda_2021_9$dateP <- as_datetime(sapflow_usda_2021_9$timestamp, tz="America/Denver")

sapflow_usda_2021_10<-  read_csv('./data/sapflow-usda-10_2021-04-16_to_2021-05-01.csv')

# Tell R studio that timestamp is already in MDT
sapflow_usda_2021_10$dateP <- as_datetime(sapflow_usda_2021_10$timestamp, tz="America/Denver")

```

## Run summary analysis

```{r }
sapflow_usda_2021 <-  rbind(sapflow_usda_2021_7,
                            sapflow_usda_2021_8,
                            sapflow_usda_2021_9,
                            sapflow_usda_2021_10)

```

## Plot the raw heat ratio data 

```{r }
sapflow_usda_2021 %>% mutate(meanhr = meanHeatRatio) %>%
  filter(!meanhr =='NaN') %>% mutate(mr=as.numeric(meanhr)) %>%
     mutate(node = as.factor(nodeId),Vh = log(mr),hr = hour(date)) %>%
      filter(date(dateP) == "2021-04-25" ) %>%
  #filter(nodeId %in% c("sapflow-dotmote-labs-2" ,"sapflow-dotmote-labs-3", "sapflow-dotmote-labs-4","sapflow-dotmote-labs-5")) %>%
  ggplot() + geom_point(aes(dateP,mr,color=node) )  +
  facet_grid(~node) +
  theme_classic() + labs(x="Date",y="Mean HR", title = "Node 7-10 USDA - Gravimetric Maize", caption="Source : dotmotelabs.com") +
    theme(axis.text.x = element_text(angle = 90, hjust = 1))
  
```

## Verify diurnal 

## Do zero offsetting 

Plot alternatively, but do offsetting by zeroing out the heatratio by using the values from hrs 0,1 and 2. Assumption being around hours (0-2), ideally no sapflow in plants.

```{r , echo=TRUE}

usda_7_offset <- sapflow_usda_2021 %>%  mutate(meanhr = meanHeatRatio,hr = hour(dateP)) %>%
  filter(!meanhr =='NaN') %>% 
  filter(nodeId %in% c("sapflow-usda-7"))  %>% 
  filter( hr %in% c(0,1,2)) %>% summarise(mhr = mean(meanhr))

usda_8_offset <- sapflow_usda_2021 %>%  mutate(meanhr = meanHeatRatio,hr = hour(dateP)) %>%
  filter(!meanhr =='NaN') %>% 
  filter(nodeId %in% c("sapflow-usda-8"))  %>%
  filter( hr %in% c(0,1,2)) %>% summarise(mhr = mean(meanhr))

usda_9_offset <- sapflow_usda_2021 %>%  mutate(meanhr = meanHeatRatio,hr = hour(dateP)) %>%
  filter(!meanhr =='NaN') %>% 
  filter(nodeId %in% c("sapflow-usda-9"))  %>% 
  filter( hr %in% c(0,1,2)) %>% summarise(mhr = mean(meanhr))

usda_10_offset <- sapflow_usda_2021 %>%  mutate(meanhr = meanHeatRatio,hr = hour(dateP)) %>%
  filter(!meanhr =='NaN') %>% 
  filter(nodeId %in% c("sapflow-usda-10"))  %>% 
  filter( hr %in% c(0,1,2)) %>% summarise(mhr = mean(meanhr))

sapflow_usda_2021_adjusted <- sapflow_usda_2021
sapflow_usda_2021_adjusted$hr = hour(sapflow_usda_2021$dateP)
sapflow_usda_2021_adjusted$mr <- 0

sapflow_usda_2021_adjusted[sapflow_usda_2021_adjusted$nodeId == "sapflow-usda-7",]$mr =  sapflow_usda_2021_adjusted[sapflow_usda_2021$nodeId == "sapflow-usda-7",]$meanHeatRatio + (1-as.numeric(usda_7_offset))

sapflow_usda_2021_adjusted[sapflow_usda_2021_adjusted$nodeId == "sapflow-usda-8",]$mr =  sapflow_usda_2021_adjusted[sapflow_usda_2021$nodeId == "sapflow-usda-8",]$meanHeatRatio + (1-as.numeric(usda_8_offset))

sapflow_usda_2021_adjusted[sapflow_usda_2021_adjusted$nodeId == "sapflow-usda-9",]$mr =  sapflow_usda_2021_adjusted[sapflow_usda_2021$nodeId == "sapflow-usda-9",]$meanHeatRatio + (1-as.numeric(usda_9_offset))

sapflow_usda_2021_adjusted[sapflow_usda_2021_adjusted$nodeId == "sapflow-usda-10",]$mr =  sapflow_usda_2021_adjusted[sapflow_usda_2021$nodeId == "sapflow-usda-10",]$meanHeatRatio + (1-as.numeric(usda_10_offset))

#SE 
sapflow_usda_2021_adjusted_se <- summarySE(sapflow_usda_2021_adjusted, measurevar="mr", groupvars=c("nodeId","hr"))

# TODO VPD SE

```

## Plot the adjusted with original 

```{r , echo=TRUE}

sapflow_usda_2021 %>% 
  mutate(node = as.factor(nodeId),hr = hour(dateP)) %>%
  mutate(mr = meanHeatRatio) %>%
  ggplot() + geom_point(aes(hr,mr,color=node) )  +
  facet_grid(~nodeId) +
  theme_classic() + labs(x="Date",y="Mean HR", title = "Node 7-10 USDA - Gravimetric Maize", caption="Source : dotmotelabs.com") +
    theme(axis.text.x = element_text(angle = 90, hjust = 1))

```

```{r , echo=TRUE}

sapflow_usda_2021_adjusted %>% 
  mutate(node = as.factor(nodeId),hr = hour(dateP)) %>%
  ggplot() + geom_point(aes(hr,mr,color=node) )  +
  facet_grid(~nodeId) +
  theme_classic() + labs(x="Date",y="Mean HR", title = "Node 7-10 USDA - Gravimetric Maize", caption="Source : dotmotelabs.com") +
    theme(axis.text.x = element_text(angle = 90, hjust = 1))

```

## Compare Original and Adjusted HR

```{r , echo=TRUE}

lm(sapflow_usda_2021_adjusted$meanHeatRatio~sapflow_usda_2021_adjusted$mr)

sapflow_usda_2021_adjusted %>% 
  ggplot() +
  geom_point(aes(meanHeatRatio,mr,color=nodeId)) +
  theme_minimal(base_size = 14)
```

## Heat pulse velocity

```{r , echo=TRUE}

sapflow_usda_2021_adjusted %>% 
  mutate (sv = log(mr) *3600 * (0.0025/0.6) ,daten = date(dateP))%>% 
#        filter(date(dateP) == "2020-12-01" ) %>%
 # filter(nodeId=="sapflow-dotmote-labs-2" )  %>% 
  ggplot() +
   geom_point(aes(x = dateP, y=sv,color=nodeId)) +
   geom_line(aes(x = dateP, y=sv,color=nodeId)) +
    theme_minimal() + scale_x_datetime(date_minor_breaks = "1 day") + 

  scale_y_continuous(
    # Features of the first axis
    name = expression(~V[h] (cm~h^{"-1"}))

  ) +
  theme(legend.position = c(.17, .6))+
guides(fill = guide_legend(keywidth = 1, keyheight = 1),
    linetype=guide_legend(keywidth = 3, keyheight = 1))

```
## Smooth

```{r , echo=TRUE}

sapflow_usda_2021_adjusted %>% 
  mutate (sv = log(mr) *3600 * (0.0025/0.6) ,daten = date(dateP))%>% 
  #filter(date(dateP) == "2021-03-20" ) %>%
 # filter(nodeId=="sapflow-dotmote-labs-2" )  %>% 
  ggplot() +
   geom_point(aes(x = hr, y=sv,color=nodeId)) +
  geom_smooth(aes(x = hr, y=sv,color=nodeId)) +
    theme_minimal() + 
  #scale_x_datetime(date_minor_breaks = "1 day") + 

  scale_y_continuous(
    # Features of the first axis
    name = expression(~V[h] (cm~h^{"-1"}))

  ) +
  facet_wrap(~date(dateP) ) +

  theme(legend.position = "bottom")+
guides(fill = guide_legend(keywidth = 1, keyheight = 1),
    linetype=guide_legend(keywidth = 3, keyheight = 1))
ggsave("figs/usda-graivimetric-Maize-vh-smoothed.png", width = 20, height = 20, units = "cm")

```

## Heat pulse velocity 1 to 15

```{r , echo=TRUE}

sapflow_usda_2021_adjusted %>% 
  mutate (sv = log(mr) *3600 * (0.0025/0.6) ,daten = date(dateP))%>% 
#        filter(date(dateP) == "2020-12-01" ) %>%
          filter(date(dateP) >= "2021-04-20" ) %>%
   filter(date(dateP) <= "2021-04-29" ) %>%
 # filter(nodeId=="sapflow-dotmote-labs-2" )  %>% 
  ggplot() +
   geom_point(aes(x = dateP, y=sv,color=nodeId)) +
   geom_line(aes(x = dateP, y=sv,color=nodeId)) +
    theme_minimal() + scale_x_datetime(date_minor_breaks = "1 day") + 

  scale_y_continuous(
    # Features of the first axis
    name = expression(~V[h] (cm~h^{"-1"}))

  ) +
  theme(legend.position = c(.17, .6))+
    labs(color='Node ID',x="Time (Date)") +
guides(fill = guide_legend(keywidth = 1, keyheight = 1),
    linetype=guide_legend(keywidth = 3, keyheight = 1))
ggsave("figs/usda-graivimetric-Maize-stress-event.png", width = 20, height = 20, units = "cm")

```

## Mass flow

```{r , echo=TRUE}

sapflow_usda_2021_adjusted %>% 
  mutate (sv = log(mr) *3600 * (0.0025/0.6) ,daten = date(dateP))%>% 
   mutate (vs =1.7 * sv )%>% 
   mutate (flow = 3.14 * (1.5)^2 *vs )%>% 
   #     filter(date(dateP) == "2021-03-18" ) %>%
 # filter(nodeId=="sapflow-dotmote-labs-2" )  %>% 
  ggplot() +
   geom_point(aes(x = dateP, y=flow,color=nodeId)) +
   geom_line(aes(x = dateP, y=flow,color=nodeId)) +
    theme_minimal() + scale_x_datetime(date_minor_breaks = "1 day") + 

  scale_y_continuous(
    # Features of the first axis
    #name = expression(~V[h] (cm~h^{"-1"}))
       # Features of the first axis
    name = expression("Sapflow rate"~J~(g~h^{"-1"})),
  ) +
  theme(legend.position = c(.17, .8))+
  labs(color='Node ID',x="Time (Date)") +
guides(fill = guide_legend(keywidth = 1, keyheight = 1),
    linetype=guide_legend(keywidth = 3, keyheight = 1))

```

## Get the scale data
```{r , echo=TRUE}

gravimetric_all <- readxl::read_xlsx('./data/Maize 4-16 to 4-30-21 Scale Data all MDT.xlsx')
gravimetric_all_raw <- readxl::read_xlsx('./data/Maize 4-16 to 4-30-21 Scale Data all MDT.xlsx',
                                         sheet ='Scales Raw Data' )
gravimetric_all_raw$time <- paste(lubridate::hour(gravimetric_all_raw$`Time (MDT)`),
                                      lubridate::minute(gravimetric_all_raw$`Time (MDT)`),
                                      lubridate::second(gravimetric_all_raw$`Time (MDT)`),sep = ":")
gravimetric_all_raw$datetime <- lubridate::as_datetime(trimws(paste(lubridate::as_date(gravimetric_all_raw$Date),
                                      gravimetric_all_raw$time," ")), tz="America/Denver")

```

## Map the patterns for Sunny days with Cloudy/Rainy Days - Use Agrimet. Use Sapflow velocity curves. Maybe above a threshold of 10 are viable days. 

```{r , echo=TRUE}

gravimetric_all_raw %>% 
  mutate (daten = date(datetime),weight = `Weight(kg)`)%>% 
     filter(date(datetime) >= "2021-04-22" ) %>%
       filter(date(datetime) <= "2021-04-28" ) %>%
 # filter(nodeId=="sapflow-dotmote-labs-2" )  %>% 
  ggplot() +
   geom_point(aes(x = datetime, y=weight,color=Dotmote)) +
   geom_line(aes(x = datetime, y=weight,color=Dotmote)) +
    theme_minimal() + scale_x_datetime(date_minor_breaks = "1 day") + 

  scale_y_continuous(
    # Features of the first axis
    name = expression(~Weight~(Kg))

  ) +
  theme(legend.position = "bottom")+
guides(fill = guide_legend(keywidth = 1, keyheight = 1),
    linetype=guide_legend(keywidth = 3, keyheight = 1)) +
  labs(color="Node",x="Time (Date)")
ggsave("figs/gravi_plot.png", width = 20, height = 20, units = "cm")

```
```{r , echo=TRUE}

gravimetric_all_raw %>% 
  mutate (daten = date(datetime),weight = `Weight(kg)`)%>% 
     filter(date(datetime) >= "2021-04-28" ) %>%
       filter(date(datetime) <= "2021-04-28" ) %>%
 # filter(nodeId=="sapflow-dotmote-labs-2" )  %>% 
  ggplot() +
   geom_point(aes(x = datetime, y=weight,color=Dotmote)) +
   geom_line(aes(x = datetime, y=weight,color=Dotmote)) +
    theme_minimal(base_size = 18) + scale_x_datetime(date_minor_breaks = "1 day") + 

  scale_y_continuous(
    # Features of the first axis
    name = expression(~Weight~(Kg))

  ) +
  theme(legend.position = "bottom")+
guides(fill = guide_legend(keywidth = 1, keyheight = 1),
    linetype=guide_legend(keywidth = 3, keyheight = 1)) +
  labs(color="Node",x="Time (Date)")
ggsave("figs/gravi_plot_28.png", width = 20, height = 20, units = "cm")

```

```{r , echo=TRUE}
sapflow_usda_2021_adjusted %>% 
  mutate (sv = log(mr) *3600 * (0.0025/0.6) ,daten = date(dateP))%>% 
        filter(date(dateP) >= "2021-04-22" ) %>%
       filter(date(dateP) <= "2021-04-28" ) %>%
 # filter(nodeId=="sapflow-dotmote-labs-2" )  %>% 
  ggplot() +
   geom_point(aes(x = dateP, y=sv,color=nodeId)) +
   geom_line(aes(x = dateP, y=sv,color=nodeId)) +
    theme_minimal() + scale_x_datetime(date_minor_breaks = "1 day") + 

  scale_y_continuous(
    # Features of the first axis
    name = expression(~V[h] (cm~h^{"-1"}))

  ) +
  theme(legend.position = "bottom")+
guides(fill = guide_legend(keywidth = 1, keyheight = 1),
    linetype=guide_legend(keywidth = 3, keyheight = 1)) +
  labs(color="Node",x="Time (Date)")
ggsave("figs/sap_plot.png", width = 20, height = 20, units = "cm")
```

```{r , echo=TRUE}
sapflow_usda_2021_adjusted %>% 
  mutate (sv = log(mr) *3600 * (0.0025/0.6) ,daten = date(dateP))%>% 
        filter(date(dateP) >= "2021-04-22" ) %>%
       filter(date(dateP) <= "2021-04-28" ) %>%
 # filter(nodeId=="sapflow-dotmote-labs-2" )  %>% 
  ggplot() +
   geom_smooth(aes(x = dateP, y=sv,color=nodeId)) +
   #geom_line(aes(x = dateP, y=sv,color=nodeId)) +
    theme_minimal(base_size = 18) + scale_x_datetime(date_minor_breaks = "1 day") + 

  scale_y_continuous(
    # Features of the first axis
    name = expression(~V[h] (cm~h^{"-1"}))

  ) +
  theme(legend.position = "bottom")+
guides(fill = guide_legend(keywidth = 1, keyheight = 1),
    linetype=guide_legend(keywidth = 3, keyheight = 1)) +
  labs(color="Node",x="Time (Date)")
ggsave("figs/sap_smmoth_plot.png", width = 28, height = 15, units = "cm")
```

```{r , echo=TRUE}

usda_gravi <- gravimetric_all_raw %>% 
  mutate (daten = date(datetime),weight = `Weight(kg)`)%>% 
     filter(date(datetime) >= "2021-04-24" ) %>%
       filter(date(datetime) <= "2021-04-24" ) %>%
 # filter(nodeId=="sapflow-dotmote-labs-2" )  %>% 
  ggplot() +
   geom_point(aes(x = datetime, y=weight,color=Dotmote)) +
   geom_line(aes(x = datetime, y=weight,color=Dotmote)) +
    theme_minimal() + scale_x_datetime(date_minor_breaks = "1 day") + 

  scale_y_continuous(
    # Features of the first axis
    name = expression(~Weight~(Kg))

  ) +
  theme(legend.position = "bottom")+
guides(fill = guide_legend(keywidth = 1, keyheight = 1),
    linetype=guide_legend(keywidth = 3, keyheight = 1)) +
  labs(color="Node",x="Time (Date)")
```

```{r , echo=TRUE}

sapflow_usda <- sapflow_usda_2021_adjusted %>% 
  mutate (sv = log(mr) *3600 * (0.0025/0.6) ,daten = date(dateP))%>% 
       filter(date(dateP) == "2021-04-24" ) %>%
 # filter(nodeId=="sapflow-dotmote-labs-2" )  %>% 
  ggplot() +
   geom_point(aes(x = dateP, y=sv,color=nodeId)) +
   geom_line(aes(x = dateP, y=sv,color=nodeId)) +
    theme_minimal() + scale_x_datetime(date_minor_breaks = "1 day") + 

  scale_y_continuous(
    # Features of the first axis
    name = expression(~V[h] (cm~h^{"-1"}))

  ) +
  theme(legend.position = "bottom")+
guides(fill = guide_legend(keywidth = 1, keyheight = 1),
    linetype=guide_legend(keywidth = 3, keyheight = 1)) +
  labs(color="Node",x="Time (Date)")

```

```{r , echo=TRUE}
library(patchwork)

usda_gravi / sapflow_usda
ggsave("figs/gravi_sapflow_usda.png", width = 20, height = 20, units = "cm")
```

# try the correlation
```{r , echo=TRUE}

usda_gravi_24 <- gravimetric_all_raw %>% 
  mutate (daten = date(datetime),weight = `Weight(kg)`, 
          hr = hour(datetime), mints = minute(datetime))%>% 
     filter(date(datetime) >= "2021-04-24" ) %>%
       filter(date(datetime) <= "2021-04-24" ) %>%
  as.data.frame()

usda_gravi_all <- gravimetric_all_raw %>% 
  mutate (daten = date(datetime),weight = `Weight(kg)`, 
          hr = hour(datetime), mints = minute(datetime))%>% 
     filter(date(datetime) >= "2021-04-22" ) %>%
       filter(date(datetime) <= "2021-04-28" ) %>%
  as.data.frame()

usda_gravi_24_8 <- gravimetric_all_raw %>% 
  mutate (daten = date(datetime),weight = `Weight(kg)`, 
          hr = hour(datetime), mints = minute(datetime))%>% 
     filter(date(datetime) >= "2021-04-24" ) %>%
       filter(date(datetime) <= "2021-04-24" ) %>%
  filter(Dotmote =='USDA8') %>%
  as.data.frame()

 #
sapflow_usda_24 <- sapflow_usda_2021_adjusted %>% 
  mutate (sv = log(mr) *3600 * (0.0025/0.6) ,daten = date(dateP))%>% 
       filter(date(dateP) == "2021-04-24" ) %>%
  as.data.frame()

sapflow_usda_all <- sapflow_usda_2021_adjusted %>% 
  mutate (sv = log(mr) *3600 * (0.0025/0.6) ,daten = date(dateP))%>% 
       filter(date(dateP) >= "2021-04-22" ) %>%
     filter(date(dateP) <= "2021-04-28" ) %>%
  as.data.frame()

sapflow_usda_24_8 <- sapflow_usda_2021_adjusted %>% 
  mutate (sv = log(mr) *3600 * (0.0025/0.6) ,daten = date(dateP))%>% 
       filter(date(dateP) == "2021-04-24" & nodeId=='sapflow-usda-8') %>%
  as.data.frame()

```

```{r , echo=TRUE}

msv_s8 <- sapflow_usda_24_8 %>% 
   group_by(nodeId,hr) %>% 
 # arrange(nodeId, hr, sv) %>% 
  dplyr::summarise(m_sv = mean(sv)) %>%
  as.data.frame()  

msv_s_all <- sapflow_usda_all %>% 
   group_by(daten,nodeId,hr) %>% 
 # arrange(nodeId, hr, sv) %>% 
  dplyr::summarise(m_sv = mean(sv)) %>%
  as.data.frame()  

msv_s_all_7 <- sapflow_usda_all %>% 
  filter(nodeId=='sapflow-usda-7') %>%
   group_by(daten,nodeId,hr) %>% 
 # arrange(nodeId, hr, sv) %>% 
  dplyr::summarise(m_sv = mean(sv)) %>%
  as.data.frame()  

msv_s_all_8 <- sapflow_usda_all %>% 
  filter(nodeId=='sapflow-usda-8') %>%
   group_by(daten,nodeId,hr) %>% 
 # arrange(nodeId, hr, sv) %>% 
  dplyr::summarise(m_sv = mean(sv)) %>%
  as.data.frame()  

msv_s_all_9 <- sapflow_usda_all %>% 
  filter(nodeId=='sapflow-usda-9') %>%
   group_by(daten,nodeId,hr) %>% 
 # arrange(nodeId, hr, sv) %>% 
  dplyr::summarise(m_sv = mean(sv)) %>%
  as.data.frame()  

msv_s_all_10 <- sapflow_usda_all %>% 
  filter(nodeId=='sapflow-usda-10') %>%
   group_by(daten,nodeId,hr) %>% 
 # arrange(nodeId, hr, sv) %>% 
  dplyr::summarise(m_sv = mean(sv)) %>%
  as.data.frame()  

usda_gravi_24_8_weight_hrly <-  usda_gravi_24_8 %>%
  group_by(Dotmote,hr) %>%
    dplyr::summarise(m_weight= mean(weight)) %>%
as.data.frame()  

usda_gravi_all_weight_hrly <-  usda_gravi_all %>%
  group_by(daten,Dotmote,hr) %>%
    dplyr::summarise(m_weight= mean(weight)) %>%
as.data.frame()  

usda_gravi_24_8_weight_hrly_abs <- usda_gravi_24_8_weight_hrly %>%
  group_by(Dotmote,hr) %>%
  mutate(diff = abs(m_weight - lag(m_weight)) ) %>%
  as.data.frame()

usda_gravi_all_weight_hrly_abs <- usda_gravi_all_weight_hrly %>%
  group_by(daten,Dotmote,hr) %>%
  mutate(diff = abs(m_weight - lag(m_weight)) ) %>%
  as.data.frame()

usda_gravi_all_weight_hrly_abs_7 <- usda_gravi_all_weight_hrly %>%
  filter(Dotmote == 'USDA7')  %>%
  group_by(daten,Dotmote,hr) %>%
  mutate(diff = abs(m_weight - lag(m_weight)) ) %>%
  as.data.frame()

usda_gravi_all_weight_hrly_abs_8 <- usda_gravi_all_weight_hrly %>%
  filter(Dotmote == 'USDA8')  %>%
  group_by(daten,Dotmote,hr) %>%
  mutate(diff = abs(m_weight - lag(m_weight)) ) %>%
  as.data.frame()

usda_gravi_all_weight_hrly_abs_9 <- usda_gravi_all_weight_hrly %>%
  filter(Dotmote == 'USDA9')  %>%
  group_by(daten,Dotmote,hr) %>%
  mutate(diff = abs(m_weight - lag(m_weight)) ) %>%
  as.data.frame()

usda_gravi_all_weight_hrly_abs_10 <- usda_gravi_all_weight_hrly %>%
  filter(Dotmote == 'USDA10')  %>%
  group_by(daten,Dotmote,hr) %>%
  mutate(diff = abs(m_weight - lag(m_weight)) ) %>%
  as.data.frame()

 summary( lm(usda_gravi_24_8_weight_hrly_abs$diff ~ msv_s8$m_sv))
```

# All the points for a week - Node 8

```{r , echo=FALSE}

msv_s_all_8 %>% 
  mutate(daye = lubridate::day(daten)) %>%
  filter(daye %in% c(27)) %>%
           ggplot() +
geom_smooth(data = usda_gravi_all_weight_hrly_abs_8[usda_gravi_all_weight_hrly_abs_8$daten == c('2021-04-27'),], aes(x=hr,diff,color="GM")) +
geom_smooth(data= msv_s_all_8[msv_s_all_8$daten == c('2021-04-27'),], aes(x=hr, y=m_sv/100 , color="SV"))  +
  theme_minimal(base_size = 18) +
  facet_grid(~daye)+
  labs(color="",x=" Time (Hour)" , y="")
```

# Plot hourly but one day
```{r , echo=FALSE}

ggplot() +
geom_point(data = usda_gravi_24_8_weight_hrly_abs, aes(x=hr,diff,color="GM")) +
geom_point(data= msv_s8, aes(x=hr, y=m_sv/100 , color="SV"))  +
  theme_minimal(base_size = 18) +
  labs(color="",x=" Time (Hour)" , y="")
```

# Plot hourly but smooth it
```{r , echo=FALSE}

ggplot() +
geom_smooth(data = usda_gravi_24_8_weight_hrly_abs, aes(x=hr,diff,color="GM")) +
geom_smooth(data= msv_s8, aes(x=hr, y=m_sv/100 , color="SV"))  +
  theme_minimal(base_size = 18) +
  labs(color="",x=" Time (Hour)" , y="")
```

# Compare , but one node one day

```{r , echo=FALSE}

ggplot() +
geom_point(data = usda_gravi_all_weight_hrly_abs_8[usda_gravi_all_weight_hrly_abs_8$daten=='2021-04-26',], aes(x=hr,diff,color=Dotmote)) +
geom_point(data= msv_s_all_8[msv_s_all_8$daten=='2021-04-26',], aes(x=hr, y=m_sv/100 , color=nodeId))  +
  facet_wrap(.~daten) +
  theme_minimal(base_size = 18) +
  labs(color="",x=" Time (Hour)" , y="")
```
# All days, one node Node 7 perf

```{r , echo=FALSE}

coeff = 100
ggplot() +
  geom_point(data = usda_gravi_all_weight_hrly_abs_7[usda_gravi_all_weight_hrly_abs_7$daten > '2021-04-23',], aes(x=hr,diff,color=Dotmote)) +
  geom_point(data= msv_s_all_7[msv_s_all_7$daten > '2021-04-23', ], aes(x=hr, y=m_sv/coeff , color=nodeId))  +

  facet_wrap(.~daten) +
  scale_y_continuous(
    
    # Features of the first axis
    name = "Flow (kg/hr)" ,
    
    # Add a second axis and specify its features
    sec.axis = sec_axis(~.*(coeff), name=expression(~V[h] (cm~h^{"-1"})))
  ) +
  theme_minimal(base_size = 18) +
  labs(color="",x=" Time (Hour)" , y="")
ggsave("figs/sap_gm_compare.png", width = 28, height = 15, units = "cm")
```

# All days, one node Node 8

```{r , echo=FALSE}

coeff = 100
ggplot() +
  geom_point(data = usda_gravi_all_weight_hrly_abs_8[usda_gravi_all_weight_hrly_abs_8$daten > '2021-04-23',], aes(x=hr,diff,color=Dotmote)) +
  geom_point(data= msv_s_all_8[msv_s_all_8$daten > '2021-04-23', ], aes(x=hr, y=m_sv/coeff , color=nodeId))  +

  facet_wrap(.~daten) +
  scale_y_continuous(
    
    # Features of the first axis
    name = "Flow (kg/hr)" ,
    
    # Add a second axis and specify its features
    sec.axis = sec_axis(~.*(coeff), name=expression(~V[h] (cm~h^{"-1"})))
  ) +
  theme_minimal(base_size = 18) +
  labs(color="",x=" Time (Hour)" , y="")
```
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

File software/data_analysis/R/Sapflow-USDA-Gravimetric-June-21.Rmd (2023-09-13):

---
title: "Sapflow - USDA Gravimetric - Run 4"
author: "Aji John@DotMote Labs"
date: "08/20/2022"
output:
  pdf_document: default
  html_document: default
---

# Running notebook for the Sapflow data captured by Sapflow nodes (DotmoteLabs)

```{r , include=FALSE}
knitr::opts_chunk$set(echo = TRUE)
```

## Introduction 

Sapflow measurements help with tree water use that can be exteded to canopy level transpiration assessments.

```{r }
library(knitr)
library(tidyverse)
library(lubridate)
```

## Load helper functions

```{r, include=FALSE}
## Summarizes data.
## Gives count, mean, standard deviation, standard error of the mean, and confidence interval (default 95%).
##   data: a data frame.
##   measurevar: the name of a column that contains the variable to be summariezed
##   groupvars: a vector containing names of columns that contain grouping variables
##   na.rm: a boolean that indicates whether to ignore NA's
##   conf.interval: the percent range of the confidence interval (default is 95%)
summarySE <- function(data=NULL, measurevar, groupvars=NULL, na.rm=FALSE,
                      conf.interval=.95, .drop=TRUE) {
    library(plyr)

    # New version of length which can handle NA's: if na.rm==T, don't count them
    length2 <- function (x, na.rm=FALSE) {
        if (na.rm) sum(!is.na(x))
        else       length(x)
    }

    # This does the summary. For each group's data frame, return a vector with
    # N, mean, and sd
    datac <- ddply(data, groupvars, .drop=.drop,
      .fun = function(xx, col) {
        c(N    = length2(xx[[col]], na.rm=na.rm),
          mean = mean   (xx[[col]], na.rm=na.rm),
          sd   = sd     (xx[[col]], na.rm=na.rm)
        )
      },
      measurevar
    )

    # Rename the "mean" column    
    datac <- rename(datac, c("mean" = measurevar))

    datac$se <- datac$sd / sqrt(datac$N)  # Calculate standard error of the mean

    # Confidence interval multiplier for standard error
    # Calculate t-statistic for confidence interval: 
    # e.g., if conf.interval is .95, use .975 (above/below), and use df=N-1
    ciMult <- qt(conf.interval/2 + .5, datac$N-1)
    datac$ci <- datac$se * ciMult

    return(datac)
}

```

## Verify the input files of heat ratio

```{r pressure, echo=FALSE}
sapflow_usda_2022_hr_19<-  read_csv('./data/june-2022-gravimetric/heatlog_USDA_19_5_21_to6_14_2022_Scale2_Scale8.csv')
# Tell R studio that timestamp is already in MDT
sapflow_usda_2022_hr_19$dateP <- as_datetime(sapflow_usda_2022_hr_19$endofheatpulse, tz="America/Denver")

sapflow_usda_2022_hr_20<-  read_csv('./data/january-2022-gravimetric/heatlogUSDA20 to 1-5-22.csv')
# Tell R studio that timestamp is already in MDT
sapflow_usda_2022_hr_20$dateP <- as_datetime(sapflow_usda_2022_hr_20$endofheatpulse, tz="America/Denver")

sapflow_usda_2022_hr_25<-  read_csv('./data/january-2022-gravimetric/heatlogUSDA25 to 1-5-22.csv')
# Tell R studio that timestamp is already in MDT
sapflow_usda_2022_hr_25$dateP <- as_datetime(sapflow_usda_2022_hr_25$endofheatpulse, tz="America/Denver")

sapflow_usda_2022_hr_36<-  read_csv('./data/january-2022-gravimetric/heatlogUSDA36 to 1-5-22.csv')
# Tell R studio that timestamp is already in MDT
sapflow_usda_2022_hr_36$dateP <- as_datetime(sapflow_usda_2022_hr_36$endofheatpulse, tz="America/Denver")

```

## Verify the input files

```{r pressure, echo=FALSE}
sapflow_usda_2022_19<-  read_csv('./data/january-2022-gravimetric/datalogUSDA19 to 1-5-22.csv')

# Tell R studio that timestamp is already in MDT
sapflow_usda_2022_19$dateP <- as_datetime(sapflow_usda_2022_19$rtcUnixTimestamp, tz="America/Denver")

sapflow_usda_2022_20<-  read_csv('./data/january-2022-gravimetric/datalogUSDA20 to 1-5-22.csv')

# Tell R studio that timestamp is already in MDT
sapflow_usda_2022_20$dateP <- as_datetime(sapflow_usda_2022_20$rtcUnixTimestamp, tz="America/Denver")

sapflow_usda_2022_25<-  read_csv('./data/january-2022-gravimetric/datalogUSDA25 to 1-5-22.csv')

# Tell R studio that timestamp is already in MDT
sapflow_usda_2022_25$dateP <- as_datetime(sapflow_usda_2022_25$rtcUnixTimestamp, tz="America/Denver")

sapflow_usda_2022_32<-  read_csv('./data/january-2022-gravimetric/datalogUSDA32 to 12-5-21.csv')
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

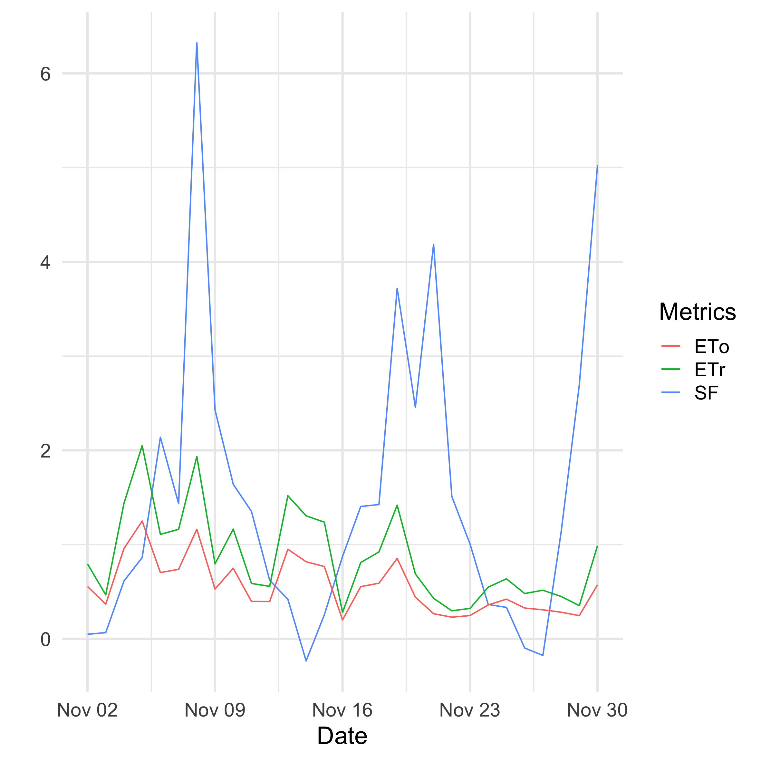
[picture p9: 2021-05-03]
software/data_analysis/R/figs/etvssv.png

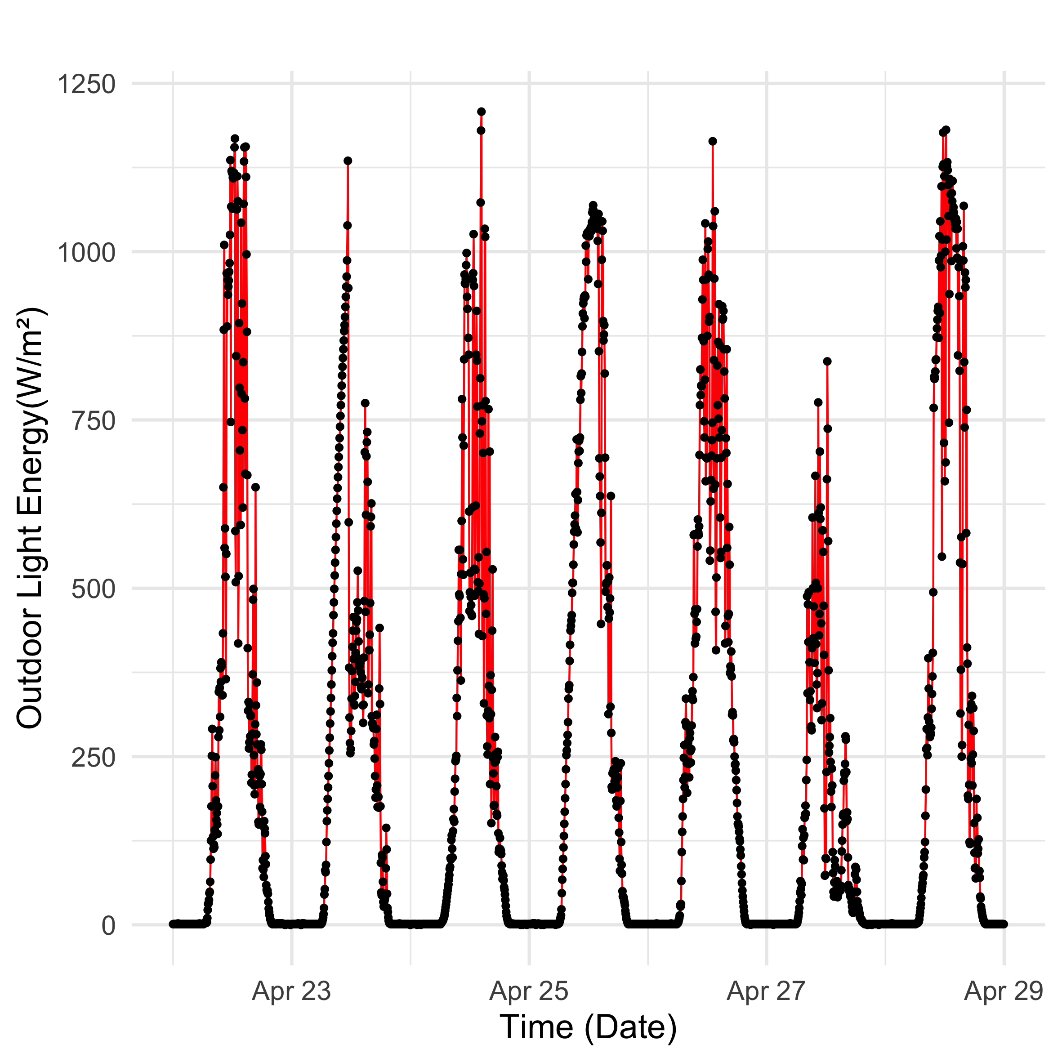
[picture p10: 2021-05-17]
software/data_analysis/R/figs/gravi_climate_energy.png

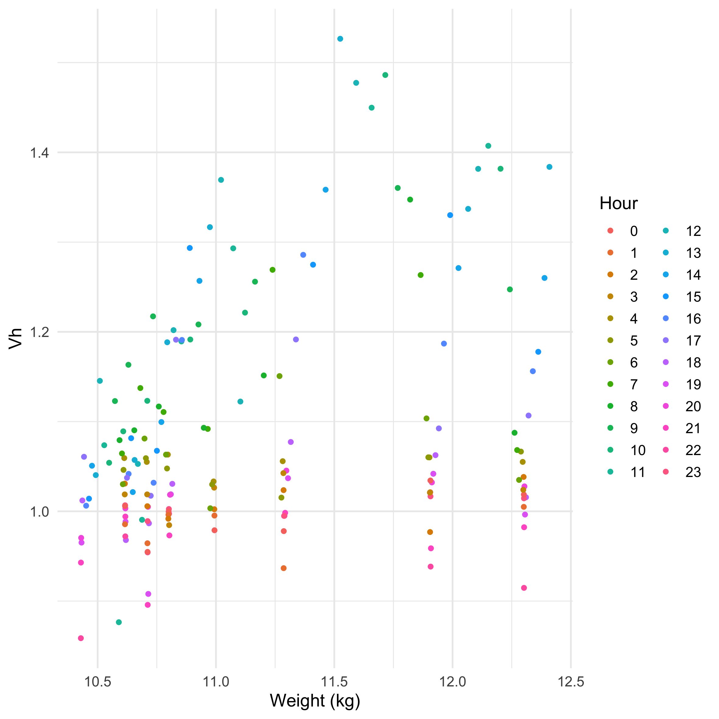
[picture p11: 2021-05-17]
software/data_analysis/R/figs/gravi_sapflow_compare.png

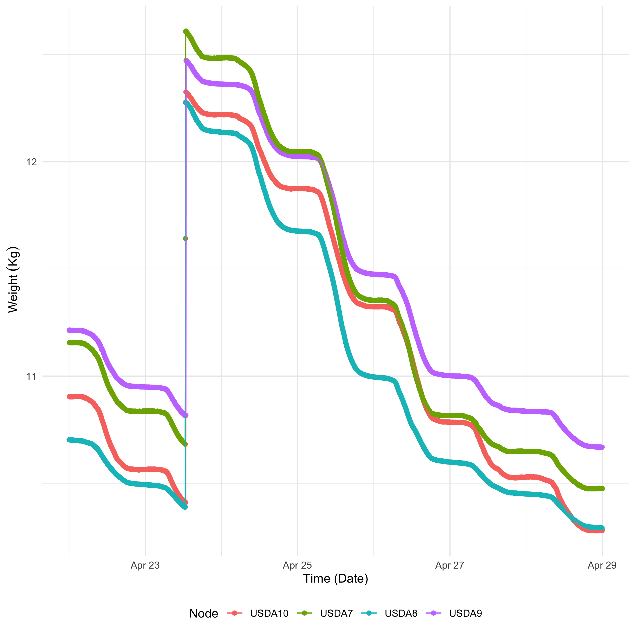
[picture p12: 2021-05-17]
software/data_analysis/R/figs/gravi_plot.png

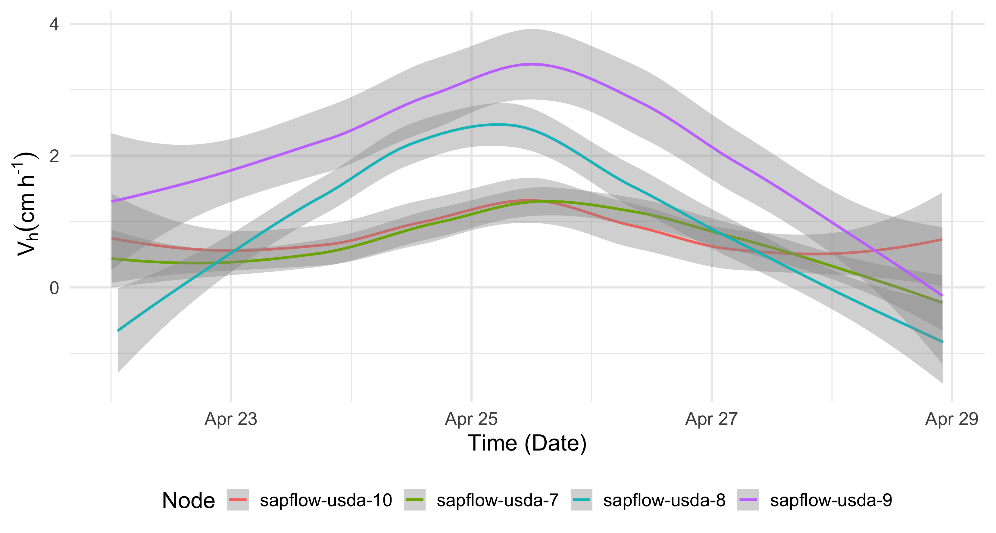
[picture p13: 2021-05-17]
software/data_analysis/R/figs/sap_smmoth_plot.png

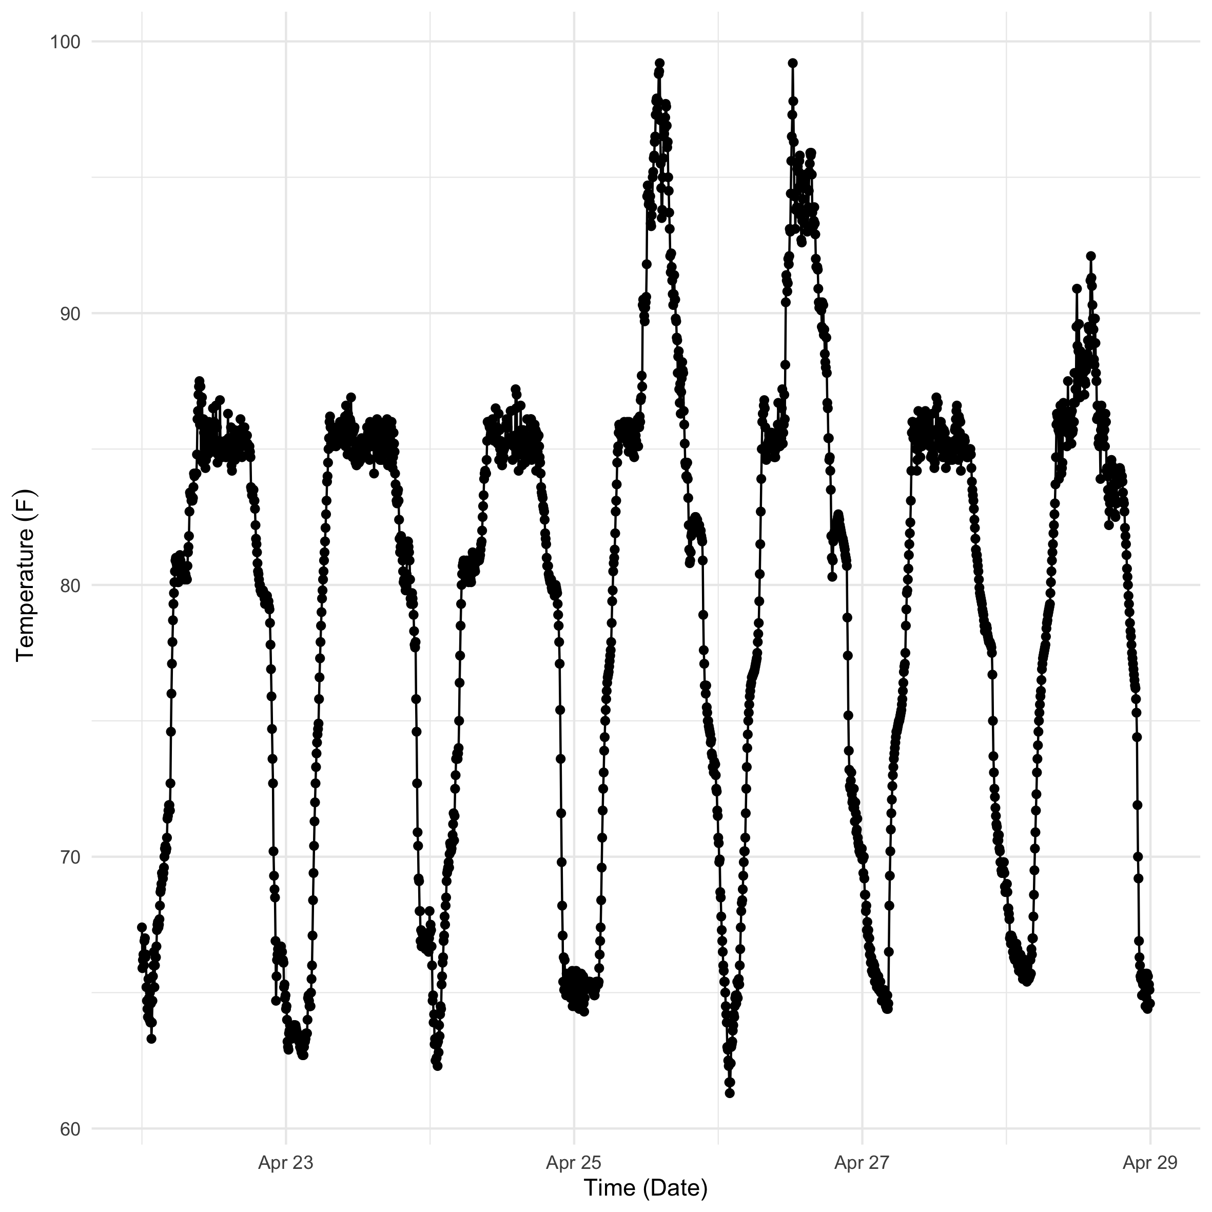
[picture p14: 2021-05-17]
software/data_analysis/R/figs/gravi_climate.png

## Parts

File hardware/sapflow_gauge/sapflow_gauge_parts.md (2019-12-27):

# Sapflow Gauge Parts

sapflow gauge 3d

In order to use the gauge, you'll need to:
1. Build the gauge head; and
2. Connect the gauge head to your microcontroller.

## Gauge Head Parts

Digikey links provided for convenience, but feel free to order from your favorite electronic components distributor.
| Part | Link | Quantity Needed Per Gauge |
|---|---|---|
| HDC2080 Temperature & Humidity Sensor (6-WSON Package) | https://www.digikey.com/product-detail/en/texas-instruments/HDC2080DMBT/296-49482-1-ND/9360700 | 2 |
| DMN3051L-7 Logic Level Mosfet (SOT23 Package) | https://www.digikey.com/product-detail/en/diodes-incorporated/DMN3051L-7/DMN3051LDICT-ND/1964754 | 1 |
| 100 Ohm Resistor (1206 Package) | https://www.digikey.com/product-detail/en/stackpole-electronics-inc/RNCP1206FTD100R/RNCP1206FTD100RCT-ND/2240655 | 1 |
| 270 Ohm Resistor (0603 Package) | https://www.digikey.com/product-detail/en/panasonic-electronic-components/ERJ-3EKF2700V/P270HCT-ND/1746751 | 1 |
| 5K Ohm Resistor (0603 Package) | https://www.digikey.com/product-detail/en/te-connectivity-passive-product/CRGP0603F5K6/A130425CT-ND/8578257 | 2 |
| 10K Ohm Resistor (0603 Package) | https://www.digikey.com/product-detail/en/stackpole-electronics-inc/RNCP0603FTD10K0/RNCP0603FTD10K0CT-ND/2240478 | 1 |
| 0.1 uF Capacitor (0603 Package) | https://www.digikey.com/product-detail/en/samsung-electro-mechanics/CL10B104KB8NNNC/1276-1000-1-ND/3889086 | 2 |

## Gauge Head Connector Parts
You can use any method you'd like to connect the 5 pins (HEAT, 3V3, GND, SCL, SDA) from the gauge head to your microcontroller. We've had good results using RJ11 connectors with CAT3 ethernet cables up to ~10 feet (~3 meters).

| Part | Link |
|---|---|
| RJ11 Breakout Board | https://www.digikey.com/product-detail/en/sparkfun-electronics/BOB-14021/1568-1440-ND/6228638 |
| RJ11 Female Connector | https://www.digikey.com/product-detail/en/amphenol-icc-fci/54601-906002WPLF/609-5080-ND/4242890 |

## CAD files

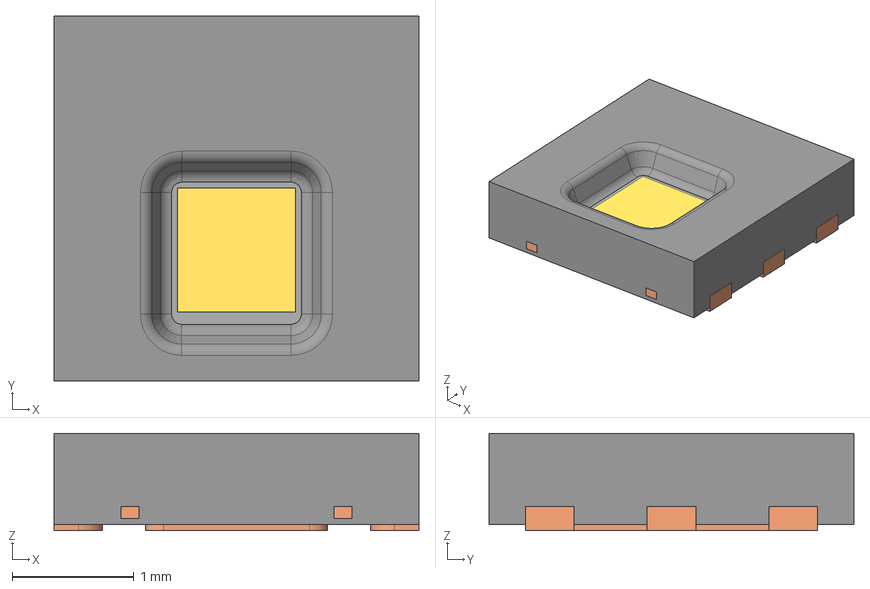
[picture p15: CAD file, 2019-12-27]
hardware/sapflow_gauge/kicad/sapflow_gauge/DMB0006A.stp
3.00 x 3.00 x 0.8 mm
BODY-SON_118_1
FRAME-DMB0006A_77_1_1
FRAME-DMB0006A_77_2_1
FRAME-DMB0006A_77_3_1
FRAME-DMB0006A_77_4_1
FRAME-DMB0006A_77_5_1
FRAME-DMB0006A_77_6_1
FRAME-DMB0006A_77_7_1
PIN1-ID_16_1
DIE_1_1

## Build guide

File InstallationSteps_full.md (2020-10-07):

# Installation Steps
1. [Sensor Installation](#sensorinstallation)
2. [Checklist for D32 Pro (WiFi)](#d32wifi)
3. [Checklist for D32 Pro (Raspberry Pi)](#d32pi)
4. [Checklist for D1 Mini](#d1mini)

-------------------------------

<a href="#top">(Back to top)</a>  

## Sensor Installation                                                  

### Materials: 
* Sensor
* Tape or parafilm
* 2 Twist-ties
* Bubble wrap or styrofoam (~ 5 x 12 cm)
* Aluminum foil (~ 5 x 12 cm)



### Directions:
1. Connect sensor to microcontroller (D32 Pro or D1 Mini).
2. Position sensor on stem (width < 1 cm). On each plant, choose locations of similar height and stem width. Install each sensor facing the same direction and in the same vertical orientation, noting **Temp 1** on the bottom and **Temp 2** on the top (an "E" shape). 
3. Use tape or parafilm to secure the sensor’s straight edge on the stem. The nodes should press firmly against the stem’s surface. 
4. Use 2 twist-ties to tighten and secure the sensor’s hold.
5. When secure in place, wrap piece of bubble wrap or styrofoam around the stem and tape in place. This helps buffer air temperature.
6. Wrap aluminum foil around the bubble wrap and tape in place. This helps buffer light; ensure there are no holes or openings where light can enter. 

      

-------------------------------

<a href="#top">(Back to top)</a> 

## Checklist for D32 Pro (WiFi) 

### Board: [Arduino-ESP32](https://github.com/espressif/arduino-esp32/blob/master/docs/arduino-ide/boards_manager.md)
- [ ] Connect microcontroller via USB.
- [ ] In Arduino, open Preferences and copy release link to Additional Boards Manager URLs. Separate multiple URLs with commas. (Files > Preferences)
- [ ] Open Boards Manager, search **"esp32"** and install. (Tools > Board > Boards Manager)
- [ ] Switch board to **LOLIN D32 PRO**. (Tools > Board)

### Install dependencies:
- [ ] In Library Manager, search and install the following libraries (Tools > Manage Libraries):
    - [Adafruit GFX](https://github.com/adafruit/Adafruit-GFX-Library)
    - [ArduinoJSON](https://arduinojson.org/) by Benoit Blanchon
    - [ESP_DoubleResetDetector](https://github.com/khoih-prog/ESP_DoubleResetDetector) by Khoi Hoang
    - [ESP_WiFiManager](https://github.com/khoih-prog/ESP_WiFiManager) by Khoi Hoang
    - [HDC2080 Arduino Library](https://github.com/lime-labs/HDC2080-Arduino) by Lime Labs
    - [PubSubClient](https://pubsubclient.knolleary.net/) by Nick O'Leary
    - [RTC by Makuna](https://github.com/Makuna/Rtc/wiki) by Michael C. Miller
    - [Time](https://playground.arduino.cc/code/time/) by Michael Margolis
- [ ] These optional libraries can be downloaded online and copied to Arduino Libraries folder in Finder. Comment out applicable lines in script if unused. (In Finder, Arduino > libraries)
    - [LOLIN E-Paper Display Library](https://github.com/wemos/LOLIN_EPD_Library)
    - [WEMOS SHT3x Arduino Library](https://github.com/wemos/WEMOS_SHT3x_Arduino_Library)

### Network settings:
- [ ] Open [D32 Pro script (WiFi)](https://github.com/dotmote/sapflow-usda-6/blob/master/sapflow-usda-6.ino) in Arduino.
- [ ] Verify/Compile and Upload to microcontroller via USB
- [ ] Connect to WiFi: 
    - On phone or computer, select WiFi network **“SAPFLOW_<unique_chip_id>”**. 
    - On next screen, select **“Configuration”**.
    - Select WiFi network, enter password, and select **"Save"**.
    - Wait to connect. “SAPFLOW_<unique_chip_id>” will disappear from network list when complete.
- [ ] NOTES:
    - Once connected, the "SAPFLOW_<unique_chip_id>" network will not reappear when reconnecting to the same network. 
    - If "SAPFLOW_<unique_chip_id>" network does not appear for initial connection, press and hold Reset button on microcontroller for 5 seconds. 
    - The microcontroller might reset itself while attempting to connect to the network.
    
### Check:
- [ ] Operating modes:
    - **Normal:** If microcontroller is successfully connected to the network, the blue LED will be solid only during the heat pulse. Data will be both recorded to the MicroSD card and uploaded online through the dashboard.
    - **Offline:** If microcontroller is in offline mode, the blue LED will blink continuously (~1 blink/second). Data will only be recorded to the MicroSD card.
- [ ] Sign into the [Sapflow Dashboard](https://www.dotmote.com/) to check that data is uploading.

-------------------------------

<a href="#top">(Back to top)</a> 

## Checklist for D32 Pro (Raspberry Pi) 

### Board: [Arduino-ESP32](https://github.com/espressif/arduino-esp32/blob/master/docs/arduino-ide/boards_manager.md)
- [ ] Connect microcontroller via USB.
- [ ] In Arduino, open Preferences and copy release link to Additional Boards Manager URLs. Separate multiple URLs with commas. (Files > Preferences)
- [ ] Open Boards Manager, search **"esp32"** and install. (Tools > Board > Boards Manager)
- [ ] Switch board to **LOLIN D32 PRO**. (Tools > Board)

### Install dependencies:
- [ ] In Library Manager, search and install the following libraries (Tools > Manage Libraries):
    - [Adafruit GFX](https://github.com/adafruit/Adafruit-GFX-Library)
    - [ArduinoJSON](https://arduinojson.org/) by Benoit Blanchon
    - [HDC2080 Arduino Library](https://github.com/lime-labs/HDC2080-Arduino) by Lime Labs
    - [PubSubClient](https://pubsubclient.knolleary.net/) by Nick O'Leary
    - [RTC by Makuna](https://github.com/Makuna/Rtc/wiki) by Michael C. Miller
- [ ] These optional libraries can be downloaded online and copied to Arduino Libraries folder in Finder. Comment out applicable lines in script if unused. (In Finder, Arduino > libraries)
    - [LOLIN E-Paper Display Library](https://github.com/wemos/LOLIN_EPD_Library)
    - [WEMOS SHT3x Arduino Library](https://github.com/wemos/WEMOS_SHT3x_Arduino_Library)
- [ ] NOTE: For PubSubClient, edit PubSubClient.h increase max packet size from **128b to 512b**.
(In Finder, Arduino > libraries > PubSubClient > src > PubSubClient.h > Edit **“#define MQTT_MAX_PACKET_SIZE 512”**)

### Network settings:
- [ ] Open [D32 Pro script (Pi)](https://github.com/dotmote/sapflow/blob/master/software/microcontroller/d32_pro/d32_pro_sapflow_mqtt_sd/d32_pro_sapflow_mqtt_sd.ino) in Arduino. (If microcontroller doesn't have an RTC chip, open [D32 Pro script (no RTC)](https://github.com/dotmote/sapflow/blob/master/software/microcontroller/d32_pro/d32_pro_sapflow_mqtt_noRtc/d32_pro_sapflow_mqtt_noRtc.ino).)
- [ ] ClientID: change `“clientID”`
- [ ] Server/broker IP address: change `“mqtt_server”`
- [ ] Connect to WiFi: enter `“wifi name”` and `“wifi password”`
- [ ] Verify/Compile and Upload to microcontroller via USB

### Check:
- [ ] Open Serial Monitor and check that data is uploading. (Tools > Serial Monitor)
- [ ] Check that Temperatures are not reading negative. If yes, try pressing Reset button on microcontroller several times.
- [ ] Check that data is also transmitting on Raspberry Pi.

-------------------------------

<a href="#top">(Back to top)</a> 

## Checklist for D1 Mini 

### Board: [Arduino-ESP8266](https://github.com/esp8266/Arduino)
- [ ] Connect microcontroller via USB.
- [ ] In Arduino, open Preferences and copy release link (https://arduino.esp8266.com/stable/package_esp8266com_index.json) to Additional Boards Manager URLs. Separate multiple URLs with commas. (Files > Preferences)
- [ ] Open Boards Manager, search **"esp8266"** and install. (Tools > Board > Boards Manager)
- [ ] Switch board to **LOLIN (WEMOS) D1 mini Lite**. (Tools > Board)

### Install dependencies:
- [ ] In Library Manager, search and install the following libraries (Tools > Manage Libraries):
    - [ArduinoJSON](https://arduinojson.org/) by Benoit Blanchon
    - [HDC2080 Arduino Library](https://github.com/lime-labs/HDC2080-Arduino) by Lime Labs
    - [PubSubClient](https://pubsubclient.knolleary.net/) by Nick O'Leary
    - [WiFi Manager](https://github.com/tzapu/WiFiManager) by Tzapu
- [ ] This optional library can be downloaded online and copied to Arduino Libraries folder in Finder. Comment out applicable lines in script if unused. (In Finder, Arduino > libraries)
    - [WEMOS SHT3x Arduino Library](https://github.com/wemos/WEMOS_SHT3x_Arduino_Library)
- [ ] NOTE: For PubSubClient, edit PubSubClient.h increase max packet size from **128b to 512b**.
(In Finder, Arduino > libraries > PubSubClient > src > PubSubClient.h > Edit **“#define MQTT_MAX_PACKET_SIZE 512”**)

### Network settings:
- [ ] Open [D1 Mini script](https://github.com/dotmote/sapflow/blob/master/software/microcontroller/d1_mini/d1_mini_sapflow_mqtt/d1_hdc2080_sapflow_mqtt.ino) in Arduino. 
- [ ] ClientID: change `“clientID”`
- [ ] Server/broker IP address: change `“mqtt_server”`
- [ ] Verify/Compile and Upload to microcontroller via USB
- [ ] Connect to WiFi: 
    - On phone, select WiFi network **“AutoConnectAP”**. 
    - On next screen, select **“Configure WiFi”**.
    - Select WiFi network, enter password, and select **"Save"**.
    - Wait to connect. “AutoConnectAP” will disappear from network list when complete.
- [ ] NOTE: If "AutoConnectAP" network does not appear:
    - Once connected, it will not reappear when reconnecting to the same network.
    - Press and hold Reset button on microcontroller for 5 seconds. 
    - In script, activate `//wifiManager.resetSettings();` to `wifiManager.resetSettings();`. Upload to microcontroller.
    - "AutoConnectAP" network should now appear. Connect through phone.
    - In script, re-comment out `wifiManager.resetSettings();` to `//wifiManager.resetSettings();`. Re-upload to microcontroller.

### Check:
- [ ] Open Serial Monitor and check that data is uploading. (Tools > Serial Monitor)
- [ ] Check that Temperatures are not reading negative. If yes, try pressing Reset button on microcontroller several times.
- [ ] Check that data is also transmitting on Raspberry Pi.

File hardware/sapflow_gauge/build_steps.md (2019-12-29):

# Sapflow Gauge Build Steps

After you have your PCBs and [parts](./sapflow_gauge_parts.md), you'll need to assemble your gauges using the following steps:

1. Put solder paste on each of the exposed PCB pads.
2. Place each component on the PCB in their corresponding spots (i.e., on top of the solder-paste-topped pads).
3. Bake the PCB in a toaster oven (which you'll never use for food, as the fumes are hazardous).

## Educational Resources
- Applying solder paste to a PCB: [EEVBlog #558](https://www.youtube.com/watch?v=M_rO6oPVsws)
- Using a toaster oven to perform solder reflow: [EEVBlog #562](https://www.youtube.com/watch?v=JA-vi2iQ5vA)

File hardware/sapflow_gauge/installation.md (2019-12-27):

# Sapflow Gauge Installation

See [here](https://bio-protocol.org/e2121) for Rob Skelton's excellent in-depth protocol.

## General Steps
1. Place the sapflow gauge onto the stem (<=1 cm in diameter) of a tree/plant.
2. Clamp the sapflow gauge onto the stem, ensuring full contact between the stem and each of the temperature sensors and heating element. Parafilm works quite well with enough windings.
3. Insulate the area around the sapflow gauge using styrofoam/bubblewrap.
4. Wrap the area around the sapflow gauge with reflective material, such as aluminum foil.

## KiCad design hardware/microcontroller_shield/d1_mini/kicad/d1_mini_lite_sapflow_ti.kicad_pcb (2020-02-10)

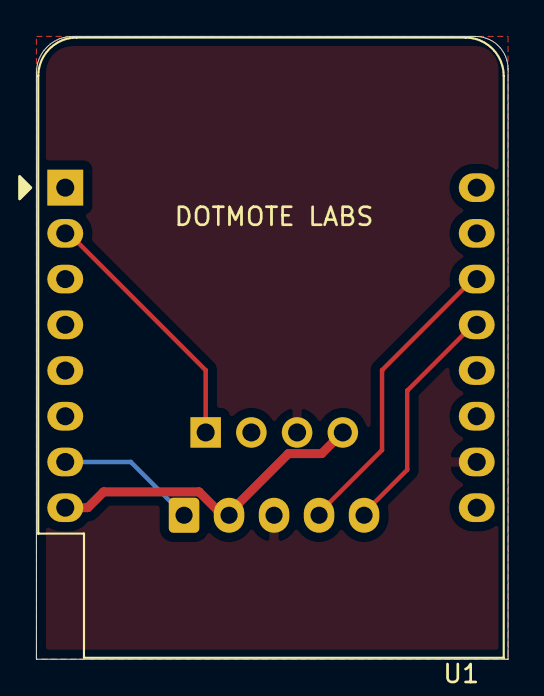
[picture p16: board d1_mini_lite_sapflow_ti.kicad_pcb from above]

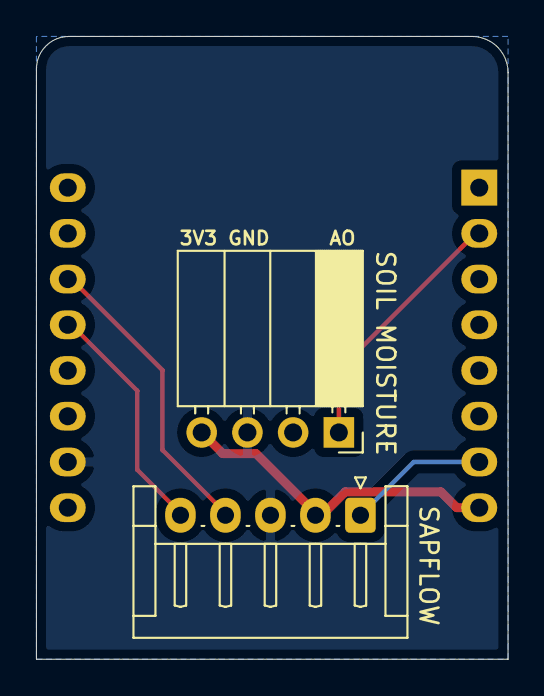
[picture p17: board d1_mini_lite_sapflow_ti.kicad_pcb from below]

Board: 2 copper layers, 26.2 x 34.6 mm, 3 parts (2 on the bottom side), 6 nets.

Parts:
SAPFLOW: sapflow_gauge_5_pin; JST_EH_S5B-EH_1x05_P2.50mm_Horizontal
SOIL MOISTURE: soil_moisture_4_pin; PinSocket_1x04_P2.54mm_Horizontal
U1: WeMos_D1_mini; WEMOS_D1_mini_light

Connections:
+3V3: SAPFLOW.2, SOIL MOISTURE.4, U1.8
GND: SAPFLOW.3, SOIL MOISTURE.3, U1.10
unnamed: SOIL MOISTURE.1, U1.2
unnamed: SAPFLOW.1, U1.7
unnamed: SAPFLOW.5, U1.13
unnamed: SAPFLOW.4, U1.14

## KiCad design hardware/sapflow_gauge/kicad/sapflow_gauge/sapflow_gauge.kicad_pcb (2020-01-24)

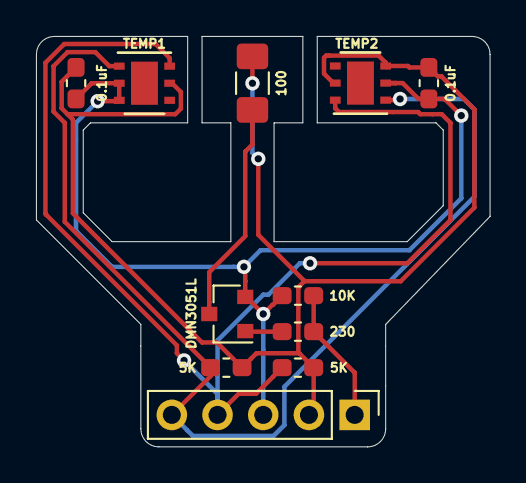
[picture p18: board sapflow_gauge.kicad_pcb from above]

Board: 2 copper layers, 25.2 x 22.8 mm, 11 parts (0 on the bottom side), 7 nets.

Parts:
0.1uF, 0.1uF#2: 0.1uF; C_0603_1608Metric_Pad1.05x0.95mm_HandSolder
5K, 5K#2: 5K; R_0603_1608Metric_Pad1.05x0.95mm_HandSolder
10K: 10K; R_0603_1608Metric_Pad1.05x0.95mm_HandSolder
100: 100; R_1206_3216Metric_Pad1.42x1.75mm_HandSolder
230: 230; R_0603_1608Metric_Pad1.05x0.95mm_HandSolder
 : Conn_01x05_Female; PinHeader_1x05_P2.54mm_Vertical
DMN3051L: DMN3051L; SOT-23
TEMP1, TEMP2: HDC2080; Texas_PWSON-N6

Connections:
+3V3: 0.1uF.1, 0.1uF#2.1, 5K.1, 5K#2.1, 100.2, .2, TEMP1.5, TEMP2.3, TEMP2.5
GND: 0.1uF.2, 0.1uF#2.2, 10K.1, .3, DMN3051L.2, TEMP1.2, TEMP1.3, TEMP2.2
unnamed: 10K.2, 230.1, .1
unnamed: 5K.2, .4, TEMP1.6, TEMP2.6
unnamed: 5K#2.2, .5, TEMP1.1, TEMP2.1
unnamed: 230.2, DMN3051L.1
unnamed: 100.1, DMN3051L.3

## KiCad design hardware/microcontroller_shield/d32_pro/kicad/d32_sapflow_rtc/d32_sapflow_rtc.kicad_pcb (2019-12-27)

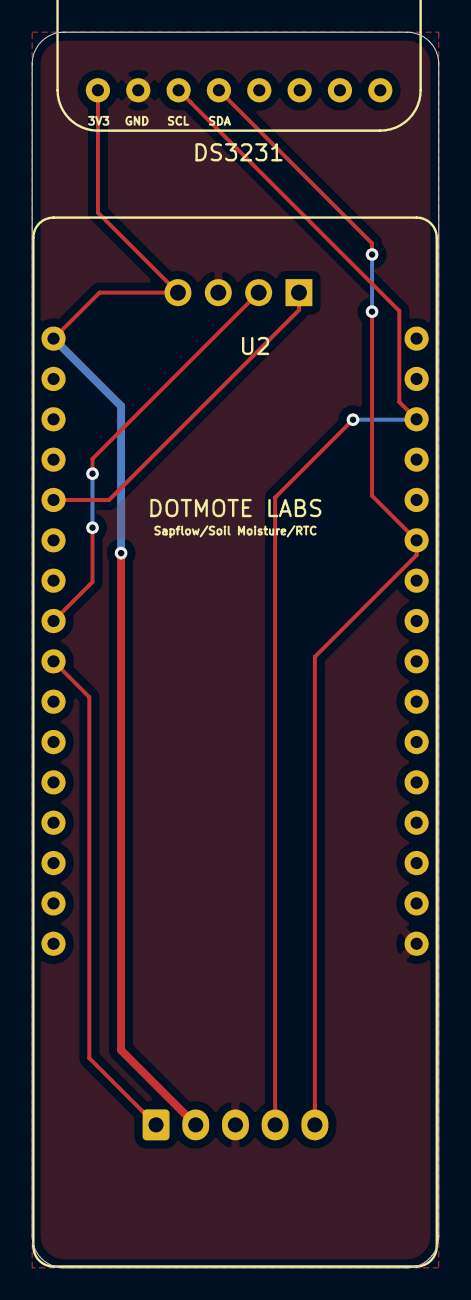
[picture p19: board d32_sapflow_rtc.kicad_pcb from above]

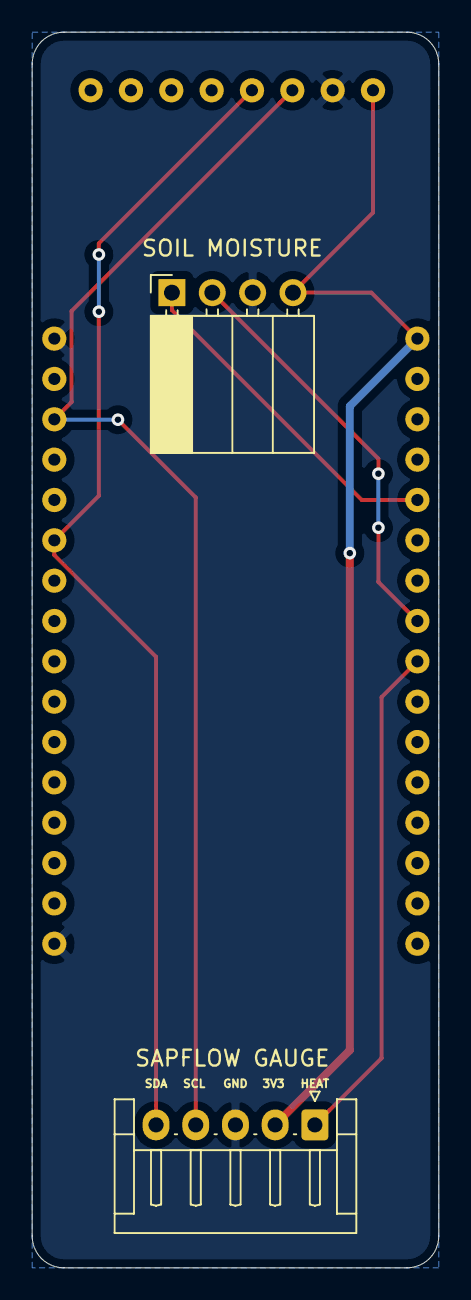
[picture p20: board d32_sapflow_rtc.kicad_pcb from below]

Board: 2 copper layers, 25.6 x 77.8 mm, 4 parts (2 on the bottom side), 7 nets.

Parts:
SAPFLOW GAUGE: sapflow_gauge_5_pin; JST_EH_S5B-EH_1x05_P2.50mm_Horizontal
SOIL MOISTURE: soil_moisture_4_pin; PinSocket_1x04_P2.54mm_Horizontal
U2: d32_pro
U4: adafruit_ds3231

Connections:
+3V3: SAPFLOW GAUGE.2, SOIL MOISTURE.4, U2.1, U4.1
GND: SAPFLOW GAUGE.3, SOIL MOISTURE.3, U2.17, U2.32, U4.2
unnamed: SOIL MOISTURE.1, U2.5
unnamed: SOIL MOISTURE.2, U2.8
unnamed: SAPFLOW GAUGE.1, U2.9
unnamed: SAPFLOW GAUGE.5, U2.27, U4.4
unnamed: SAPFLOW GAUGE.4, U2.30, U4.3

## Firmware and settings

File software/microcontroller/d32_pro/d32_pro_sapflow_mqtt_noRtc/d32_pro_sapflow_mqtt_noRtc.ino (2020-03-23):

uint32_t rtcUnixTimestamp;

// Deep sleep
#define uS_TO_S_FACTOR 1000000 /* Conversion factor for micro seconds to seconds */
#define TIME_TO_SLEEP 1800     /* Time ESP32 will go to sleep (in seconds). 1800 seconds = 30 minutes */
#include "driver/adc.h"

// Wifi
#include <WiFi.h>

const char *ssid = "wifi name";
const char *password = "wifi password";

WiFiClient wifiClient;

// MQTT
// NOTE: PubSubClient by default allows for a max packet size of 128 bytes. Edit PubSubClient.h to increase the max to 512.
#include <PubSubClient.h> // Allows us to connect to, and publish to the MQTT broker
#include <ArduinoJson.h>

const char *mqtt_server = "192.168.1.1"; // IP address of MQTT server/broker
const char *mqtt_topic = "sapflow";      // topic for MQTT messages
//const char* mqtt_username = "user"; // username for MQTT server/broker
//const char* mqtt_password = "pass"; //password for MQTT server/broker

PubSubClient client(mqtt_server, 1883, wifiClient); // 1883 is the listener port for the Broker

// NOTE: make sure that each clientID is unique. Your MQTT broker likely won't allow multiple clients
// to connect using the same clientID.
const char *clientID = "1";

// E-Paper Display
#include <LOLIN_EPD.h>
#include <Adafruit_GFX.h>

#define EPD_CS 14
#define EPD_DC 27
#define EPD_RST 33                                             // can set to -1 and share with microcontroller Reset! Must be set to pin 33 to work with lolin cable
#define EPD_BUSY -1                                            // can set to -1 to not use a pin (will wait a fixed delay)
LOLIN_IL3897 EPD(250, 122, EPD_DC, EPD_RST, EPD_CS, EPD_BUSY); //hardware SPI

// temperature sensors
#include <HDC2080.h>

#define ADDR 0x40
#define ADDR2 0x41
HDC2080 sensor(ADDR);
HDC2080 sensor2(ADDR2);

#define HEAT_PIN_SWITCH 26

// SHT30 temp/humidity sensor
#include <WEMOS_SHT3X.h>

SHT3X sht30(0x45);

// Soil moisture sensor
#define SOIL_MOISTURE_PIN 34

unsigned long tempSensorTimer = 0;

//Using millis instead of delay
unsigned long currentMillis;
unsigned long previousMillis = 0;

//Counter for millis since heat pulse was fired
unsigned long millisSinceHeatPulse = 0;

//Internal counter for starting/stopping heat pulse
unsigned long millisStartHeatPulse = 0;

//Millis value for last time heater was turned on
unsigned long previousHeaterOnTime = 0;

//Counter for millis since we started tracking reference temperatures
unsigned long millisStartReferenceTemp = 0;

unsigned long millisSinceReferenceTemp = 0;

boolean referenceTempRecorded = false;

float temp1;
float temp2;
float outsideTemp;
float outsideHumidity;
int soilMoisture;

long lastMqttReconnectAttempt = 0;
long lastWifiReconnectAttempt = 0;

boolean displayedWifiStatus = false;

boolean reconnect()
{
  if (client.connect(mqtt_topic))
  {
    Serial.println(F("Reconnected to MQTT broker!"));
    EPD.clearBuffer();
    EPD.print("Reconnected to MQTT broker on topic: ");
    EPD.println(mqtt_topic);
    EPD.display();
  }
  return client.connected();
}

void enterDeepSleep()
{
  Serial.println(F("Entering deep sleep"));
  adc_power_off();
  esp_deep_sleep_start();
}

void print_wakeup_reason()
{
  esp_sleep_wakeup_cause_t wakeup_reason;

  wakeup_reason = esp_sleep_get_wakeup_cause();

  switch (wakeup_reason)
  {
  case ESP_SLEEP_WAKEUP_EXT0:
    Serial.println("Wakeup caused by external signal using RTC_IO");
    break;
  case ESP_SLEEP_WAKEUP_EXT1:
    Serial.println("Wakeup caused by external signal using RTC_CNTL");
    break;
  case ESP_SLEEP_WAKEUP_TIMER:
    Serial.println("Wakeup caused by timer");
    break;
  case ESP_SLEEP_WAKEUP_TOUCHPAD:
    Serial.println("Wakeup caused by touchpad");
    break;
  case ESP_SLEEP_WAKEUP_ULP:
    Serial.println("Wakeup caused by ULP program");
    break;
  default:
    Serial.printf("Wakeup was not caused by deep sleep: %d\n", wakeup_reason);
    break;
  }
}

void setup()
{

  Serial.begin(115200);
  while (!Serial)
    ;

  Serial.print("compiled: ");
  Serial.print(__DATE__);
  Serial.println(__TIME__);

  esp_sleep_enable_timer_wakeup(TIME_TO_SLEEP * uS_TO_S_FACTOR);
  print_wakeup_reason();

  EPD.begin();
  EPD.clearBuffer();
  EPD.fillScreen(EPD_WHITE);

  EPD.setCursor(10, 10);
  EPD.setTextColor(EPD_BLACK);
  EPD.setTextWrap(true);
  EPD.print("Connecting to ");
  EPD.print(ssid);
  EPD.println("...");
  EPD.display();

  Serial.print("Connecting to ");
  Serial.println(ssid);

  WiFi.begin(ssid, password);

  while (WiFi.status() != WL_CONNECTED)
  {
    delay(500);
    Serial.print(".");
  }

  displayedWifiStatus = true;

  EPD.clearBuffer();
  EPD.println("Wifi connected");
  EPD.println("IP address: ");
  EPD.println(WiFi.localIP());
  EPD.display();

  Serial.println("");
  Serial.println("WiFi connected");
  Serial.println("IP address: ");
  Serial.println(WiFi.localIP());

  EPD.clearBuffer();
  EPD.println("Connecting to MQTT broker...");
  EPD.display();

  // Connect to MQTT Broker
  // client.connect returns a boolean value to let us know if the connection was successful.
  // If the connection is failing, make sure you are using the correct MQTT Username and Password
  // if (client.connect(clientID, mqtt_username, mqtt_password)) {
  if (client.connect(clientID))
  {
    EPD.clearBuffer();
    EPD.print("Connected to MQTT broker on topic: ");
    EPD.println(mqtt_topic);
    EPD.display();
    Serial.println("Connected to MQTT Broker!");
  }
  else
  {
    Serial.println("Connection to MQTT Broker failed...");
  }

  // Set heat pin as an output
  pinMode(HEAT_PIN_SWITCH, OUTPUT);
  // Set heat pin low to begin with
  digitalWrite(HEAT_PIN_SWITCH, LOW);

  // Initialize I2C communication
  sensor.begin();
  sensor2.begin();

  // Begin with a device reset
  sensor.reset();
  sensor2.reset();

  // Configure Measurements
  sensor.setMeasurementMode(TEMP_AND_HUMID); // Set measurements to temperature and humidity
  sensor2.setMeasurementMode(TEMP_AND_HUMID);
  sensor.setRate(ONE_HZ); // Set measurement frequency to 1 Hz
  sensor2.setRate(ONE_HZ);
  sensor.setTempRes(FOURTEEN_BIT);
  sensor2.setTempRes(FOURTEEN_BIT);
  sensor.setHumidRes(FOURTEEN_BIT);
  sensor2.setHumidRes(FOURTEEN_BIT);

  //begin measuring
  sensor.triggerMeasurement();
  sensor2.triggerMeasurement();
}

void loop()
{
  if (WiFi.status() == WL_CONNECTED)
  {
    if (!displayedWifiStatus)
    {
      displayedWifiStatus = true;
      EPD.clearBuffer();
      EPD.print("Reconnected to wifi network: ");
      EPD.println(ssid);
      EPD.display();
    }

    // if wifi connected, then check for MQTT connection and reconnect, if needed
    if (!client.connected())
    {
      long now = millis();
      if (now - lastMqttReconnectAttempt > 5000)
      {
        lastMqttReconnectAttempt = now;
        // Attempt to reconnect
        if (reconnect())
        {
          lastMqttReconnectAttempt = 0;
        }
      }
    }
    else
    {
      // MQTT client connected
      client.loop();
    }
  }
  else
  {
    if (millis() - lastWifiReconnectAttempt > 5000)
    {
      lastWifiReconnectAttempt = millis();
      if (displayedWifiStatus != false)
      {
        displayedWifiStatus = false;
        EPD.clearBuffer();
        EPD.print("Wifi connection down. Attempting to reconnect to: ");
        EPD.println(ssid);
        EPD.display();
      }

      int WLcount = 0;
      int UpCount = 0;

      WiFi.begin(ssid, password);

      while (WiFi.status() != WL_CONNECTED && WLcount < 200)
      {
        delay(100);
        Serial.printf(".");

        if (UpCount >= 60) // keep from scrolling sideways forever
        {
          UpCount = 0;
          Serial.printf("\n");
        }
        ++WLcount;
      }
    }
  }

  currentMillis = millis();

  //start reading temperature for baseline reference check
  if (digitalRead(HEAT_PIN_SWITCH) == LOW && millisStartReferenceTemp == 0)
  {
    Serial.println(F("Starting to read reference temperatures..."));
    millisStartReferenceTemp = currentMillis;
  }

  if (digitalRead(HEAT_PIN_SWITCH) == LOW && currentMillis - millisStartReferenceTemp >= 10000 && previousHeaterOnTime == 0)
  {
    previousMillis = currentMillis;
    millisStartHeatPulse = currentMillis;
    Serial.println(F("Done reading reference temperatures. Turning heating element on."));
    digitalWrite(HEAT_PIN_SWITCH, HIGH);
    Serial.println(F("Heater ON"));
    previousHeaterOnTime = currentMillis;
  }
  //turn on heating element every 30 minutes
  else if (digitalRead(HEAT_PIN_SWITCH) == LOW && currentMillis - millisStartReferenceTemp >= 1800000)
  {
    previousMillis = 0;
    previousHeaterOnTime = 0;
    millisStartReferenceTemp = 0;
  }

  //turn off heating element after it has been on for >= 20 seconds
  if (digitalRead(HEAT_PIN_SWITCH) == HIGH && currentMillis - millisStartHeatPulse >= 20000)
  {
    digitalWrite(HEAT_PIN_SWITCH, LOW);
    Serial.println(F("Heater OFF"));
  }

  millisSinceHeatPulse = currentMillis - previousHeaterOnTime;
  millisSinceReferenceTemp = currentMillis - millisStartReferenceTemp;

  // uncomment to enter deep sleep after 3 minutes of operation
  //  if (millisSinceHeatPulse > 180000) {
  //    enterDeepSleep();
  //  }

  if (millis() - tempSensorTimer >= 1000)
  {
    tempSensorTimer = millis();
    temp1 = sensor.readTemp();
    Serial.print("Sensor 1 Temperature (C): ");
    Serial.print(temp1);
    temp2 = sensor2.readTemp();
    Serial.print(" Sensor 2 Temperature (C): ");
    Serial.print(temp2);
    Serial.print(F(" clientID: "));
    Serial.println(clientID);
    Serial.print(F("millisSinceHeatPulse: "));
    Serial.println(millisSinceHeatPulse);
    soilMoisture = analogRead(SOIL_MOISTURE_PIN);
    Serial.print(F("Soil Moisture: "));
    Serial.println(soilMoisture);
    //    EPD.clearBuffer();
    //    EPD.setCursor(10, 10);
    //    EPD.setTextColor(EPD_BLACK);
    //    EPD.setTextWrap(true);
    //    EPD.print("temp1: ");
    //    EPD.println(temp1);
    //    EPD.print(" temp2: ");
    //    EPD.println(temp2);
    if (sht30.get() == 0)
    {
      outsideTemp = sht30.cTemp;
      outsideHumidity = sht30.humidity;
      Serial.print("Outside Temperature in Celsius : ");
      Serial.println(outsideTemp);
      Serial.print("Relative Humidity : ");
      Serial.println(outsideHumidity);
      Serial.println();
      //      EPD.print("Outside Temp: ");
      //      EPD.println(outsideTemp);
      //      EPD.print("Outside Humidity: ");
      //      EPD.println(outsideHumidity);
    }
    else
    {
      Serial.println("Error reading SHT30 sensor");
    }
    //    EPD.display();
    rtcUnixTimestamp = millis();
    sendTx(temp1, temp2, millisSinceHeatPulse, outsideTemp, outsideHumidity, soilMoisture, rtcUnixTimestamp, millisSinceReferenceTemp);
  }
}

void sendTx(float temp1, float temp2, unsigned long millisSinceHeatPulse, float outsideTemp, float outsideHumidity, int soilMoisture, uint32_t rtcUnixTimestamp, unsigned long millisSinceReferenceTemp)
{
  StaticJsonDocument<512> doc;

  doc["id"] = clientID;
  doc["rtcUnixTimestamp"] = rtcUnixTimestamp;
  doc["temp1"] = temp1;
  doc["temp2"] = temp2;
  doc["millisSinceHeatPulse"] = millisSinceHeatPulse;
  doc["outsideTemp"] = outsideTemp;
  doc["outsideHumidity"] = outsideHumidity;
  doc["soilMoisture"] = soilMoisture;
  doc["millisSinceReferenceTemp"] = millisSinceReferenceTemp;

  char buffer[512];

  size_t n = serializeJson(doc, buffer);
  client.publish(mqtt_topic, buffer, n);
  Serial.print("Sent mqtt message: ");
  Serial.println(buffer);
  Serial.println("To topic: ");
  Serial.println(mqtt_topic);
}

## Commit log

2019-12-27 initial release
    [DMB0006A.stp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]
2020-01-24 add gerbers for sapflow gauge; update silkscreen
    [sapflow_gauge-B_Cu.gbr, sapflow_gauge-B_Mask.gbr, sapflow_gauge-B_Paste.gbr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]
2020-01-24 add esp32 arduino IDE boards manager URL
2020-01-28 add d1 mini arduino code
2020-02-04 add instructions for creating a data directory in the raspberry pi
2020-02-10 add d1 mini shield
    [d1_mini_lite_sapflow_ti-B_Cu.gbr, d1_mini_lite_sapflow_ti-B_Mask.gbr, d1_mini_lite_sapflow_ti-B_Paste.gbr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]
2020-02-17 add csv aggregator script for merging CSVs
    [1_1563433200_sampleData.csv, 1_1563436800_sampleData.csv, 2_1563433200_sampleData.csv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]
2020-02-17 add human readable timestamp for raspberry pi receiving mqtt datapoints
2020-02-28 Heat-ratio-validation script
2020-03-25 functional prototype of web server dashboard
2020-03-26 add mqtt device simulator
2020-03-26 refactor timeReceived
2020-03-27 fix device simulator logic
2020-03-29 refactor mqtt device simulator; add logging
2020-04-05 add heat ratio processing script
    [aggregated_1586033609056.csv]
2020-05-06 track build directory
2020-12-08 Bump fast-csv in /software/edge_compute_node/raspberry_pi/mqtt_nodejs
    Bumps [fast-csv](https://github.com/C2FO/fast-csv/tree/HEAD/packages/fast-csv) from 2.5.0 to 4.3.6.
    - [Release notes](https://github.com/C2FO/fast-csv/releases)
    - [Changelog](https://github.com/C2FO/fast-csv/blob/master/packages/fast-csv/CHANGELOG.md)
    - [Commits](https://github.com/C2FO/fast-csv/commits/v4.3.6/packages/fast-csv)
2020-12-16 Data files for four nodes
    [sapflow-dotmote-labs-2_2020-10-07_to_2020-12-07.csv, sapflow-dotmote-labs-3_2020-10-07_to_2020-12-07.csv, sapflow-dotmote-labs-4_2020-10-07_to_2020-12-07.csv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]
2020-12-16 Bump bl in /software/edge_compute_node/raspberry_pi/mqtt_nodejs
    Bumps [bl](https://github.com/rvagg/bl) from 1.2.2 to 1.2.3.
    - [Release notes](https://github.com/rvagg/bl/releases)
    - [Commits](https://github.com/rvagg/bl/compare/v1.2.2...v1.2.3)
2021-02-09 Test the ET ~SV relationship
    [AWN_Data_View_15_Chelan.csv]
2021-02-12 Data for Seattle ET
    [AWN_Data_View_15_Seattle.csv]
2021-05-03 Gravi with analysis
    [sapflow-usda-10_2021-04-16_to_2021-05-01.csv, sapflow-usda-7_2021-04-16_to_2021-05-01.csv, sapflow-usda-8_2021-04-16_to_2021-05-01.csv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]
2021-05-21 Comparison of flows
